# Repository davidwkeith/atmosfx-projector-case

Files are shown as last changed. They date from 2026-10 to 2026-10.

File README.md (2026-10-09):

# AtmosFX projector case

Parametric [OpenSCAD](https://openscad.org) design for a ground-standing, rain-proof (not sealed), ventilated case that holds a mini projector and a Raspberry Pi 3 running an [AtmosFX](https://atmosfx.com) Halloween effect.

**Status: v0.10 (unreleased), design only. Nothing has been printed or wired yet.** Dimensions assume a typical mini projector (about 171 x 134 x 75 mm, 0.72 kg). Measure yours and edit the parameters before printing.

## Features

- Anchors: sealed stake tubes inside the four corners take 8 mm tent stakes, driven from inside with the lid off. With the lid screwed on (use security screws) they can't be pulled, which deters theft and holds the case against wind.
- Sits on the ground on eight 6 mm ribs running front to back (the outer two under the side walls); the channels between them drain rain and carry the speaker wire.
- Projector rides on an internal ball head (pedestal takes a 1/4-20 stud). Usable aim +/-10 deg pan and +/-11 deg tilt, +/-8 deg both at once, with the image clearing the window (checked by `scripts/check_clash.sh` for the Tkisko TO2's 0.95:1 throw). For more, turn the whole case or shim its feet.
- Aim hatch on the left wall, a 45 deg diamond so it prints without supports. Tool-free, unless you fit the optional lock screw for public-facing setups: lift the cover about 8 mm off its four keyholes, loosen the ball head, aim, lock. Lid stays on.
- Sloped lid with no holes in the roof (it screws on through the side skirt), a front visor, drip lip and a 45 deg scarf joint at the seam (the front half laps over the rear like a shingle); 45 deg louvers shed rain. Cooling is passive: the projector's own fan draws air in through a louver bank on the right wall's rear and out through one at its front, with a lip baffle between them, and one more louver vents the Pi zone; every bank is insect-screened. The Pi watches its own temperature and switches the projector off at a critical temperature.
- Acrylic lens window in a rebate, held by a printed frame.
- Pi compartment behind a divider. The Pi rides on a removable sled: one per generation (Pi 3B/3B+, 4B, 5, Zero 2 W), located by two floor pins and held by one M3 thumbscrew. Lid off, shelf out, sled lifts out. A pass-through in the divider, open down to the sled, takes a straight HDMI plug from the Pi (the cable loops under the projector) and the projector power lead.
- One supply: a 24 V 5 A desktop brick lies on the power shelf. A standard molded AC cord comes in through a rear-wall opening closed by a two-piece printed clamp (`cord_clamp`) and plugs into the brick, so nothing is hand-wired on the AC side. A Y-splitter feeds the projector (once bring-up shows it runs on 24 V, otherwise through a buck converter to 21 V) and the Raspberry Pi DigiAMP+ HAT, which powers the Pi.
- DMX: the Pi is a first-class E1.31/sACN fixture (8 channels: power, mode, clip, scare trigger, volume, mute, dimmer, reserved), so xLights, Falcon Player, Vixen or QLC+ can run it as part of a show. DMX takes over while its signal is present; the schedule, Home app and web page take back control when it stops.
- Motion sensor: an HC-SR501-style PIR looks out the rear wall (toward people approaching from the street) under a 45 deg rain hood, for startle scares. A remote sensor on a cable can come in through the floor chimney instead. Scares can also be fired from any Apple Home automation.
- Sound: the DigiAMP+ (stereo class D, 12-24 V) sits on the Pi and drives speakers placed behind the projection over ordinary speaker wire. The wire leaves through a chimney in the floor, which stands 15 mm above the floor so water can't reach it, then runs out under the case between the feet.
- Front/rear split so every piece fits a 250 x 210 x 210 mm bed (Prusa MK3S).

## Build

```sh
brew install --cask openscad@snapshot   # or your OpenSCAD of choice
make parts                              # writes stl/*.stl
scripts/check_clash.sh                  # interference checks (needs python3)
```

CI builds the STLs, runs the interference checks and runs the Pi tests on every push (Actions > Build STLs; STLs are under artifacts). A `v*` tag also builds the Pi image and attaches everything to a GitHub Release.

Preview in OpenSCAD: open `projector_pi_case.scad`, set `part` and `tile` in the Customizer. `part = "assembly"` shows everything with ghosted projector and ball head. On iOS, the [OpenSCAD Playground](https://github.com/openscad/openscad-playground) works in Safari.

## Repository layout

- `projector_pi_case.scad` - the model (all parts via `part` / `tile`)
- STLs and the Pi image: download them from the repository's Releases (CI builds and attaches them for each version tag), or run `make parts` to write the STLs to `stl/`. Flashing the image: `pi/README.md`, Install.
- `docs/` - design log, [printing plan](docs/PRINTING.md), [bill of materials](docs/BOM.md), [assembly](docs/ASSEMBLY.md), [wiring](docs/WIRING.md), [aiming](docs/AIMING.md)
- `preview/` - renders of the assembly, interior, aim hatch and power shelf
- `scripts/` - `check_clash.sh`, `render_previews.sh`, `publish.sh`
- `docs/DESIGN_LOG.md` - decisions, dead ends, references
- `CLAUDE.md` - context for Claude Code (`cd` here and run `claude`)

## Parts and print notes

| File | Notes |
|---|---|
| `base_front` | 231 x 207 mm: lies flat as exported, wide side along the 250 mm bed axis; no skirt |
| `base_rear` | Pi compartment. Joins `base_front` with 4x M3 x 12 screws through the divider into its collars; silicone the joint faces |
| `lid_front`, `lid_rear` | Already flipped roof-down; `lid_front` (228 x 204 mm) lies flat as exported. Seal the scarf joint with silicone |
| `window_frame` | Holds the acrylic pane |
| `pedestal` | Screws to the floor bosses; carries the ball head |
| `hatch_cover` | Print ribs-up |
| `power_shelf` | Holds the brick: strap, zip-tie and wire slots |
| `cord_clamp` | Two halves; clamps the AC cord's jacket at the rear-wall opening (M3 x 16 into the bosses, foam gasket) |
| `exhaust_cap`, `intake_cap`, `vent_cap` (print 1 each) | Insect-screen caps for the three right-wall louver banks (exhaust, rear inlet, Pi vent). Glue screen inside the plate, then screw on with 2x M2 |
| `ir_holder` | Only for the relay + IR projector-power fallback. Stick it near the projector's IR receiver with VHB tape |
| `sled_pi3`, `sled_pi4`, `sled_pi5`, `sled_zero2w` | Print the one for your Pi. The name is engraved on the plate |

Everything prints without slicer supports. The window opening has two thin snap-out ribs that hold up its top edge while printing; break them out afterwards.

Material: PETG or ASA, not PLA. Colour: Disney's ["Go Away Green"](https://en.wikipedia.org/wiki/Go_Away_Green), the muted grey-green the parks use to make infrastructure disappear. It's a family of shades with no published spec, so choose a matte sage or olive grey-green by eye against the spot where the case will sit. ASA holds its colour better in sun than PETG. Test first: print `pedestal` and `window_frame`, then `hatch_cover`, before the big tiles.

## Bill of materials

Full list with quantities: [docs/BOM.md](docs/BOM.md). Assembly order: [docs/ASSEMBLY.md](docs/ASSEMBLY.md).

## Aiming

1. Set the case roughly toward the target.
2. Lift the hatch cover about 8 mm and pull it off, loosen the ball head lock, move the projector while watching the image, lock it.
3. Hang the cover back on.

Full steps, aim limits and troubleshooting: [docs/AIMING.md](docs/AIMING.md).

## Power and safety

Mains is still inside a printed box (the cord's connector and the brick's inlet), but nothing is hand-wired. Feed it from a GFCI outlet, leave a drip loop below the clamp, prove the clamp takes the pull (BRINGUP row 17a) before the lid goes on, keep every plug joint in a weatherproof box and off the ground, and use PETG or ASA (V-0 PETG for the shelf). The brick must be UL/ETL listed: check its label. Accepted by the owner (2026-10-08): no AC fuse, no barrier, and a cord that is not outdoor-rated, for the Halloween 2026 run (about a month outside) and replaced if damaged. Do not connect the projector to the 24 V brick until BRINGUP row 4a passes. If you are not comfortable with mains, have someone qualified do that part. The case is rain-shedding and ventilated, not waterproof or certified. Wiring diagrams, wire gauges and a pre-power-up checklist: [docs/WIRING.md](docs/WIRING.md).

## Roadmap

- Print and fit-check the small parts, then the tiles
- Confirm real projector dimensions, lens position, socket position and vent locations
- Re-measure louver openings against the real projector vents

## Changelog

- v0.9 (unreleased): sized to the Tkisko TO2 (lens on the long face, 0.95 throw), front tiles print end-on, pan and combined-aim limits, receptacle plate on the power shelf for the stock wall-wart plus a second one (the brick cradle is gone), gland beside the plate, Pi zone 85 mm, wall-wart clash check
- v0.8: light-cone check, taller 4 x 5 in window set high for upward tilt, shorter visor, skirt notch, plug clearance behind the projector, fit-test coupon, interior stake tubes, lid screws moved from the roof to the skirt sides, screwed base seam, insect-screen caps, second fan for the Pi/brick zone, shelf vents, support-free printing (ribbed floor, diamond hatch, snap-out window ribs, gabled pass-through), IR LED holder, rear-wall PIR mount, Pi sleds for 3B/3B+/4B/5/Zero 2 W, audio (Amp4 HAT, floor chimney for speaker wire, shelf raised 5 mm), 3 x 5 in stock acrylic pane (wider window), AC gland above the shelf, taller barrier, keyholes flipped to lift off, lid scarf joint and gasket land, larger front/rear gaps so the aim range actually clears
- v0.7: DC brick inside on the power shelf, barrier, heat louvers
- v0.6: low-voltage DC splice, zip-tie shelf
- v0.5: single power cord, power shelf on ledges
- v0.4: quick-aim hatch, floor intake, rain hood
- v0.3: resized for a real mini projector, front/rear split
- v0.2: ground-standing, ball-head pedestal
- v0.1: first parametric sketch

## License

Designs, STLs and documentation: [CERN Open Hardware Licence Version 2 - Strongly Reciprocal](LICENSE) (CERN-OHL-S-2.0). Software in `pi/`: [MIT](pi/LICENSE).

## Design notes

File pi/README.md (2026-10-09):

# VideoFX: the Pi side of the projector case

Raspberry Pi software for the projector case. The sled can be a Pi 3B/3B+, 4B, 5 or Zero 2 W, each with a Raspberry Pi DigiAMP+ amplifier HAT. The Pi shows up in Apple Home (or any Matter controller) as **VideoFX-XXXX**:

- **Loop mode** plays a playlist full screen, over and over, for example the AtmosFX videos you bought.
- **Scare mode** loops a calm clip, and on a trigger plays a scare clip, then goes back to the calm clip. A trigger can be a Home automation, the PIR motion sensor, DMX or the web page.

It also:

- switches the projector over HDMI-CEC, a relay (plus IR) or the HDMI signal;
- follows a weekly schedule with "on at sunset";
- takes DMX over sACN from show software;
- watches the Pi's own temperature and switches the projector off if it overheats (the projector's fan does the case cooling).

A web page on your LAN (`http://videofx-xxxx.local/`) handles videos, the playlist, scare clips, the schedule and every setting.

**Status: untested on hardware.** The logic is unit tested (464 tests). The whole service was run on a Mac against a fake mpv, with real UDP sACN. Nothing has run on a Pi, the image has not been built, and nothing has been paired with Apple Home. See [What is verified](#what-is-verified).

## How it works

- **Names.** On first boot each Pi names itself from the last 4 hex digits of its MAC (eth0, or wlan0 on a Zero 2 W). The display name is `VideoFX-ABCD`: Matter, page title, Bonjour. The hostname is `videofx-abcd` (`videofx-abcd.local`).
- **Matter endpoints**, from [matter.js](https://github.com/matter-js/matter.js) 0.17.9 on Node 24:
  1. **Projector** (On/Off plug): the main power.
  2. **Scare** (On/Off plug): turning it on fires a scare. It stays on while the scare plays, then turns itself off. If the scare can't fire (off, not in scare mode, cooling down) it goes straight back off.
  3. **Motion** (Occupancy sensor, PIR): so Home automations can use the PIR.
  4. **Temperature** (Temperature sensor): the Pi's SoC temperature, so Home can alert on it.
- **Player.** One long-lived **mpv** with DRM/KMS output and no desktop, controlled over its JSON IPC socket (`/run/videofx/mpv.sock`). Changing videos is a playlist command, not a process restart, so there is no black gap. If mpv crashes it is restarted; after more than 5 crashes in a minute the service gives up and reports "off". Off means mpv stops (it idles and releases the screen) and the console is cleared to black. Until the Pi is paired, the console shows the pairing QR code.
- **Who controls the power.** Matter, the web page, the schedule and the restore-after-power-cut all go through one path. While a DMX source is live, only DMX may change the power (see [DMX](#dmx-sacn)). Thermal protection can always switch off.
- **Services.** `videofx-player.service` runs `/opt/videofx/src/main.js` as an ordinary user: `videofx` on the release image, your login user with `pi/config` or `install.sh`. It has the groups video, render, audio, tty and gpio, and `CAP_NET_BIND_SERVICE` for port 80. It never runs as root. `videofx-hostname.service` runs on first boot only. Avahi publishes the name and the web page.

## Supported boards

One arm64 image and one `install.sh` cover all four sleds. pi-gen installs both kernels (`linux-image-rpi-v8` and `linux-image-rpi-2712`), and the firmware picks the right one.

| Board | Projector on | DRM connector | Decoding | DigiAMP+ powering the Pi |
|---|---|---|---|---|
| Pi 3B / 3B+ | the only HDMI port | `HDMI-A-1` | H.264 in hardware up to 1080p30 (V4L2 M2M) | Raspberry Pi: "designed to work with Raspberry Pi 3 and earlier"; 5.1 V at 2.5 A over the header. Not tested here |
| Pi 4B | **HDMI0**, next to USB-C | `HDMI-A-1` | H.264 and HEVC in hardware | Raspberry Pi: on a Pi 4 "or later", use a powered USB hub so the ports add no load. Not tested here |
| Pi 5 | **HDMI0**, next to USB-C | `HDMI-A-1` | **no H.264 hardware decoder**: software (about 10-20% CPU for 1080p24 per Raspberry Pi); HEVC in hardware | 2.5 A is well under the Pi 5's 5 A budget; Raspberry Pi only promises the Pi 3. Not tested; see below |
| Zero 2 W | mini-HDMI | `HDMI-A-1` | as the Pi 3; only 512 MB RAM, so use 720p | any 40-pin board per Raspberry Pi; draws far less. Not tested. Solder a 40-pin header |

Sources: Raspberry Pi's [video playback page](https://github.com/raspberrypi/documentation/blob/master/documentation/asciidoc/computers/os/playing-audio-and-video.adoc) (connector names), its [BCM2712 page](https://github.com/raspberrypi/documentation/blob/master/documentation/asciidoc/computers/processors/bcm2712.adoc) (Pi 5 decoding) and [power supply page](https://github.com/raspberrypi/documentation/blob/master/documentation/asciidoc/computers/raspberry-pi/power-supplies.adoc); Raspberry Pi's [DigiAMP+ product brief](<https://pip-assets.raspberrypi.com/categories/765-raspberry-pi-digiamp/documents/RP-008138-DS-1-digiamp-plus-hat-product-brief.pdf>) (power, dimensions, 0-50 °C operating range), [product page](https://www.raspberrypi.com/products/digiamp-plus/) and [audio HAT docs](https://www.raspberrypi.com/documentation/accessories/audio.html) (Pi model notes, mute GPIO, overlay parameters).

- mpv is pinned to `--drm-connector=HDMI-A-1` (the **Video output** setting), so on a Pi 4B or 5 use **HDMI0**. The option name was checked against the mpv 0.40 manual.
- mpv runs with `--vo=gpu --gpu-context=drm --hwdec=auto-safe`. mpv's docs don't list the Pi's V4L2 decoder in `auto`'s whitelist. If a Pi 3 or Zero 2 W struggles, add `--hwdec=v4l2m2m-copy` under Settings > Advanced (not verified).
- **Pi 5 power is a hardware decision for you.** A Pi 5 wants 5 V/5 A over USB-C PD. The GPIO header can't negotiate PD, and the DigiAMP+ supplies 5.1 V at 2.5 A. If `vcgencmd get_throttled` isn't `0x0` or it reboots under load, use a Pi 4B sled; don't add a second 5 V supply, Raspberry Pi says not to power the Pi's own input while the DigiAMP+ is fitted. The software doesn't work around it.
- **config.txt:** the audio, IR and relay lines are the same on every board and go in `[all]`. Older installs also had overlays for the since-removed fans and temperature sensors; `setup.sh` removes that block.

## Files

```
pi/
  src/main.js          wiring: Matter endpoints, power path, player, projector, DMX, heat, web
  src/config.js        every setting: variable, default, validation, when it applies; GPIO pin checks
  src/settings.js      settings.json store: precedence, password rules, migration
  src/player.js        playback control over mpv IPC: loop, scare mode, clip select, dimmer, mirror
  src/mpv.js           mpv arguments, extra-options allow-list, JSON IPC client, supervisor
  src/display.js       HDMI connector status: playback waits for the projector to appear
  src/schedule.js      weekly schedule, NOAA sunset, scheduler
  src/projector.js     projector power: cec / relay-ir / relay / hdmi-off / none
  src/ir.js            IR codes: validate, learn (NEC decode or raw), send with ir-ctl
  src/gpio.js          relay output via gpioset
  src/pir.js           PIR input via gpiomon
  src/dmx.js           sACN (E1.31) receiver, merge, fixture map, DMX hand-over
  src/thermal.js       SoC temperature watch and over-temperature guard
  src/fsutil.js        durable atomic writes (temp, fsync, rename, fsync dir)
  src/watchdog.js      systemd READY/WATCHDOG pings
  src/system.js        clock sync, Wi-Fi link, power-cut protection status
  src/quiet.js         quiet hours: windows, volume cap, scare gate
  src/backup.js        backup / staged restore
  src/update.js, update-cli.js   version, release lookup and download for videofx-update
  src/media.js, playlist-core.js, web.js, qr.js, screen.js, volume.js
  public/              web page (plain HTML/CSS/JS)
  system/              systemd units, udev rules, avahi service, asound.conf, videofx.default, setup.sh,
                       videofx-storage (+ .service), videofx-maint, videofx-update (+ resume service),
                       NetworkManager/timesyncd/watchdog config
  tools/make-release.sh  release tarball for GitHub Releases
  image/               pi-gen build (build.sh, stage-videofx/)
  dmx/DIY-VideoFX-Player.qxf   QLC+ fixture
  tools/sacn-send.mjs  tiny sACN sender for testing; gen-default.mjs regenerates videofx.default
  test/                Vitest (464 tests), test/fixtures/fake-mpv.mjs
  install.sh, config.example
```

## Install

**Option A: the release image.** Every [release](https://github.com/davidwkeith/atmosfx-projector-case/releases) carries `videofx-<version>-arm64.img.xz` (Raspberry Pi OS Lite 64-bit with the player baked in, built by CI from `pi/image/build.sh --generic`) and `videofx-imager.json`. The image holds no password, SSH key or Wi-Fi; [Raspberry Pi Imager](https://www.raspberrypi.com/software/) (2.0 or newer) puts yours in on first boot through cloud-init, the same way it sets up Raspberry Pi OS trixie:

1. Imager > **App options** > **Content repository** > **Custom URL**: `https://github.com/davidwkeith/atmosfx-projector-case/releases/latest/download/videofx-imager.json`. Imager reloads with "VideoFX projector player" as its only OS.
2. Pick it and the card, then fill in the usual options: user and password, Wi-Fi and country, SSH, locale. The hostname field is ignored: the Pi names itself `videofx-xxxx` anyway.
3. Boot. One extra reboot (storage setup, below), then `videofx-xxxx.local` answers.

Imager's **Use custom** button offers no first-boot options for a plain image file (Imager 2.0 removed them; the repository JSON is the supported way). Without the repository, flash the `.img.xz` with **Use custom**, then edit `user-data` and `network-config` on the card's boot partition before the first boot; both carry commented examples. A Pi booted with no user set up cannot be logged into at all: no password, and the console login is off.

The service runs as the baked-in `videofx` user. Name your Imager user `videofx` to keep one account (Imager then sets its password and SSH key), or pick any other name; both get sudo.

**Option B: build the image yourself.** Your user, password, SSH key and Wi-Fi are baked in, so there is no first-boot setup. Never share this image. You need Docker ([Docker Desktop](https://docs.docker.com/desktop/) on a Mac), git, rsync, uuidgen and node.

```sh
cp pi/config.example pi/config   # user, password, SSH key, Wi-Fi, country; gitignored
pi/image/build.sh                # pi-gen arm64 pinned to one commit; image in pi/deploy/videofx-<version>-arm64.img.xz
pi/image/build.sh --generic      # the public flavour CI builds (no pi/config needed)
```

Flash it with Imager's **Use custom** (no options are offered, none are needed). pi-gen and npm are pinned; Debian and NodeSource packages are whatever is current on build day.

**Fresh card, either way.** Flash the image onto the card and let that card's first boot run: `videofx-storage` grows the root to `ROOT_SIZE_MB` and makes the data partition from the rest, and Pi OS's own grow-to-fill is disabled. Don't copy files onto an existing Pi OS card to "upgrade" it, and don't boot the freshly flashed card in another Pi first. A card whose root already fills it reports `no-space` and runs unprotected; re-flash it.

**Option C: install on stock Raspberry Pi OS Lite (64-bit).**

```sh
scp -r pi/ you@raspberrypi.local:videofx-setup
ssh you@raspberrypi.local 'cd videofx-setup && sudo ./install.sh && sudo reboot'
```

`setup.sh` does the following (both options):

- installs `mpv gpiod v4l-utils alsa-utils avahi-daemon`, plus Node 24 from NodeSource if the system Node is older than 20.19;
- installs the app, udev rules for CEC, lirc, GPIO and fb blank, and the systemd units;
- disables the tty1 login prompt;
- edits `config.txt` (see [GPIO pins](#gpio-pins-and-wiring)). It is idempotent.

## Reliability

The case lives on an outdoor extension cord that will get unplugged.

### Power-cut safety

- **Read-only root.** The system partition runs read-only under an overlay. Changes go to RAM and vanish at reboot, so a power cut can't corrupt the OS.
  - It uses Debian's `overlayroot`, the same mechanism as `raspi-config nonint do_overlayfs` on trixie. That was checked in raspi-config's trixie source.
  - The kernel flag is `overlayroot=tmpfs:recurse=0`. raspi-config uses the default `recurse=1`, which would also make the data partition read-only, so writes to it would vanish at reboot (checked in overlayroot's docs).
  - The overlay needs at least 512 MB of RAM (raspi-config's own limit), so the Zero 2 W just qualifies.
- **Data partition.** `/srv/videofx` is ext4, labelled `videofx-data`. It holds everything that must persist, through bind mounts:
  - `/var/lib/videofx`: settings, Matter pairing, last power state;
  - `~/media`: videos and the playlist;
  - `/var/lib/systemd/timesync`: the saved clock.
- **Mount options:** `noatime,commit=5,errors=remount-ro` in the default `data=ordered` mode, with fsck at boot (fstab pass 2; `fsck.repair=yes` is already on `cmdline.txt`).
  - Why not `data=journal`? Every write here, from us, matter.js or timesyncd, is write-temp-then-rename. `data=ordered` plus ext4's `auto_da_alloc` puts the data on disk before the rename is committed, so a power cut leaves the old file or the new one.
  - `data=journal` would write every multi-GB video upload twice (slower, more SD wear) without adding safety for that pattern.
  - `commit=5` bounds loss to 5 s for anything not fsynced; `errors=remount-ro` stops writing on corruption.
- **Our own writes** (settings.json, player state, playlists, uploads) all go: temp file, fsync, rename, fsync of the folder (`src/fsutil.js`).
- **Sizes.** On first boot `videofx-storage` grows the root partition to `ROOT_SIZE_MB`, makes the data partition from the rest of the card (at least `DATA_MIN_MB`), turns the overlay on and reboots once. Both sizes are in `pi/config`; defaults 6144 and 1024. The image disables Pi OS's own "grow root over the whole card" (`resize` / `rpi-resize`).
- **install.sh on an existing Pi:** Pi OS has usually already grown root over the whole card, and a mounted root can't shrink, so the page reports "no-space" and protection stays off. Fix: flash a fresh card, and before its first boot remove the word ` resize` from `cmdline.txt` on the boot partition. Then run install.sh.
- **OS updates: maintenance mode.**

  ```sh
  sudo videofx-maint on && sudo reboot      # root writable; the page shows a warning banner
  sudo apt update && sudo apt full-upgrade  # or edit /etc/default/videofx, Wi-Fi, ...
  sudo videofx-maint off && sudo reboot     # protected again
  videofx-maint status
  ```

  With the overlay on, edits to `/etc` (including `/etc/default/videofx` and NetworkManager Wi-Fi profiles) are lost at reboot. Use maintenance mode for those, or the web page, whose settings live on the data partition.
- **Logs** are kept in RAM while protected. `journalctl` works until the next reboot.

### Time (no RTC)

The Pi 3, 4 and Zero 2 W have no real-time clock, so after a power cut the clock starts wrong.

- **Gating.** The schedule and sunset don't act until `systemd-timesyncd` has synchronised (it touches `/run/systemd/timesync/synchronized`, per its man page). Until then the page says **"Time not synced"**. When sync arrives, the schedule plans from the real time and doesn't replay what it missed.
- **Monotonic clock.** timesyncd saves the time to `/var/lib/systemd/timesync/clock` and never boots behind it. That file is on the data partition, so it survives the read-only root. This is the built-in equivalent of fake-hwclock, which Pi OS Lite doesn't ship.
- **Servers.** NTP servers from DHCP come first, then `pool.ntp.org`. NetworkManager passes DHCP option 42 to a dispatcher script (`DHCP4_NTP_SERVERS`), which writes a runtime timesyncd drop-in. On UniFi, set it in the network's DHCP options under **NTP Server (Option 42)** ([UniFi DHCP Server](https://help.ui.com/hc/en-us/articles/360012097513-UniFi-DHCP-Server)). The gateway's own address works if it serves NTP.
- **Pi 5 (optional):** it has an RTC. Add the official rechargeable battery on the **J5** connector to keep time across power cuts, and enable charging with `dtparam=rtc_bbat_vchg=3000000` in config.txt ([Raspberry Pi RTC docs](https://github.com/raspberrypi/documentation/blob/master/documentation/asciidoc/computers/raspberry-pi/rtc.adoc)). Don't fit a non-rechargeable cell. The time gate still applies.

### Wi-Fi

- **Power save is off** (NetworkManager `wifi.powersave=2`); it causes latency spikes and missed mDNS/Matter traffic.
- **Ethernet is preferred** when plugged in (route metric 100 vs 600), and Wi-Fi stays up as a fallback.
- The page shows the SSID, signal (dBm and %), a verdict and the band.
- **Bands:** the Pi 3B+, 4B and 5 are dual-band (2.4/5 GHz). The **Pi 3B and Zero 2 W are 2.4 GHz only** ([Raspberry Pi specs](https://github.com/raspberrypi/documentation/blob/master/documentation/asciidoc/computers/raspberry-pi/introduction.adoc)), so the SSID must offer 2.4 GHz.
- **UniFi placement.** An outdoor case sits at ground level, often behind a wall, so give it a real AP view: an outdoor AP or a window-facing one, or Ethernet if you can. Aim for better than **-70 dBm** at the Pi. Ubiquiti's guide calls -60 to -70 acceptable and warns of drops below -80 ([WiFi Troubleshooting Guide](https://help.ui.com/hc/en-us/articles/32064585817495)). Caveats:
  - **Minimum RSSI** disconnects clients below a threshold, and some devices refuse to reconnect after being kicked repeatedly ([Minimum RSSI](https://help.ui.com/hc/en-us/articles/221321728-Understanding-and-Implementing-Minimum-RSSI), [SSID settings](https://help.ui.com/hc/en-us/articles/32065480092951-UniFi-WiFi-SSID-and-AP-Settings-Overview)). Leave it off on the APs that cover the case, or set it well below the Pi's signal.
  - **Band Steering** nudges clients from 2.4 GHz to 5 GHz with BSS transition frames. At the edge of coverage 2.4 GHz often reaches further. If a dual-band Pi keeps hopping, give it a 2.4 GHz-only SSID; a 3B or Zero 2 W ignores steering anyway.

### Hang recovery

- **Hardware watchdog:** `RuntimeWatchdogSec=14s` in `/etc/systemd/system.conf.d/`. systemd pets the Broadcom watchdog, and if the kernel or systemd hangs the board resets. 14 s stays under the chip's roughly 15 s limit.
- **Service watchdog:** `videofx-player` is `Type=notify` with `WatchdogSec=30`. It sends `READY=1` once its own start-up is done (not when Matter comes online: with the Wi-Fi down that may never happen, and systemd would restart it every 2 minutes), then `WATCHDOG=1` every 15 s from the main event loop, but only while healthy. It stops pinging if the loop was blocked for more than 5 s, and systemd then restarts it.
- Node can't write to the notify socket without a native addon, so pings go through `systemd-notify` with `NotifyAccess=all`. Crediting that short-lived helper's message to our unit needs kernel ≥ 6.5 and systemd ≥ 254, which trixie has; on older systems the pings may be lost. At most one helper runs at a time.

### Updates

VideoFX never updates itself, and the web page never touches the network. With the read-only root, updates go through maintenance mode, which `videofx-update` handles:

```sh
sudo videofx-update --check                   # asks GitHub; the page then shows "update available"
sudo videofx-update                           # latest release
sudo videofx-update --tag v0.3.0 --os         # a given release, plus apt full-upgrade
sudo videofx-update --tarball ~/videofx-pi-0.3.0.tar.gz   # no GitHub access needed: scp the tarball over first
sudo videofx-update --rollback                # back to the previous version
```

- **What it does:**
  1. If the root is protected, it records the job and any tarball on the data partition, switches maintenance mode on and reboots. `videofx-update-resume.service` picks the job up after the reboot.
  2. Downloads the release asset `videofx-pi-X.Y.Z.tar.gz` and checks it's VideoFX.
  3. Copies the running version to `/opt/videofx.prev` (with its `node_modules`, so a rollback works offline).
  4. Runs the new release's `system/setup.sh`, which does `apt-get install`, `npm ci --omit=dev`, units and config. Both need the internet, with `--tarball` too.
  5. With `--os`, runs `apt full-upgrade`.
  6. Switches maintenance off and reboots.
  7. If step 4 fails (no network, say), it puts the previous version back, switches protection back on, reboots and exits with an error. It doesn't retry.
- **Private fork:** if your copy of the repo is private, put a GitHub token with read access to its contents (a fine-grained token, "Contents: read") in `/srv/videofx/update/github-token`, mode 600, owned by root. It lives on the data partition so it survives the read-only root. Or use `--tarball`.
- **Making a release:** bump the version in `pi/package.json`, tag `vX.Y.Z` and push the tag. CI (`.github/workflows/build.yml`) attaches the STLs, `videofx-pi-X.Y.Z.tar.gz` (`pi/tools/make-release.sh`), the public image with its `.sha256`, and `videofx-imager.json` (`pi/tools/imager-json.sh`). The image job runs on GitHub's arm64 runner and takes about ten minutes. By hand: `pi/tools/make-release.sh && gh release create vX.Y.Z pi/dist/videofx-pi-X.Y.Z.tar.gz`. The page footer shows the version and sha, and "update available" when the last `--check` found a newer release.

### Backup and restore

Web page > **Backup** > **Download backup**. That's one JSON file with the settings, schedule, quiet hours, playlist, and the Matter storage (fabrics, keys). Videos aren't included; copy those yourself. The file holds the pairing keys and the password hash, so keep it private. When a password is set, downloading needs it.

**Restore:** pick the file, choose whether to include the Matter pairing, confirm. Settings and playlist apply straight away and the service restarts. A restored pairing is swapped in at that restart, and the previous one is kept as `matter.before-restore`.

- Restore the **pairing** only onto the same Pi, or onto a replacement when the old one is gone for good. Two devices with one Matter identity confuse Apple Home and both misbehave.
- To clone settings onto a second VideoFX, restore **without** the pairing and pair the new one separately.

### Guest access

With no password set, the page shows a warning: anyone on your network can control VideoFX and download its pairing keys.

- Set a password, and keep the Pi off networks that guests can reach. On UniFi that means a separate guest network with **Network Isolation** on (Settings > Networks) and, on its SSID, **Client Device Isolation**, as in Ubiquiti's [Guest WiFi best practices](https://help.ui.com/hc/en-us/articles/23948850278295-Best-Practices-Guest-WiFi). Keep VideoFX on your own network with the home hub, since it must share one with Matter.
- Once paired, the page hides the Matter pairing code (Settings > Web page > **Hide the Matter pairing code once paired**, on by default).
- "LAN only" means the usual private ranges plus anything on one of the Pi's own subnets. The second part is for IPv6: on a network with a routed prefix every device has a global address, and iPhones and Macs use it for `videofx-xxxx.local`.
- Password guessing is slowed down: five new guesses, then one a second. A tab that keeps polling with an old password doesn't use them up.
- The service can't write to the home folder apart from the media folder (`ProtectHome=read-only`). If you move the media folder elsewhere under `/home` with `VIDEOFX_MEDIA_DIR`, add a matching `ReadWritePaths=` to the unit.

### Quiet hours

Web page > **Quiet hours**: per weekday, a window (an end earlier than the start runs past midnight; start = end means all day) during which:

- **the volume is capped** at a percentage (0 mutes). The cap applies to the web slider, the saved level at start-up, and DMX (unless **DMX ignores quiet hours** is on). The mixer is re-set when a window starts or ends;
- **scares are off** (optional), whatever the trigger: Home's Scare switch, the motion sensor, the web button, and DMX unless it bypasses.

Power on/off (Home, the schedule) isn't affected. Until the clock is synchronised, quiet hours count as active if any window is set, the neighbour-friendly guess.

## Videos, playlist, scare mode

Your purchased videos are not included or downloaded. Upload them on the web page, or `scp` them to `~/media/` on the Pi.

- **Loop mode:** build the playlist on the page (order, enable/disable, save). Saving while playing reloads it in mpv.
- **Scare mode:**
  1. Upload the calm clip and the scare clips. Files named like `Ghost_Buffer.mp4` and `Ghost_Scare1.mp4` get paired by **Suggest from file names**.
  2. Pick the calm clip and the scare clips in **Scare mode**, and save.
  3. Set Settings > Playback > **Mode** to `scare`.
  4. Tune the order (sequential/random), the cooldown (default 20 s, counted from the end of a scare), and what happens to a trigger during a scare: `ignore` (default) or `queue` (one scare, played after the cooldown).
  5. Trigger with **Scare now**, the **Scare** switch in Home (for example, "when the doorbell rings, turn on Scare"), the PIR, or DMX.
- **The seam.** The calm clip loops with `loop-file=inf`. The next scare clip and the calm clip after it are already queued, so mpv's `--prefetch-playlist` opens them early. A trigger sets `loop-file=no` and sends `playlist-next`. The service measures each seam from mpv's events and logs it (`journalctl -u videofx-player | grep seam`); the page shows it too. **It has not been measured on a Pi:** the Mac test used a fake mpv, whose ~50 ms is its own simulated delay.
- **Recommended encode:** H.264 High, level 4.1 or lower, 1080p30 (720p for the Zero 2 W), 8-bit 4:2:0 MP4, AAC stereo 48 kHz. Re-encode on your computer only if a file stutters:

  ```sh
  ffmpeg -i in.mp4 -vf "scale=-2:'min(1080,ih)',format=yuv420p" -c:v libx264 -profile:v high -level:v 4.1 \
    -preset slow -crf 20 -c:a aac -b:a 160k -ac 2 -ar 48000 -movflags +faststart out.mp4
  ```

  Use `min(720,ih)` and `-level:v 4.0` for the Zero 2 W. For rear projection on a Pi 3 or Zero 2 W, pre-flip the files with `-vf "hflip,scale=..."` instead of using the Mirror setting (below).
- **Mirror** (Settings > Display): flips left-right at once through mpv IPC (`vf add @mirror:hflip`). The flip runs on the CPU, so it switches decoding to `auto-copy`. That's fine on a 4B or 5 and probably too heavy for 1080p on a 3 or Zero 2 W (not measured).

## Schedule

On the page: an on time and an off time per weekday. The on time can be **At sunset**, plus or minus an offset. An off time earlier than the on time means after midnight.

- Sunset is computed on the Pi from Settings > Schedule > Latitude/Longitude, using NOAA's general solar position equations (tested within 5 minutes of published times). Days with no sunset (polar summer or winter) get no on event.
- Times use the Pi's time zone (`sudo raspi-config` > Localisation). Tested across both DST changes: a time in the spring-forward gap fires once, at 03:30; a time in the fall-back hour fires once.
- **The schedule only acts at its event times.** Switching on or off by hand (Home, the page) holds until the next scheduled event. The page shows the next event.
- **After a power cut** the "After a power cut" setting applies first. Then, once the clock is set, an event that passed while the power was out is caught up: a cut across "on at sunset" still gets you a show. A change you made by hand after the last event is left alone.
- A Pi has no real-time clock. Events more than 5 minutes stale, for example after NTP corrects the clock at boot, are skipped rather than replayed.
- While DMX is in control the schedule is paused. When DMX lets go, the schedule's current wish is applied.

## Projector power

Setting: **Projector power** = `cec` (default) | `relay-ir` | `relay` | `hdmi-off` | `none`. The page shows the projector's state and the CEC result.

- **cec.** Uses `cec-ctl` (v4l-utils) on `/dev/cec0`, the kernel's CEC under KMS (HDMI0 on the 4B and 5; the only port on the 3 and Zero 2 W). No libcec daemon, and access is through the video group via udev.
  - On: configure as a playback device, then Image View On, Text View On and Active Source (One Touch Play), then ask for the power status. If the projector isn't "on" yet, the wake is retried once after 8 s.
  - Off: Standby.
  - If the projector never answers, the service falls back to `hdmi-off` with a notice, and tries CEC again at the next power-on. CEC is only used on power changes, never on page polls.
  - **Buying:** many mini projectors have no CEC. Look for "HDMI-CEC" in the projector's own spec. Brand names like Anynet+, SimpLink or Bravia Sync are the TV makers' CEC and don't tell you anything about a projector.
  - **Test** on the Pi: `cec-ctl -d /dev/cec0 --playback -S` shows the CEC devices. `cec-ctl -d0 --to 0 --image-view-on` should wake it.
- **hdmi-off.** Powers the HDMI signal down (fbdev blank) when stopped, once mpv has let go of the display. Many projectors drop to standby after their own no-signal timeout. **Waking may still need the remote.** Before the Pi is paired, the signal stays on so the pairing code is visible.
- **relay / relay-ir.** Fallbacks, built only if CEC fails (BRINGUP row 9). A relay on the projector's DC feed. Off: stop playback, then open the relay. On: close it, wait the settle time (default 3 s), then:
  - `relay`: nothing more, for projectors that power up by themselves.
  - `relay-ir`: send the IR power code (twice if "needs two presses" is set). The relay forces a known "off" first, so the IR toggle can't get out of step. A second "on" while it is already on (the schedule after you switched on by hand, say) doesn't press power again.
  - Either way, playback then waits up to 20 s for the projector to show up on HDMI, and starts again if it appears later. mpv gives a disconnected output no picture.
- **Relay safety:**
  - Use a relay module rated for the projector's DC current, with an opto-isolated input and a flyback diode (most modules have one).
  - Switch the **+ line (high side) only**, and only on the projector's leg. Never switch the projector's ground: the HDMI shield would carry its return current.
  - At boot the firmware drives the relay line to "open" before Linux runs (`gpio=27=op,dh` for active-low modules; use `dl` for active-high). The service keeps it open until it decides.
  - When the service stops, for any reason, the relay opens: the service does it on a clean stop, and `videofx-relay-open` (the unit's `ExecStopPost`) does it after a crash, a kill or the watchdog. The relay never stays closed once the service is gone (the service only watches the Pi's own SoC; the projector has its own thermal cut-off).
  - The relay and IR pins are also in `config.txt`, written once with the defaults. If you change them in `/etc/default/videofx`, change `config.txt` by hand too.
  - Cutting power suits LED mini projectors; don't do it to a lamp projector that needs a cool-down.
- **IR** uses the `gpio-ir-tx` overlay for the LED and `gpio-ir` for a TSOP38238-style receiver, driven with `ir-ctl`.
  - On the page: **Learn power button**, then press the remote's power button at the receiver. The capture is decoded as NEC (`nec`, `necx` or `nec32`, the same scancode forms the kernel's encoder sends) or kept as raw pulse/space data.
  - Or paste a code (`nec:0x40bf`, `rc5:0x1e01`, `raw:+9000 -4500 ...`). **Send test** fires it.
  - `pwm-ir-tx` is allowed (set `VIDEOFX_IR_TX_DRIVER` and use its overlay in `config.txt`): the case has no fans, so hardware PWM0 is free.

## GPIO pins and wiring

**The DigiAMP+ uses GPIO 2 and 3 (I2C), 18-21 (I2S) and 22 (amp mute, driven by the `rpi-digiampplus` overlay)**, per Raspberry Pi's [audio HAT docs](https://www.raspberrypi.com/documentation/accessories/audio.html); [pinout.xyz](https://pinout.xyz/pinout/digiamp_plus) also lists GPIO 4 (GPCLK0), so it stays reserved. The board brings GPIO 17, 23, 24, 25 and 27 to its optional rotary-encoder and IR headers; VideoFX uses those pins, so **leave those headers empty**. GPIO 0/1 are always reserved for the ID EEPROM. That leaves 18 free GPIOs; VideoFX uses 9, so **no expander is needed**. The service refuses two roles on one pin and any DigiAMP+ pin.

| Role | GPIO | Pin | Notes |
|---|---|---|---|
| DigiAMP+ | 2, 3, 4, 18, 19, 20, 21, 22 | 3, 5, 7, 12, 35, 38, 40, 15 | reserved (22 = mute) |
| PIR in | 17 | 11 | setting (live) |
| Relay out | 27 | 13 | file only (boot level in config.txt) |
| IR LED out | 16 | 36 | file only (overlay) |
| IR receiver in | 23 | 16 | file only (overlay) |
| 5 V / 3.3 V / GND | | 2, 4 / 1, 17 / 6, 9, 14, 20, 25, 30, 34, 39 | |

**Reaching the pins.** The DigiAMP+ has a 40-pin pass-through header on top (Raspberry Pi's product page), so the leads above plug straight into it; no stacking header is needed. On the Zero 2 W, which needs a header soldered anyway, leave the pins long.

If you ever need more I/O, an I2C expander (MCP23017) can share GPIO 2/3 with the DigiAMP+'s codec.

**Wiring:**

- **PIR (HC-SR501):** VCC to 5 V (pin 2), GND (pin 9), OUT (3.3 V logic) to GPIO17 (pin 11). Use the retrigger jumper (H), a short hold time, and allow about a minute of warm-up after power-on.
- **Relay module (5 V coil, opto input):** VCC 5 V (pin 4), GND (pin 14), IN to GPIO27 (pin 13). The contacts (COM/NO) go in series with the projector's DC **+** only.
- **IR LED (940 nm), fallback only (built only if CEC fails):** GPIO16 (pin 36; GPIO22 is the DigiAMP+ mute line) drives the LED directly through 150 Ω to GND (about 13 mA at 3.3 V, inside the pin's 16 mA limit). The Pi's default pad drive is 8 mA, so the LED may be dimmer than 13 mA suggests: raise the drive strength, or add the BC337 and 1 k as in WIRING.md.
- **IR receiver (TSOP38238), bench-only (for learning the remote's codes):** VS to 3.3 V (pin 17), GND, OUT to GPIO23 (pin 16). Powering it at 3.3 V keeps its output at 3.3 V.

## Audio

A **Raspberry Pi DigiAMP+** (TAS5756M, 2 channels) drives 4-8 Ω speakers behind the projection. It runs from the Y-splitter's second leg (12-24 V, through its P5 hard-wire header or the 5.5 x 2.5 mm centre-positive barrel jack) and **powers the Pi through the header** at 5.1 V / 2.5 A. Up to 35 W per channel, rated for 0-50 °C ambient ([product brief](<https://pip-assets.raspberrypi.com/categories/765-raspberry-pi-digiamp/documents/RP-008138-DS-1-digiamp-plus-hat-product-brief.pdf>)): the Pi zone has to stay under that with only a passive louver, and the brief says not to cover a case it sits in, which is what the louvers are for (bring-up logs the shelf temperature).

- **Speakers:** speaker wire from the DigiAMP+'s terminals, same polarity on both speakers; the outputs can't be bridged.
- **Power budget:** the brick must supply the projector, the Pi and the amp at once. Check its label.
- **Software:**
  - `dtoverlay=rpi-digiampplus,unmute_amp` (Raspberry Pi's overlay; the HAT EEPROM identifies the board, but the amp starts **muted** until `unmute_amp` or `auto_mute_amp` is set. `iqaudio-digiampplus` is the same overlay for the older black IQaudIO board);
  - `dtparam=audio=off` and `vc4-kms-v3d,noaudio`;
  - ALSA default pinned by card name in `/etc/asound.conf`;
  - mpv uses `--audio-device=alsa/plughw:CARD=RPiDigiAMP,DEV=0` (the card id ALSA derives from the overlay's "RPi DigiAMP+" name; check with `aplay -l`).
- **Volume:** hardware mixer `Digital` via `amixer -M`, saved in settings.json. The first boot starts at 30%.

## Cooling

The case has no fans or temperature sensors: the projector's own fan moves the air through the case's louver banks, and the projector has its own thermal cut-off. The Pi only watches **its own SoC temperature** (`/sys/class/thermal/thermal_zone0`, read every 5 s) and switches the projector off if the Pi itself overheats.

Settings > Cooling:

_Upgrade note: `tempWarnC` / `tempCritC` now refer to the Pi's SoC. A saved `tempCritC` of 55 (the old projector-zone default) would trip during normal operation, so delete the old saved values or set them to 70 / 80._

- **Pi over-temperature protection** (on by default). When off, nothing is checked and nothing is protected.
- **Warning** (default 70 °C, 40-90): banner on the page.
- **Critical** (default 80 °C, 50-95):
  - stops playback and switches the projector off through its configured path, even under DMX;
  - blocks switching on;
  - it switches back on (only if it was on) once the SoC is below critical by the hysteresis.
- **Cool-down before resuming** (default 5 °C, 1-20).
- **What the cut-off can do depends on the projector power mode.** With `relay` or `relay-ir` it cuts the projector's power. With `cec` it asks for standby, which a hung projector can ignore; with `hdmi-off` it only drops the signal; with `none` it only stops playback. The relay is the only way the Pi can really cut the projector's power on over-temperature.
- **A missing reading** (the sysfs file unreadable) changes nothing: no trip, no clear.
- **Matter:** the SoC temperature is endpoint 4.

## DMX (sACN)

VideoFX is a **receive-only 8-channel fixture** over **E1.31 (sACN)**, on Wi-Fi or Ethernet (UDP 5568, unicast and optionally multicast 239.255.hi.lo). Settings > DMX sets: enable, universe (1-63999), start address (1-505), hold time (default 5 s) and accept multicast. The page shows the live sources (name, IP, priority, packet rate) and our 8 values.

| Ch | Function | Values |
|---|---|---|
| 1 | Power | 0-127 off, 128-255 on (same projector power path as Matter) |
| 2 | Mode | 0-127 loop, 128-255 scare |
| 3 | Clip select | 0 = normal (playlist or calm clip); N = playlist entry N, looped |
| 4 | Scare trigger | fires on the rise through 128; the cooldown still applies |
| 5 | Volume | 0-255 → 0-100% |
| 6 | Mute | 128-255 muted |
| 7 | Video dimmer | 0 black … 255 normal (mpv brightness) |
| 8 | Reserved | send 0 |

**Hand-over rules:**

- While any valid source for our universe is live, **DMX owns power, mode, clip, volume, mute and dimmer**.
  - Matter writes are refused, and Matter's attribute is put back to the real state.
  - The page shows "DMX in control" and disables those controls; its power and volume calls get 409.
  - The schedule pauses.
  - DMX values are not saved.
- A source is lost after 2.5 s without data (E1.31 data loss) or at once on Stream_Terminated. After the last source is lost and the hold time passes, control returns:
  - to the schedule's current wish if the schedule is on;
  - otherwise to the power state from before DMX took over.
  - Mode, volume, clip and dimmer go back to their saved settings.
- **Pacing:** power changes at most once a second, mode every 0.5 s, and clip select must hold 300 ms. Volume and dimmer are limited to 10 updates a second.
- **Merging:** highest priority wins; equal top priorities merge highest-takes-precedence per channel. Out-of-order packets are dropped, using ETC's rule: accept if newer, or 20 or more behind. Preview-flagged data and non-zero start codes are ignored.

**Where the E1.31 details come from.** Packet layout, the sequence rule, the 2.5 s timeout, the flags and the universe range were checked against ETC's open-source reference receiver ([ETCLabs/sACN](https://github.com/ETCLabs/sACN)). The ESTA PDF sits behind a terms form and was not read directly.

**Show software:**

- **QLC+:** import `dmx/DIY-VideoFX-Player.qxf` (Fixture Definition Editor, or copy it to your user fixtures folder). It validates against QLC+'s own `fixture.xsd`. Output on E1.31, **unicast** to the Pi's IP.
- **xLights:** Controllers > Add Ethernet, Protocol E1.31, the Pi's **IP address** (unicast), start universe = ours ([xLights manual](https://manual.xlights.org/xlights/chapters/chapter-four-set-up/lighting-networks/ethernet-controller)). Add a DMX model with 8 channels at the start address. The DMX model type's name wasn't verified.
- **Falcon Player:** Channel Outputs > **E1.31 / ArtNet / DDP / KiNet**, add a universe with type **E1.31 Unicast** and the Pi's IP.
- **Manual test:** `node tools/sacn-send.mjs --to <pi-ip> --universe 1 --values 255,0,0,0,76,0,255,0 --seconds 10`. Add `--pulse-trigger` for a scare. It ends with Stream_Terminated.

**Network:** multicast over Wi-Fi is unreliable (converted, rate-limited or dropped by APs), so **send unicast to the Pi's IP**; a fixed IP or DHCP reservation helps. On UniFi, sACN multicast (239.255.x.x) is outside the always-flooded 224.0.0.0/24, so **IGMP Snooping** with "Forward Unknown Multicast" set to Drop can block it, and **Multicast Enhancement** converts it per client ([Switch Settings](https://help.ui.com/hc/en-us/articles/33402927617047-UniFi-Switch-Settings), [WiFi SSID settings](https://help.ui.com/hc/en-us/articles/32065480092951-UniFi-WiFi-SSID-and-AP-Settings-Overview)). Unicast avoids all of that.

## Pair with Apple Home

1. Power on with the projector connected. Until paired, the projector and the web page show the QR code and manual code.
2. On the iPhone (same Wi-Fi as the Pi and your home hub): Home > **+ > Add Accessory**, then scan. If the camera won't read the projector, scan the page or type the 11-digit code.
3. Choose **Add Anyway** at the not-certified warning (test vendor ID 0xFFF1).
4. You get the Projector and Scare switches, a Motion sensor and a Temperature sensor. Name them, and automate, for example: sunset → Projector on; doorbell → Scare on.

To unpair: web page > Matter > **Reset Matter pairing**. Videos and settings are kept.

## Settings

Everything is on the web page under **Settings**. Each setting shows its value, where it comes from (*set here* / *from /etc/default/videofx* / *default*), its default, when it takes effect (at once / next play / after a restart), and a **Reset**.

- **Precedence:** web page (`/var/lib/videofx/settings.json`, written atomically, mode 600) > `/etc/default/videofx` > default. A corrupt settings.json is backed up to `settings.json.corrupt` and ignored, with a warning.
- **Password:** stored as a scrypt hash and never sent back. Changing it needs the current password; removing it needs the current password and a confirmation.
- **Extra mpv options (Advanced):** only `--name=value`, no shell, and only from an allow-list: decoding (`--hwdec`, `--vd-lavc-*`), DRM output (`--vo=gpu|gpu-next|drm`, `--gpu-context`, `--drm-*`, `--drm-device=/dev/dri/cardN`), sync and scaling (`--video-sync`, `--interpolation`, `--scale`, `--deband`, `--video-*`, `--panscan`, picture controls), cache (`--cache*`, `--demuxer-max-bytes`), audio timing (`--audio-delay`, `--audio-buffer`, `--volume-max`, `--alsa-*`), `--profile=fast|sw-fast|high-quality|low-latency`, `--msg-level`, and `--vf` with simple filters (`crop`, `hflip`, `vflip`, `scale`, `pad`, `format`, `fps`, `eq`, `rotate`, `transpose`, `yadif`, `bwdif`). Everything else is refused. A deny-list missed `--ao=pcm --ao-pcm-file=...`, which writes any file the service can.
- **JSON values in `/etc/default/videofx`** (scare clips, schedule, quiet hours) go in single quotes. systemd reads the file, and it drops the quotes inside an unquoted value.
- **File only** (need root, or would let the page point the service anywhere): ports, media folder, playlist path, mpv command, state folder, and the relay and IR pins. Edit `/etc/default/videofx` (every key is listed there, commented) and restart.
- **Migration from the VLC version:** `VIDEOFX_VLC*` in the file and `vlcExtraArgs` in settings.json are ignored, with a warning. VLC options don't translate to mpv; the audio card and video output settings carry over as they are.

### Web page security

- The page answers only private, link-local and ULA addresses.
- The Host header must be an IP, `localhost`, `videofx-xxxx(.local)`, the device name or an extra host name (case-insensitive). This blocks DNS rebinding.
- Every write needs an `X-VideoFX: 1` header (CSRF). The optional password uses basic auth, over plain HTTP.
- Uploads: file names are checked, the size is capped, extensions are limited, and media is never served back.

## UniFi networks

Keep the Pi, the Apple home hub and your iPhone **on the same network (VLAN)**. On the Wi-Fi, turn off **Client Device Isolation** and **Multicast and Broadcast Control** (or add exceptions). Try turning **Multicast Enhancement** off if discovery is flaky. With **IGMP Snooping** on, set **Forward Unknown Multicast Traffic** to flood. Across VLANs you need the gateway's **mDNS Proxy** (add `_matter._tcp.local` in Custom mode) *and* routable IPv6 plus firewall rules for UDP 5540. The Pi sends `videofx-xxxx` as its DHCP hostname.

Sources: [Gateway mDNS Proxy](https://help.ui.com/hc/en-us/articles/12648701398807-UniFi-Gateway-Multicast-DNS-mDNS-Proxy), [Switch Settings](https://help.ui.com/hc/en-us/articles/33402927617047-UniFi-Switch-Settings), [WiFi SSID settings](https://help.ui.com/hc/en-us/articles/32065480092951-UniFi-WiFi-SSID-and-AP-Settings-Overview), [Optimizing WiFi](https://help.ui.com/hc/en-us/articles/221029967-Optimizing-WiFi-Connectivity-and-Reducing-Latency), [Network isolation](https://help.ui.com/hc/en-us/articles/18965560820247-Implementing-Network-and-Client-Isolation-in-UniFi), [Configuring IPv6](https://help.ui.com/hc/en-us/articles/36378535649687-Configuring-IPv6-in-UniFi), [Local DNS records](https://help.ui.com/hc/en-us/articles/15179064940439-UniFi-DNS-Records-and-Local-Hostnames); Apple's [accessory troubleshooting](https://support.apple.com/en-us/126198). help.ui.com blocks scripted fetches, so these were read through its article API; they open normally in a browser.

**mDNS:** matter.js runs its own responder on UDP 5353 (`SO_REUSEADDR`) under a MAC-based name. avahi owns `videofx-xxxx.local` and the `_http._tcp` entry ("VideoFX-XXXX"). They don't share names, so they coexist. A unicast mDNS reply reaches only one of the two sockets; that case is untested.

## Troubleshooting

```sh
journalctl -u videofx-player -f        # everything: player, Matter, DMX, schedule, seams, thermal
cat /var/lib/videofx-name
kmsprint | grep Connector              # HDMI connectors (Pi 5: first card only)
cec-ctl -d /dev/cec0 --playback -S     # is there CEC?
ir-ctl -f -d /dev/lirc0                # IR devices (TX and RX may swap numbers)
aplay -l; amixer -c RPiDigiAMP sget Digital
vcgencmd get_throttled                 # under-voltage (Pi 5 on the DigiAMP+)
```

- **No picture on a 4B or 5:** use HDMI0. **No picture when the projector is powered after the Pi:** playback waits up to 20 s for the HDMI connection and starts again when it appears (`journalctl -u videofx-player | grep HDMI`). If your projector never reports itself connected, add `video=HDMI-A-1:1280x720@60D` to `cmdline.txt`.
- **mpv errors about the DRM device on a Pi 5:** add `--drm-device=/dev/dri/card1` in Settings > Advanced.
- **Stutter on a Pi 3 or Zero 2 W:** re-encode (above), or add `--hwdec=v4l2m2m-copy`.

## License

The software in `pi/` is MIT (see `pi/LICENSE`). The case design in the rest of the repository is CC BY-SA 4.0.

## Development

```sh
cd pi && npm ci && npm test             # Vitest; a few tests bind 127.0.0.1 and a Unix socket
VIDEOFX_MPV=$PWD/test/fixtures/fake-mpv.mjs VIDEOFX_CONSOLE= VIDEOFX_MEDIA_DIR=/tmp/vfx-media \
  VIDEOFX_STATE_DIR=/tmp/vfx-state RUNTIME_DIRECTORY=/tmp/vfx-run VIDEOFX_HTTP_PORT=8080 \
  VIDEOFX_PROJECTOR_POWER=none node src/main.js      # then open http://localhost:8080
node tools/gen-default.mjs > system/videofx.default   # after adding a setting
```

Node 20.19+ to run, 22.12+ for the tests. On macOS keep `RUNTIME_DIRECTORY` short: Unix socket paths are limited to 104 bytes.

## What is verified

**Verified** (Mac, Node 26, `npx vitest run` in `pi/` outside the sandbox, because some tests bind local sockets):

- **464 tests pass.** They cover:
  - the player: loop, scare arm/trigger/re-arm, sequential and random order, cooldown, ignore and queue, off during a scare, seam measurement, command ordering, mirror, clip and dimmer;
  - mpv: the allow-list, the IPC client on a real Unix socket, supervisor crash/restart/give-up;
  - schedule: sunset against published times, polar days, both DST changes, the manual-override rule, stale events, the desired state for the DMX hand-back;
  - projector: the CEC sequence, retry, fallback, relay and relay-IR timing, double press;
  - IR: code validation, NEC decoding (nec, necx, nec32), learn and timeout, send;
  - GPIO: the pin budget and conflicts, the relay holder, PIR debounce and restart;
  - DMX: packet parsing (valid and malformed), universe, preview and terminated flags, sequence wrap, priority and HTP merge, the 2.5 s timeout, hold and hand-over, channel map, pacing, rising-edge trigger, the arbiter refusing Matter writes;
  - thermal: the SoC watch (warning, critical trip, hysteresis, a missing reading), the over-temperature shutdown and resume rule;
  - settings, the web API and all earlier features.
- **matter.js API** checked against the installed 0.17.9 package: `OccupancySensorDevice` + `OccupancySensingServer.with("PassiveInfrared","OccupancyEvent")`, `TemperatureSensorDevice`, a second On/Off endpoint, runtime `server.set({basicInformation:{nodeLabel}})`.
- **mpv** options and IPC commands checked against the v0.40.0 manual source (`--drm-connector`, `--input-ipc-server`, `--prefetch-playlist`, `--audio-device=alsa/...`, `loadfile`/`loadlist`/`playlist-next`/`playlist-clear`/`stop`, `vf add/remove @label`, the `hwdec` values).
- **cec-ctl, ir-ctl and gpiomon/gpioset** options checked against the v4l-utils and libgpiod 2.2 sources. Overlay parameters and the DigiAMP+ GPIO usage checked against Raspberry Pi's overlay README (`rpi-digiampplus`: card name "RPi DigiAMP+", `unmute_amp` / `auto_mute_amp`), its audio HAT docs (mute on GPIO22) and pinout.xyz.
- **Full-service smoke run** against the fake mpv, with real UDP sACN:
  - loop and scare mode;
  - trigger, ignore during a scare, cooldown;
  - mirror through IPC;
  - schedule next-event;
  - DMX takeover (web power and volume refused with 409, live values shown), Stream_Terminated, then hand-back after the hold;
  - the page at phone width.
- The smoke run found and fixed two real bugs: interleaved mpv commands from quick reloads, and banners that ignored `hidden`.
- **Reliability:** durable writes (the call order is tested, and the files were written on disk); watchdog pinging (interval, READY once, stops while unhealthy, no pile-up); schedule gated on clock sync; Wi-Fi and storage-status parsers. Checked against the sources: raspi-config trixie (`overlayroot`), overlayroot's `recurse` option, the timesyncd `synchronized` file and drop-in dirs (systemd v257 man pages), NetworkManager's `DHCP4_*` dispatcher variables and its `ntp_servers` request, the UniFi DHCP option 42, Raspberry Pi board bands and the Pi 5 RTC battery.
- **This round:** quiet hours (windows including past midnight, cap and mute, the DMX bypass, the scare gate for every source, unsynced clock); version compare, release-asset pick and update status; backup create/validate/stage/apply on disk (path traversal and bad content refused, locks skipped, old pairing kept aside); backup and restore routes (attachment, no-store, password, big body, write header). Smoke run: quiet hours active, the scare refused, a backup downloaded, a restore with the pairing refused without confirmation, then staged, then applied on restart.
- **Review round (October):** a failed state save not blocking power-off, relay changes run in order, no second IR press when already on, the relay opening at shutdown, CEC re-configuring until it has a physical address, on-link IPv6 sources, the password guess limit, the free-space reserve and upload clean-up, the schedule's boot catch-up, mpv restarted after it gave up, the HDMI wait. The new tests were run against the old code and fail there.
- **First-boot repartitioning, the risky part:** the grow-and-add-partition block from `videofx-storage` was run as written in a Debian trixie container (parted 3.6, sfdisk 2.41) on a loop disk with partition 2 mounted. The old `parted -s ... resizepart 2` fails there with "Partition is being used" (exit 1), which would have stopped first boot. The `sfdisk` replacement grows the partition, `resize2fs` grows the mounted filesystem, the data partition is made, and both pass `e2fsck`.
- **QLC+ fixture** validates against QLC+'s `fixture.xsd`. **config.txt edits** are correct and idempotent on pi-gen's stock file. shellcheck is clean.

**Untested** (no Pi, no mpv):

- The image build, first boot on each board, and `install.sh` on Raspberry Pi OS.
- mpv on the Pi: DRM output as non-root, `HDMI-A-1`, hardware decoding per board, **the real seam times**, and mirror CPU cost.
- CEC with a real projector (including the `pwr-state:` output format), relay switching, IR send and learn, gpiomon, gpioset and gpio-ir on hardware, and the Pi 5 GPIO overlays.
- `videofx-update` end to end (GitHub download with a token, maintenance reboot and resume, rollback), `make-release.sh` from a clean checkout.
- The first-boot repartitioning (`videofx-storage`) on a real SD card and as a whole (only its partition steps ran, on a loop disk), overlayroot with `recurse=0` on a real card, maintenance mode, fsck after a real power cut, timesyncd with DHCP NTP, Wi-Fi power save and route metrics, the hardware watchdog and `systemd-notify` pings under systemd.
- The DigiAMP+ on each board and powering a Pi 5; that its unpopulated encoder/IR headers really leave GPIO 17, 23-25 and 27 floating; the fbdev blank turning HDMI off.
- From the review round: `ProtectHome=read-only` with the media bind mount, the `ExecStopPost` relay hook (`pinctrl`), the HDMI status files and how long your projector takes to report connected, CEC Active Source as a broadcast, `gpiomon -b` on libgpiod 1.x, the first-boot ordering after SSH key generation, and the `nofail` mounts.
- Apple Home pairing, the Scare switch in Home automations, the Occupancy and Temperature endpoints in Home, avahi and matter.js together, UniFi behaviour, and sACN from QLC+, xLights or FPP over Wi-Fi.

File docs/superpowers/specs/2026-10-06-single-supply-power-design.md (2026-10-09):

# Single-supply power: design (revision 2)

Status: approved 2026-10-08 (rev 2); plan: docs/superpowers/plans/2026-10-06-single-supply-power.md; Tasks 1-6 implemented, Task 7 waits for the brick. Supersedes revision 1 (stock wall-wart on a receptacle, Parts Express brick as the fallback). Nothing is printed, built or measured.

## Goal

Remove circuitry, and above all remove hand-wired mains. Today the case has two wall-warts, two stacked receptacles, an AC jumper, a live-only fuse, insulated crimps on receptacle tabs, two Wago rails and a spliced projector lead. The target has no hand-wired AC conductor anywhere: one listed desktop brick inside the case, fed by a standard cord that plugs into the brick's own inlet, and one DC Y-splitter.

Success: one supply, one Y-splitter, no AC wiring done by hand, no cut or spliced DC leads in the baseline build, no inter-rail ground path, and the relay/IR parts built only if bring-up proves CEC does not work.

## Target architecture

```
GFCI outlet -> AC cord (molded plug for the brick's inlet) -> case wall -> brick inlet
brick DC cord (uncut) -> 5.5x2.5 Y-splitter -+-> right-angle adapter -> projector
                                              +-> DigiAMP+ barrel jack -> Pi (5 V via header) + speakers
```

- **Supply:** the [Parts Express 24 V 5 A](https://parts-express.com/24-VDC-5A-Switching-Power-Supply-with-2.5-x-5.5mm-Plug-120-055) (120 W, 2.5 x 5.5 mm tip-positive; link unverified, the site returned 403 to the checker). It lies on the power shelf under the strap. It replaces the stock wall-wart, which cannot live in the case without a receptacle and is retired from the case.
- **Why 120 W:** the total load is the projector (label 63 W, manual says 50 W), plus the Pi and the amp at show volume, expected under about 80 W. That is a large margin, so the revision-1 load gate (at most 40 W against the 48 W stock supply) is no longer needed.
- **Both loads are 5.5 x 2.5 mm centre-positive** (projector per its label symbol and the owner; DigiAMP+ per its brief as quoted in WIRING.md). The Y-splitter replaces the cut-and-splice, both Wago rails, the minus join and the DC wire table.
- **AC entry:** a standard detachable cord whose molded connector fits the brick's inlet (inlet type to be read from the label or listing on arrival: IEC C8, C14, C6 or similar). The cord's connector end is inside the case, plugged into the brick; the other end plugs into the GFCI outlet. No stripping, crimping or spade terminals. This replaces the PG9 gland, the receptacle, its plate and the AC fuse.

## Open design problem: getting a molded connector through the wall

A round gland cannot pass a molded IEC plug. (As implemented, per the plan's ruling: a rectangular opening closed by a split two-piece clamp, not a keyhole.) Original recommendation: a keyhole-shaped opening in the rear wall (a large end for the connector, a narrow end for the cord) closed by a two-piece printed cord clamp that grips the cord jacket, seals with foam, and takes the pull so the strain never reaches the IEC joint. The shape is sized from the connector and cord you buy (`cord_d`, connector envelope), so it is a plan task that follows the arrival of the brick and cord. Drip loop outside, below the wall. Rejected: a panel-mount IEC inlet (its terminals need hand wiring, which defeats the goal), and an oversized gland (no sealing insert fits a cord that small).

## Stages

| Stage | Change | Condition |
|---|---|---|
| A | Drop the stock wall-wart from the case, both receptacles and plate, the AC jumper, the AC fuse, the Wago DC rails, the PG9 gland and the barrier's AC role; add the Parts Express brick, the AC cord with its clamp and the Y-splitter | Row 4a below passes |
| A-fallback | If the projector cannot take 24 V: a buck converter to 21 V on the projector leg only (the DigiAMP+ stays at 24 V, its maximum) | Row 4a fails |
| B | Drop relay module, GPIO 27 and the IR LED + BC337 + 1 kΩ + 47 Ω; keep `ir_holder` in the model | Bring-up row 9 shows CEC works |
| B-fallback | If CEC fails, keep the IR LED but drive it straight from GPIO 16 (about 13 mA through ~150 Ω, no transistor). The relay then needs the projector leg cut | CEC fails |
| C | TSOP38238 out of the permanent wiring (GPIO 23); learn the remote's codes on the bench | Always |

Unchanged: PIR on GPIO 17, the DigiAMP+ powering the Pi, HDMI CEC as the default power control. No Pi code changes: `cec` is already the default and `relay`/`relay-ir` remain selectable.

## The gate (BRINGUP row 4a; the shared-rail hum and flicker check is row 4b)

Before the brick is connected to anything in the case: run the projector from the Parts Express brick on the bench for 10 minutes at full brightness, metering the brick's output voltage first. Pass: runs normally, no smell, no unusual heat, no shutdown. Fail: stage A-fallback. Also, with the Pi and the amp running at show volume, listen for hum on the loudest cue and watch for picture flicker (shared-rail noise).

## Safety changes the owner must explicitly accept

CLAUDE.md lists "fused AC input" and "mains-rated cord grip with drip loop" among the things not to soften, and says mains is inside a printed box. This revision changes each:

1. **No AC fuse.** There is no hand-wired AC conductor left to protect; the cord and brick are molded parts (the brick must be UL/ETL listed: check its label), the brick has its own internal protection, and the GFCI/branch breaker is upstream. Revision 1 kept a live-only inline fuse because it was wiring receptacle tabs by hand. Owner to confirm that dropping it is acceptable (an inline-fused cord can be bought if not).
2. **No mains-rated cord grip, but a strain-relief clamp.** The printed clamp is meant to take a firm pull without loading the connector; prove it with the row 17a pull test. Drip loop stays.
3. **Mains is still inside the printed box** (the cord's connector and the brick's inlet). The barrier, the quick-connects and the receptacle go; the GFCI, the drip loop, PETG/ASA only and the weatherproof connection box for any plug joint stay. "Flame-retardant V-0 PETG recommended for the power shelf" stays, since the brick now sits on it.
4. **The cord is not outdoor-rated.** Owner decision (2026-10-06): the existing cord is good enough for the Halloween 2026 run (about a month outside) and can be replaced cheaply if damaged. Keep every plug joint off the ground and in the weatherproof box, inspect the cord daily, and run it along edges or under a cord cover as WIRING.md already says.

## Files this touches (to confirm in the plan)

`projector_pi_case.scad` (`power_shelf`: remove the plate, cutouts, strap-slot pairing around the wart; `warts()` becomes the brick envelope; the rear-wall gland becomes the keyhole + clamp; new `cord_clamp` part; asserts; `fit_coupon`'s receptacle tab can stay as a spare), `scripts/check_clash.sh` (brick envelope, clamp pair, `make parts`), `Makefile`, `scripts/render_wiring.py` (the HV drawing shrinks to cord, brick and Y-splitter; the DC rail and signal drawings as in revision 1), `docs/WIRING.md` (the HV section collapses; mains-safety wording reviewed with the owner), `docs/BOM.md` (new: brick, AC cord, Y-splitter, buck converter conditional; removed: second wall-wart, receptacles, quick-connects, fuse holder and fuses, Wago for AC, PG9; order the brick now, see Risks), `docs/BRINGUP.md`, `docs/ASSEMBLY.md`, `docs/measurements.xlsx`, `CLAUDE.md` (safety section and power bullets), `README.md`, `docs/DESIGN_LOG.md`, `docs/PRINTING.md`, `pi/README.md` (relay/IR fallback wording). I have not read the Pi code or the model's gland geometry beyond what the plan's reading covered.

## Assumptions to confirm

- The brick has a detachable AC inlet. A Parts Express "switching power supply" at 120 W is normally a desktop brick, but the page was not readable. If it is a plug-in wall-mount unit instead, it needs a receptacle again and revision 1's shelf stands.
- "The existing cord" means a standard detachable cord for that inlet that you already have or will get with the brick, not the 25 ft SJTW extension cord from the BOM. (That cord has a NEMA plug at both ends and would need an adapter to reach the brick.)
- Cord length outside the case is whatever reaches your outlet; no DC cord run is involved.

## Non-goals

No DC fuses beyond what the Y-splitter's leads need (see Risks). No case fans. No change to the aim, vent or lid geometry. No resize of the Pi zone or any tile in this pass; freed shelf space stays free.

## Risks

- **Lead time.** The brick is now the baseline, not a fallback, and Halloween is about three weeks away. Order it now, then read its label on arrival (UL/ETL mark, inlet type, tip polarity, input rating) and measure its body into `brick_*`.
- **Splitter lead rating.** A 5 A supply can overheat Y-splitter leads rated for about 3 A if a fault occurs downstream of the splitter. Buy a splitter rated for the supply's output, or add a small inline DC fuse on each leg.
- **Brick fit.** Its size is unknown. A desktop brick of this class may not fit the shelf's low-voltage side beside the sled interface; the first plan task on arrival is the clash check.
- **Projector tolerance of 24 V** is untested (row 4a); the buck converter is the answer if it fails.
- **Shared-rail noise** into the amp: class D amps reject supply ripple well, but listen on bring-up.
- **Strain relief** is a printed part holding a mains cord; prove it with a pull test before the lid goes on.

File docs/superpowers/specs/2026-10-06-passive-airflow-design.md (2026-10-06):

# Passive airflow: drop the fans, channel the projector's own

Date: 2026-10-06. Status: spec, awaiting owner review. Scope: SCAD model, Pi software, wiring/BOM/docs, clash checks.

## Goal

The projector's own fan moves the air. The case only has to give it a clean path in and out, rain-shedding and insect-screened. The Pi is cooled passively. Nothing else is cooled. Everything that exists only for active cooling goes.

## Owner-supplied facts (2026-10-06)

- **Exhaust:** projector's right face, the first 40 mm from the front, full height (66 mm).
- **Intake:** projector's rear face, 40 x 40 mm square, 15 mm from the right edge and 15 mm from the top. Confirmed on the rear face. Z span above the projector underside: 11 to 51.
- **Ports:** the DC barrel jack is on the rear face just above and to the right of the intake, so in the 15 mm top-right corner band (Z 51-66, X within 15 mm of the right edge). HDMI, USB and the AV mini-jacks are on a panel at the top of the **right face**, not the rear.
- **Duty:** the effect runs at night only; the projector is off by day.

### Read off the owner's photos (IMG_8913-8918, speed square for scale; about +/-2 mm)

- **Right face, exhaust grille:** slots from about 10 to 42 mm behind the front face, full height, plus a front fabric strip. The 40 mm figure holds.
- **Right face, I/O pocket:** a recessed strip along the top, about 18 mm tall, from about 41 to 118 mm behind the front. Centres from the front: HDMI 56, USB 80, AV 99, headphone 109; HDMI is about 9 mm below the top edge. Only HDMI is used.
- **Rear face, right intake:** grille 37 x 38 mm, about 16 mm from the right edge and 17 mm below the top (Z 12-49 above the underside). Matches the owner's 40 mm, 15 / 15.
- **Rear face, DC jack:** centre about 15 mm from the right edge and 13 mm below the top (Z 53), directly above the intake's right half. A barrel plug body (about 11 mm) overlaps the top 3 mm of the intake patch; acceptable. A Type-C port 50 mm from the right edge is unused.
- **Rear face, second grille:** a speaker (owner, 2026-10-06), on the lens lobe, X about -67 to -33, Z 12-46. Not an air path. It faces the rear gap, so nothing may block it (the inlet bank and baffle are on the right, clear of it); its sound just reflects off the divider.
- **Front face, IR receiver (owner, 2026-10-06):** centred above the Tkisko logo, which sits on the right lobe. From the photo that puts it near X +35 (right of centre) and Z about 50 above the underside; confirm with calipers. It lies in the front gap behind the acrylic pane (the window spans X -83 to +43) and outside the light cone, so the `ir_holder` and its LED fit there.
- **Left face:** plain, no vents or ports. **Top:** buttons and a slot on the lens lobe, a diamond texture on the other; no vents.

## Airflow design

Air path: outside, right-wall inlet bank, rear gap, projector intake (rear face), projector fan, exhaust (right face, front), right-wall exhaust bank, outside.

1. **Exhaust bank (right wall, front).** 45 deg rain louvers over an opening spanning the exhaust patch plus aim margin: Y = 40 + 2 x `air_margin`, Z = 66 + 2 x `air_margin_z`, starting at the projector's front face. Margins give partial cover of the pan/tilt sweep (at the extremes some exhaust leaves into the side gap, which is the plenum; a rigid duct cannot follow the ball head). A `screen_cap` covers it (part `vent_cap`).
2. **Inlet bank (right wall, rear).** Louvers over the rear gap, centred on the intake's height (z_pj + 31). The rear gap (`rear_gap` 34 mm) is the plenum: no printed duct, since the projector moves. A `screen_cap` covers it (part `intake_cap`, now wall-mounted).
3. **Baffle.** One vertical rib on the right wall's inside face between the two banks (`baffle_d` deep, full inner height), so exhaust that stays inside the case does not creep back to the rear inlet along the side gap. Depth is capped by the aim sweep: `baffle_d <= side_air - swing`, asserted and checked in `aim-sweep`. It is a lip, not a seal.
4. **One passive Pi-zone louver.** Right wall, over the shelf's low-voltage side, high (the existing `vents` entry at `shelf_zz + 26`, 26 x 42 opening, part `vent_cap` unchanged). Warm air leaves here; make-up air arrives through the open divider pass-through. The effect only runs at night, so there is no solar load on the Pi zone while the electronics are working.
5. **Everything else closes.** Removed: both 40 mm fan seats and their bosses, the other two louver banks, the floor intake slots and cap, the shelf's heat-rise slots.

Three screen caps remain (was five): `exhaust_cap` (new), `intake_cap` (now the rear inlet, wall-mounted), `vent_cap` (Pi zone, unchanged). The floor no longer takes splash and nothing is mounted proud of the right wall.

## Cables

- **DC barrel (rear, top-right corner):** a right-angle barrel plug points back and clears the intake patch (it is above Z 51). Keep-out stays in `projector_ports` with `port_band` moved to Z 51-66 and X right 0-15 from the edge. The wall-wart's DC cord reaches it through the rear gap.
- **HDMI / USB / AV (right face, top):** plugs now stick out into the right side gap, which is `side_air` 25 mm minus the pan swing, so right-angle HDMI (and no USB or AV cables left plugged in) is required. New keep-out `projector_side_ports` (from the photos: the HDMI plug at 56 mm from the front, top 18 mm of the right face, right-angle, cable pointing rearward, `side_port_depth` 15). The HDMI cable runs back along the side gap above the baffle to the Pi's pass-through, so the baffle's top stops below the I/O strip (`baffle_gap` 22 mm under the top edge; the rib blocks the lower 44 mm of the gap, and exhaust leaking over it is accepted). The HDMI plug at 56 mm sits just behind the exhaust opening (which ends near 50 mm with its aim margin), so the baffle itself stands at about 50 mm and the plug passes over it and the HDMI keep-out joins the `aim-sweep` check.

## Pi software

Remove: fan PWM (`SysfsPwm`), tach, `ThermalControl` and fan curves, DS18B20 reading, the sensor-loss shutoff, the Cooling settings group (`fan1/2Curve`, `fanMinDuty`, `fanCooldownSec`, sensor IDs, `thermalEnabled`), fan/tach/1-wire GPIO entries (GPIO 12, 13, 24, 25, 26), the `setup.sh` PWM and w1 overlay block, and the matching tests and UI.

Keep: SoC temperature read (`thermal_zone0`) for the web UI and the Matter temperature sensor, and `OverTempGuard` fed by SoC temperature only (powers the projector off past `tempCritC`). The projector's own thermal cutoff is its protection; nothing else is claimed.

Side benefit: hardware PWM0 (GPIO12) is free, so `pwm-ir-tx` becomes legal for the IR fallback; drop the guard in `config.js` that forbids it.

## Power

The second wall-wart no longer has to be 24 V for fans. It feeds the Pi and DigiAMP+ only (12-24 V; pick for amp volume). The fan fuse and branch go; WIRING.md and `render_wiring.py` change, SVGs regenerate. The "fans must match the second rail" caveat goes from CLAUDE.md and the BOM.

## Model and checks

- **IR holder keep-out.** New parameters `ir_x` (35) and `ir_z` (50, above the underside). `ir_holder` goes into the assembly at the front face and into `aim-sweep` and the light-cone check (it must clear the pane, frame and visor over the pan/tilt range inside `front_gap` 30, and stay out of the cone). The LED lead runs up and back over the top of the projector; allow for it in the side gap past the baffle.

- New parameters: `exh_len` (40), `exh_h` (= `proj_h`), `in_size` (40), `in_top` (15), `air_margin`, `air_margin_z`, `baffle_d`, `baffle_gap`, `side_port_depth`, `side_port_y`, `side_port_h`. Changed: `port_band` (barrel corner), `vents` (one entry). Removed: `fan`, `pi_fan_dz`, `fans`, `fan_z`, `pi_fan_z`, `fan_body`, `intake_c`, floor intake cuts and bosses, shelf vent slots.
- `check_clash.sh`: drop `fans`; fix `warts`/`aim-sweep` (they referenced `fan_body`); `screen-caps` covers the three wall caps; add the baffle to `aim-sweep`; add a check that the intake patch is inside the inlet opening and the exhaust patch inside the exhaust opening at zero aim.
- Bed fit is unaffected (outer size unchanged). `side_air` stays 25 for now: with the fan body gone it could shrink to roughly 19 mm (pan swing 16 mm plus clearance), which would pull the base off the 210 mm axis limit. That is a separate change; flagged, not done here.
- Docs updated in step: BOM (fans, DS18B20s, pull-up; screen caps 5 to 3), ASSEMBLY, BRINGUP (fan/sensor rows), PRINTING (re-slice), DESIGN_LOG (new entry, supersedes the Heat and Insect screen decisions), CLAUDE.md, README, `pi/README.md`.

## Risks to carry into bring-up

1. **Side-panel position** is now photo-derived (41-118 mm from the front, top 18 mm), good to a few mm; confirm with calipers before printing the baffle.
2. **Pi zone heat.** Two wall-warts and a DigiAMP+ sit behind one passive louver. Bring-up should log SoC and shelf temperature on a warm night with the lid on. Night-only duty keeps the load low; if it still runs hot, a second low louver on the other wall completes the convection loop (no fan).
3. **Recirculation.** Exhaust at the front and intake at the rear are 90 mm apart behind a lip baffle. A hot-day test with a thermometer at the intake is the real check.
4. **Louver opening size** vs. the projector's real vent patches is from owner measurements, not photos; re-measure before printing the caps.

## Out of scope

Shrinking `side_air`, multi-projector, any change to the hatch, shelf layout, sleds or lid.

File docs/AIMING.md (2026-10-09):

# Aiming the projector

The projector sits on a ball head inside the case. You reach it through the aim hatch without taking the lid off. No tools are needed.

> Nothing has been printed yet. These steps describe the current design; update them after the first fit check.

## Before you start

- Aim in dry weather. With the hatch open the case is not rain-shedding.
- Turn the projector on and play something with straight edges and corners (a grid or test pattern works best). Use the Matter switch in your Home app, or the Play button on the Pi's web page at `videofx-xxxx.local`.
- Know where the hatch is: it's the side wall with the small sloped rain hood. Standing behind the case, facing where it projects, it is on your right.

## Aim range

| Movement | Inside the case |
|---|---|
| Pan (left/right) only | +/-10 deg (beyond this the image clips the window frame; turn the case instead) |
| Tilt (up/down) only | +/-11 deg (the image starts clipping on the window or visor beyond this) |
| Pan and tilt together | +/-8 deg each |

These assume the Tkisko TO2's short throw (about 0.95:1, derived from its manual) with the image centred on the lens. Measure both (`throw_ratio`, `lens_offset`) and rerun the light-cone check: a shorter throw means a wider cone and less pan, and a projector that throws the image upward ("offset") trades downward tilt for upward.

Past that, the projector hits the window frame or the Pi divider. Get the case close first and use the ball head for fine adjustment.

## Steps

1. **Place the case.**
   - On the ground: firm, level ground with all feet down, out of puddles, because air comes in through the floor. Turn the whole case until the image lands roughly on target.
   - Either way, keep it low and tilt the image up, so people walking past aren't looking into the lens (a bright "hot spot").
2. **Take off the hatch cover.** If the optional lock screw is fitted (bottom centre of the cover), remove it first. Lift it straight up about 8 mm, until the bolt heads line up with the wide ends of the keyholes, then pull it straight out. Don't pry it.
3. **Support the projector.** Put one hand through the hatch and hold the projector before loosening anything. It weighs about 0.7 kg and will flop if the head is loose.
4. **Loosen the ball head** lock knob just enough that the projector moves with some friction.
5. **Aim.** Move the projector while watching the image. Keep it inside the ranges above. If it touches anything inside, stop: turn or shim the case instead.
6. **Check the edges.** A dark or cut-off corner means the light cone is clipping the window. Bring the image back toward centre and move the case instead.
7. **Lock the ball head** firmly while still holding the projector. Let go, wait a minute, and check the image hasn't drooped.
8. **Focus.** Use the projector's focus control if you can reach it through the hatch. If you can't, remove the four lid screws on the sides of the lid and lift it off.
9. **Hang the cover.** Refit the lock screw if you use one. Line up the wide ends of the keyholes over the four bolt heads, press it flat against the foam, and let it drop about 8 mm so it seats. It should sit flush and not pull straight out.
10. **Final check.** The louver banks are clear of the HDMI cable and the power cord hangs in a drip loop below the cord clamp.

## Troubleshooting

| Problem | Fix |
|---|---|
| Image cut off or dark at one edge | The window is clipping it: recentre the projector and move the case. |
| Can't reach the target | Turn the case for pan. For tilt, shim under the front or rear feet and keep the gap under the floor open. |
| Image droops over time | Retighten the ball head. Check the pedestal screws and the 1/4-20 stud are tight. |
| Image is trapezoidal | Use the projector's keystone setting. Square up the case first, since keystone correction softens the image. |
| Cover won't seat | A bolt is too tight against the wall: back it out half a turn so the head clears the cover. |

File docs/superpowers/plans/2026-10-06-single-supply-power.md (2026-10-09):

# Single-Supply Power Implementation Plan (revision 2)

> **For agentic workers:** REQUIRED SUB-SKILL: Use superpowers:subagent-driven-development (recommended) or superpowers:executing-plans to implement this plan task-by-task. Steps use checkbox (`- [ ]`) syntax for tracking.

**Goal:** Replace the two-wall-wart, two-rail, hand-wired-mains power system with one Parts Express 24 V 5 A desktop brick inside the case, fed by a standard cord that plugs into its inlet, and one DC Y-splitter to the projector and the DigiAMP+.

**Architecture:** The shelf loses its receptacle plate, barrier and notch and gains a brick envelope. The rear wall's PG9 hole becomes a rectangular opening closed by a two-piece printed cord clamp that grips the cord jacket (strain relief) and seals with foam. The brick's DC cord (uncut) goes into a 5.5 x 2.5 mm Y-splitter. The relay, IR LED and receiver drop out of the baseline wiring and survive only as CEC fallbacks. Docs, schematics and checks follow. The brick's real size and inlet are unknown until it arrives, so the shelf layout is provisional (Task 1) and re-fitted on arrival (Task 7); the wall opening and clamp are generous standard sizes so `base_rear` can print before the brick arrives.

**Tech Stack:** OpenSCAD (snapshot), bash + python3 (`scripts/check_clash.sh`), Python + Schemdraw via `uv` (`scripts/render_wiring.py`), openpyxl (`docs/measurements.xlsx`), Markdown + Mermaid. No Pi code changes: projector power already defaults to `cec`.

**Spec:** `docs/superpowers/specs/2026-10-06-single-supply-power-design.md` (revision 2, approved "LGTM" 2026-10-08; read it first).

## Global Constraints

- OpenSCAD binary on the owner Mac: `/Applications/OpenSCAD.app/Contents/MacOS/OpenSCAD`. Export `OPENSCAD=` that path for every `make` and `scripts/check_clash.sh` call. It aborts inside Claude Code's sandbox, so run those commands unsandboxed.
- `scripts/check_clash.sh` must say `ok` (or `ok ... (contact)`) on every line after each model task. Outer tile sizes must not change (bed-fit asserts). Do not resize `pi_zone_d`, `shelf_z` or any tile.
- Top-level OpenSCAD variables are evaluated in order; define a variable before anything top-level that uses it. New knobs are parameters under `/* [Section] */` headers, not magic numbers.
- Do not edit `docs/wiring-*.svg` by hand; edit `scripts/render_wiring.py` and run `uv run scripts/render_wiring.py`.
- **Safety wording changes are authorised.** The owner approved spec revision 2, which explicitly accepts: no AC fuse, a strain-relief clamp instead of a mains-rated cord grip, no barrier, and a cord that is not outdoor-rated (one month outside, replaced if damaged). Apply exactly those changes to `docs/WIRING.md` and `CLAUDE.md` "Safety" and nothing further. What stays: GFCI-fed outlet, drip loop, plug joints in the weatherproof box and off the ground, PETG/ASA only, V-0 PETG recommended for `power_shelf`, "mains is inside a printed box". Never call the case waterproof or certified.
- Never present a link as verified unless it opened. The Parts Express page returned HTTP 403 on 2026-10-06; mark its link "unverified".
- Provisional values are marked `PROVISIONAL` in comments and in the docs; do not present them as measured.
- Commit messages end with `Co-Authored-By: Claude Sonnet 5.5 <noreply@anthropic.com>`. Do not push.
- Facts used throughout: supply Parts Express 24 V 5 A, 120 W, 2.5 x 5.5 mm tip-positive (label, inlet type, input current, UL/ETL mark to be read on arrival); projector label DC 21 V 3 A (manual says "110 V, 50 W"); DigiAMP+ takes 12-24 V on its 5.5 x 2.5 mm centre-positive barrel jack and powers the Pi; shelf is `shelf_w` 214 x `shelf_d` 84, top at `shelf_zz`+3 = 75 above the ground, `lid_z0` 168; PIR slot at `pir_x` 55.
- Bring-up gate (row 4a): the projector runs 10 minutes at full brightness from the Parts Express brick on the bench. If it fails, a buck converter to 21 V goes on the projector leg only.

## Review Focus

1. **Brick fit.** Its size is unknown; a long brick can collide with the PIR slot, the cord opening or the sled stack. Pinned by Task 1's asserts and clash pairs and re-run in Task 7 with real numbers.
2. **Cord opening and clamp survive the geometry.** The opening must stay inside the left wall, clear the stake tube and lid screw block, and keep the clamp's four pilots on solid wall. Pinned by Task 2's asserts and `cord-clamp` pairs.
3. **Strain relief actually relieves strain.** A printed clamp holds a mains cord. Pinned by a pull-test step in Task 2 and BRINGUP row 17a.
4. **24 V into a 21 V projector.** Nothing may tell the owner to connect the brick to the projector before row 4a passes. Pinned by the grep in Task 5 step 5.
5. **Y-splitter polarity and lead rating.** A reversed splitter is a plug-in mistake, and a 5 A supply can overheat 3 A leads. WIRING.md must require a meter check of both legs and leads rated for 5 A or a fuse sized to the lead. Pinned in Task 4 step 2.
6. **DigiAMP+ plug through the shelf slot.** The barrel plug must pass the wire slot or the DigiAMP+ leg cannot reach the sled. Pinned by Task 1 step 5 and a measurement in Task 7.
7. **Shared-rail noise.** The amp shares a rail with the projector. BRINGUP row 4b includes listening for hum on the loudest cue.

## File Structure

- `projector_pi_case.scad`, `scripts/check_clash.sh`, `Makefile`: brick, opening, clamp (Tasks 1, 2, 7).
- `scripts/render_wiring.py`, `docs/wiring-*.svg`: three drawings (Task 3).
- `docs/WIRING.md`: the electrical truth (Task 4).
- `docs/BOM.md`, `docs/BRINGUP.md`, `docs/ASSEMBLY.md`, `docs/PRINTING.md`, `docs/measurements.xlsx` (Task 5).
- `CLAUDE.md`, `README.md`, `docs/DESIGN_LOG.md`, `pi/README.md` (Task 6).
- Task 7 is deferred until the brick and the cord arrive.

---

### Task 1: Shelf without the receptacle plate, with a provisional brick

**Files:**
- Modify: `projector_pi_case.scad` (params ~96-111; derived ~261-268; asserts ~277-284; `power_shelf()` ~434-462; `warts()` ~466-469; assembly ghost ~576; header changelog lines 1-8)
- Modify: `scripts/check_clash.sh:63`

**Interfaces:**
- Consumes: nothing.
- Produces: `brick` (`[L along X, W along Y, H]`, PROVISIONAL), `brick_x0`, `brick_y0`, `brick_gap`, `wire_slot`; module `brick_env()` (replaces `warts()`); `power_shelf()` without plate, barrier, notch. Removes `wart_*`, `wart2`, `rcpt_*`, `plate_*`, `prong_x`, `bar_x`, `barrier_h`, `rcpt_zc`, `warts()`.

- [ ] **Step 1: Green baseline**

```bash
export OPENSCAD=/Applications/OpenSCAD.app/Contents/MacOS/OpenSCAD
scripts/check_clash.sh
```
Expected: every line `ok`. If anything fails, stop and report.

- [ ] **Step 2: Red check**

```bash
grep -c "wart\|rcpt_\|barrier_h\|bar_x\|plate_x0" projector_pi_case.scad
```
Expected: a number well above 0 (about 40).

- [ ] **Step 3: Replace the supply parameters**

In `projector_pi_case.scad`:

1. Delete the whole block from the comment `// Stock supply (label, 2026-10-05): ...` through the line `barrier_h = 50; ...` (this removes `wart_l/w/t/prong`, `wart2`, `rcpt_cut/t/hole_sp/back`, `barrier_h`; keep `cord_x`, `cord_dz` lines above it). Put in its place, under the same `/* [Hardware] */`-style section the block was in:
```openscad
// Supply (spec 2026-10-06, rev 2): the Parts Express 24 V 5 A desktop brick lies on the shelf under a velcro strap, fed by a
// standard cord that plugs into its AC inlet; its DC cord goes uncut into a 5.5 x 2.5 mm Y-splitter. The stock 21 V wall-wart is
// retired from the case. Nothing about the brick is measured yet.
brick = [150, 60, 38];   // PROVISIONAL (a typical 120 W desktop brick): length along X, width along Y, height. Measure the real one (Task 7)
brick_gap = 5;           // room between the brick and the rear wall for the strap and the cord bend
wire_slot = [20, 14];    // shelf slot for the DigiAMP+ leg and the PIR wires: the DC barrel plug (about 11 x 16) must pass; check with the real splitter
```
2. Leave `gland_d` and the PG9 hole alone: Task 2 replaces them.
3. In the derived block, delete `plate_x0`, `plate_w`, `prong_x`, `wart_x0`, `bar_x`, `rcpt_zc`, `plate_y1`, `plate_y0` and add after `shelf_d`:
```openscad
brick_x0 = -shelf_w/2 + 3;                 // the brick's left end, against the left wall side of the shelf
brick_y0 = shelf_d - brick[1] - brick_gap; // its front edge: it sits toward the rear wall
```
4. Replace the asserts that mention `wart`, `rcpt_back`, `plate_x0`, `barrier_h` or `bar_x` (the `barrier_h`, `cord_x`, `rcpt_back`, `shelf_zz + rcpt_zc`, `bar_x + 60` lines) with:
```openscad
assert(brick_x0 + brick[0] + 3 <= pir_x - 6, "the brick runs into the PIR / wire slot: measure it, or shorten it");
assert(brick_y0 >= 0 && brick[1] + brick_gap <= shelf_d, "the brick is deeper than the shelf");
assert(shelf_zz + 3 + brick[2] + 2 <= lid_z0, "the brick hits the lid skirt: raise top_air (or lower shelf_z)");
```
Keep the two `cord_dz` asserts that mention `gland_d` as they are (Task 2 rewrites them). Delete only the assert that mentions `plate_x0`.

Also in this step, because `fit_coupon()` still reads `rcpt_cut` and `rcpt_t`: in `fit_coupon()` remove the receptacle tab cube (`translate([34, 30, 0]) cube([rcpt_cut[0]+14, 32, rcpt_t]);`), the `NEMA 5-15R snap-in cutout` cube and the `5-15R` text line. Leave the `[gland_d, "PG9", 3]` entry for Task 2.

- [ ] **Step 4: Rewrite `power_shelf()` and the envelope**

Replace the module's header comment with:
```openscad
// Power shelf above the Pi. The desktop brick lies on it toward the rear wall, held by a velcro strap through the slots; its
// AC cord comes in through the rear wall, its DC cord goes to the Y-splitter. Mains is only in the brick and its inlet connector.
```
In the body: delete the `plate` cube, the gusset `for`, the `barrier` cube, the receptacle-cutout `for (z=rcpt_zc)` block, and the barrier notch line. Change the strap slots to
```openscad
    for (x=[brick_x0 + brick[0]*0.3, brick_x0 + brick[0]*0.7], y=[brick_y0 - 4, brick_y0 + brick[1] + 1])   // velcro strap slots round the brick
      translate([x-10, y, -1]) cube([20, 3, 5]);
```
Replace the zip-tie condition `if (x > bar+6)` with `if (x > brick_x0 + brick[0] + 6)`. Replace the PIR slot line with
```openscad
    translate([pir_x-6, shelf_d-wire_slot[1], -1]) cube([wire_slot[0], wire_slot[1]+1, 5]);   // PIR wires and the DigiAMP+ leg (with its plug) down to the Pi
```
Delete `py0`, `py1`, `bar`, `plate_h`, `gus` locals that are now unused. Replace `warts()` with:
```openscad
// The brick's envelope on the shelf (shelf coordinates): preview ghost and clash keep-out
module brick_env() {
  translate([brick_x0, brick_y0, 3]) cube(brick);
}
```
In the assembly ghost (line ~576) change `%translate([0, y_pi0+0.3, shelf_zz]) warts();` to `brick_env()`.

- [ ] **Step 5: Header changelog and clash script**

Read lines 1-8 and append in the same style: `// v0.10 - single supply: one desktop brick on the shelf (receptacle plate, barrier, wart2 and the PG9 gland replaced by a brick envelope, a rear-wall opening and a cord clamp).` (If the newest line is already v0.10, append `; one desktop brick replaces the wall-warts and the receptacle plate` instead.)

In `scripts/check_clash.sh:63` change `warts()` to `brick_env()`, the pair name `warts` to `brick`, and the trailing comment to `# the brick on the shelf vs case, lid roof and shelf`.

- [ ] **Step 6: Verify green**

```bash
grep -n "wart\|rcpt_\|barrier_h\|bar_x\|plate_x0\|warts()" projector_pi_case.scad scripts/check_clash.sh
```
Expected: no output. Then
```bash
export OPENSCAD=/Applications/OpenSCAD.app/Contents/MacOS/OpenSCAD
$OPENSCAD -o /tmp/shelf.stl -D 'part="power_shelf"' projector_pi_case.scad 2>&1 | tail -5
scripts/check_clash.sh
```
Expected: no assertion text; every line `ok`. If `brick_x0 + brick[0] + 3 <= pir_x - 6` fires, the provisional brick is too long for the shelf: that is real information, so report it with the numbers (shelf 214 wide, PIR slot starts at 49) instead of loosening the assert. If the widened wire slot hits a lid screw block or the PIR hole, shrink `wire_slot` and report.

- [ ] **Step 7: Look and commit**

```bash
$OPENSCAD -o /tmp/shelf.png --imgsize 1200,800 --camera 0,40,30,60,0,30,260 -D 'part="power_shelf"' projector_pi_case.scad
```
Read `/tmp/shelf.png`: a flat shelf with strap slots, tie slots and the wire slot, no plate or barrier.
```bash
git add projector_pi_case.scad scripts/check_clash.sh
git commit -m "Shelf: provisional desktop brick, no receptacle plate or barrier

Co-Authored-By: Claude Sonnet 5.5 <noreply@anthropic.com>"
```

---

### Task 2: Rear-wall cord opening and cord clamp

**Files:**
- Modify: `projector_pi_case.scad` (params; asserts; `cuts()` gland line ~351-352; additive bosses in `base_all()` near the stake collars ~400; new `cord_clamp_half()`, `cord_clamp()`, `cord_clamp_placed()`; part dispatch ~725-737; `fit_coupon()` ~623-640)
- Modify: `Makefile`, `scripts/check_clash.sh`

**Interfaces:**
- Consumes: Task 1's shelf and coupon changes (`gland_d`, the PG9 hole and its two asserts are still in place).
- Produces: `cord_open` (`[W, H]`), `cord_d`, `cord_x`, `cord_dz`, `clamp_t`, `clamp_flange`, `cord_boss`; modules `cord_clamp_half()`, `cord_clamp()` (both halves laid out for printing), `cord_clamp_placed()` (both halves on the wall, for the assembly and clash checks); `part = "cord_clamp"`.

- [ ] **Step 1: Parameters**

Replace `cord_x = -94; ...` and `cord_dz = 20; ...` with:
```openscad
cord_x = -75;       // centre of the AC cord opening in the rear wall: the opening, its bosses and the clamp all have to sit inside the left wall (asserted)
cord_dz = 30;       // opening centre above the shelf's top face: the clamp's lower screws clear the shelf, the clamp's top clears the lid skirt (asserted)
cord_open = [40, 30];   // rear-wall opening [X, Z]: passes a molded IEC plug (a C13 body is about 28 x 21 mm) with room; the clamp covers it
cord_d = 9;             // AC cord jacket diameter: PROVISIONAL, measure the cord you use
clamp_t = 6;            // clamp half thickness
clamp_flange = 10;      // each half overlaps the opening by this much all round
cord_boss = 6;          // pilot bosses inside the wall, at the clamp's four screws
```
Delete `gland_d = 15.5; ...` from `/* [Hardware] */`. Then, among the derived values after `y_back` is defined, add
```openscad
clamp_w = cord_open[0] + 2*clamp_flange;
clamp_h = cord_open[1] + 2*clamp_flange;      // both halves together
cord_z = shelf_zz + 3 + cord_dz;              // opening centre, from the ground
cord_screws = [for (sx=[-1,1], sz=[-1,1]) [cord_x + sx*(cord_open[0]/2 + clamp_flange/2), cord_z + sz*(cord_open[1]/2 + clamp_flange/2)]];
```
and replace the two asserts that mention `gland_d` with:
```openscad
assert(cord_x - clamp_w/2 >= -out_w/2, "move cord_x right: the cord clamp hangs off the rear wall's left edge");
assert(cord_x - cord_open[0]/2 - 4 >= -inner_w/2, "move cord_x right: the cord opening must sit inside the left wall");
assert(cord_dz - cord_open[1]/2 - clamp_flange >= 3, "raise cord_dz: the clamp's lower screws land on the shelf");
assert(cord_z + clamp_h/2 <= lid_z0 - 2, "lower cord_dz: the cord clamp runs into the lid skirt");
assert(cord_d >= 5 && cord_d <= cord_open[1] - 6, "cord_d: measure the cord; it must fit the opening and the clamp channel");
```

- [ ] **Step 2: The opening and the bosses**

In `cuts()`, replace the gland line (the comment `// single power-cord gland ...` and its `translate(...) cylinder(d=gland_d ...)`) with:
```openscad
  // AC cord opening (rear wall, above the shelf): passes a molded plug; the cord clamp covers it and grips the jacket
  translate([cord_x - cord_open[0]/2, y_back - 1, cord_z - cord_open[1]/2]) cube([cord_open[0], wall + 2, cord_open[1]]);
  // clamp screw pilots (M3 self-tapping) from the outside through the wall into the bosses
  for (p = cord_screws) translate([p[0], y_back + wall + 1, p[1]]) rotate([90, 0, 0]) cylinder(d=2.6, h=wall + cord_boss + 1);
```
In `base_all()`'s additive `union()`, next to the stake collars, add
```openscad
      for (p = cord_screws) translate([p[0], y_back - cord_boss, p[1]]) rotate([-90, 0, 0]) cylinder(d=8, h=cord_boss + 0.01);   // pilot bosses for the cord clamp
```
(Read `base_all()` first and put it beside similar bosses; the exact line numbers moved in Task 1.)

- [ ] **Step 3: The clamp**

Add near the other small parts (for example after `ir_holder`):
```openscad
// Cord clamp: two halves split on the cord's axis, M3 into the bosses inside the rear wall. The channel is cord_d - 0.6 so the
// halves bite the jacket (strain relief: the pull goes into the wall, not into the IEC joint). Lay a 2 mm foam gasket under it.
// Each half prints wall-face down on the bed; the channel runs through the thickness.
module cord_clamp_half() {
  h = clamp_h / 2;
  difference() {
    cube([clamp_w, h, clamp_t]);                                                       // x across, y = the half's height, z = thickness
    translate([clamp_w/2, 0, -1]) cylinder(d=cord_d - 0.6, h=clamp_t + 2);             // half-channel on the split edge (y = 0)
    for (sx=[-1,1]) translate([clamp_w/2 + sx*(cord_open[0]/2 + clamp_flange/2), h - clamp_flange/2, -1]) cylinder(d=3.4, h=clamp_t + 2);   // M3 clearance
  }
  for (sx=[-1,1]) translate([clamp_w/2 + sx*(cord_open[0]/2 + clamp_flange/2), h - clamp_flange/2, clamp_t - 0.01]) cylinder(d=6.5, h=0.01);   // marks the head seat
}
module cord_clamp() {   // both halves, side by side, as printed
  cord_clamp_half();
  translate([0, clamp_h/2 + 5, 0]) cord_clamp_half();
}
module cord_clamp_placed() {   // both halves on the rear wall's outer face (assembly, clash checks)
  x0 = cord_x - clamp_w/2;
  yo = y_back + wall;
  translate([x0, yo, cord_z]) rotate([-90, 0, 0]) cord_clamp_half();                  // lower half: split edge at the cord axis, hangs down
  translate([x0, yo, cord_z]) rotate([90, 0, 0]) mirror([0, 0, 1]) cord_clamp_half(); // upper half
}
```
(The zero-height head-seat cylinder is an optional visual mark; delete it if OpenSCAD warns.) In the assembly module add `cord_clamp_placed();` beside the other placed parts, and in the part dispatch add
```openscad
else if (part == "cord_clamp") cord_clamp();
```
In `Makefile`: add `$(OUT)/cord_clamp.stl` to the `parts:` list and
```make
$(OUT)/cord_clamp.stl: $(SCAD) | $(OUT)
	$(OPENSCAD) -o $@ -D 'part="cord_clamp"' $(SCAD)
```

- [ ] **Step 4: Fit coupon**

In `fit_coupon()`: remove the `[gland_d, "PG9", 3]` entry from `holes` (the receptacle pieces went in Task 1). Nothing replaces it: the `[2.6, "M3p", 8]` pilot entry already exists, and the clamp is printed itself as the fit test.

- [ ] **Step 5: Clash pairs**

In `scripts/check_clash.sh` add, next to the other part/case pairs (use the existing `$LID` variable):
```bash
run cord-clamp     "intersection(){ cord_clamp_placed(); union(){ base_all(); $LID; } }"   # clamp against the rear wall and lid skirt: contact only
```

- [ ] **Step 6: Verify**

```bash
export OPENSCAD=/Applications/OpenSCAD.app/Contents/MacOS/OpenSCAD
scripts/check_clash.sh
make parts
$OPENSCAD -o /tmp/clamp.stl -D 'part="cord_clamp"' projector_pi_case.scad 2>&1 | tail -3
```
Expected: every line `ok` (the `cord-clamp` line `ok (contact)`); `make parts` includes `stl/cord_clamp.stl` with no error. If a stake tube, lid screw block or the left wall clashes with the opening or the bosses (the check names the pair), move `cord_x`/`cord_dz` within the asserts; do not shrink `clamp_flange` below 8.

- [ ] **Step 7: Look and pull-test**

```bash
$OPENSCAD -o /tmp/rear.png --imgsize 1200,800 --camera 0,100,100,70,0,200,500 -D 'part="assembly"' projector_pi_case.scad
```
Read `/tmp/rear.png`: the clamp sits over the rear-left opening, clear of the lid. The strain-relief pull test is a physical step that cannot run until the clamp is printed: it is BRINGUP row 17a (Task 5); do not claim the clamp relieves strain until that row passes.

- [ ] **Step 8: Commit**

```bash
git add projector_pi_case.scad scripts/check_clash.sh Makefile
git commit -m "Rear wall: cord opening and two-piece cord clamp replace the PG9 hole

Co-Authored-By: Claude Sonnet 5.5 <noreply@anthropic.com>"
```

---
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

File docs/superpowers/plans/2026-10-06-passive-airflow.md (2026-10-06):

# Passive Airflow Implementation Plan

> **For agentic workers:** REQUIRED SUB-SKILL: Use superpowers:subagent-driven-development (recommended) or superpowers:executing-plans to implement this plan task-by-task. Steps use checkbox (`- [ ]`) syntax for tracking.

**Goal:** Remove the two case fans, the DS18B20 sensors and their software, and give the projector's own fan a clean passive path in and out of the case.

**Architecture:** The OpenSCAD model gets an exhaust louver bank (right wall, front), an inlet bank (right wall, rear gap) and a lip baffle between them; one passive Pi-zone louver stays. Everything else that existed for active cooling goes. The Pi keeps only an SoC-temperature guard. Docs, BOM, wiring and checks follow.

**Tech Stack:** OpenSCAD (snapshot), bash + python3 (`scripts/check_clash.sh`), Node 24 + vitest (`pi/`), Python + Schemdraw via `uv` (`scripts/render_wiring.py`).

**Spec:** `docs/superpowers/specs/2026-10-06-passive-airflow-design.md` (read it first; it holds the measured projector facts and the reasoning).

## Global Constraints

- OpenSCAD binary on the owner Mac: `/Applications/OpenSCAD.app/Contents/MacOS/OpenSCAD`. Export `OPENSCAD=` that path for every `make` and `scripts/check_clash.sh` call. It aborts inside Claude Code's sandbox, so run those commands unsandboxed.
- `scripts/check_clash.sh` must say `ok` (or `ok ... (contact)`) on every line after each model task. The base tiles must still pass the bed-fit asserts (outer size must not change).
- Top-level OpenSCAD variables are evaluated in order; define a variable before anything top-level that uses it (functions may use later ones).
- New knobs are parameters under `/* [Section] */` headers; derived values go under `/* [Hidden] */`. No magic numbers.
- Pi tests: `cd pi && npx vitest run`, outside Claude Code's sandbox (they bind 127.0.0.1 and a Unix socket).
- Do not edit `docs/wiring-*.svg` by hand; edit `scripts/render_wiring.py` and regenerate.
- Mains-safety wording in `docs/WIRING.md` and `CLAUDE.md` ("Safety") stays as is. Never call the case waterproof.
- Do not commit unless a task's commit step says so. Commit messages end with `Co-Authored-By: Claude Sonnet 5.5 <noreply@anthropic.com>`.
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

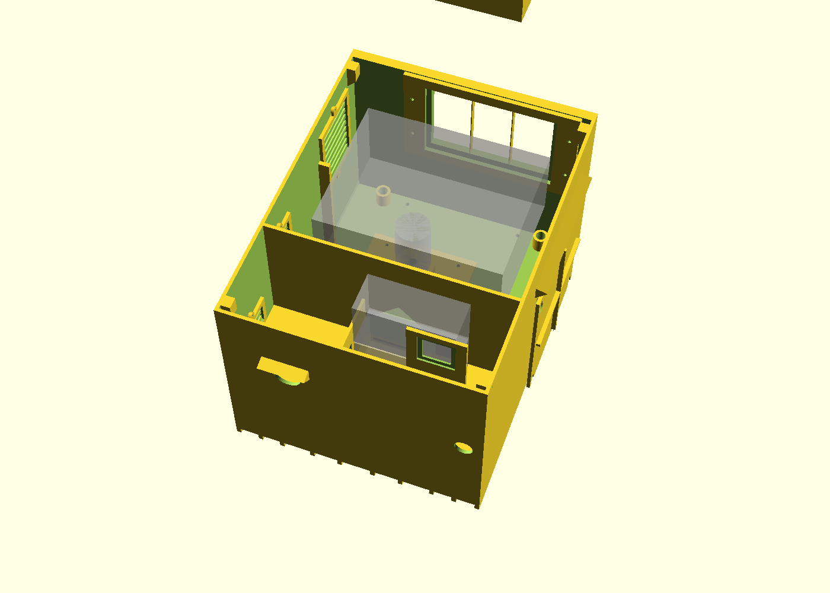
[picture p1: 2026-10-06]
preview/interior.png

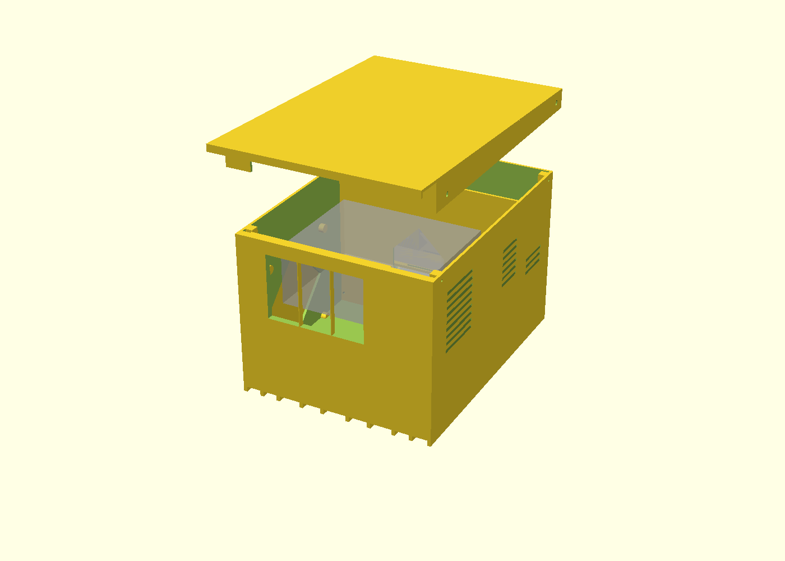
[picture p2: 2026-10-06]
preview/exploded.png

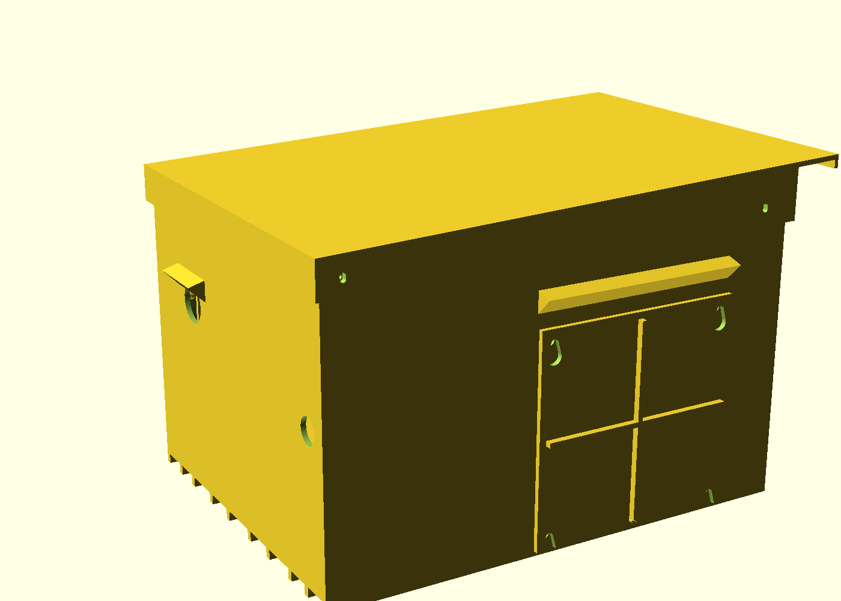
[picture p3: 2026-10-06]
preview/aim-hatch.png

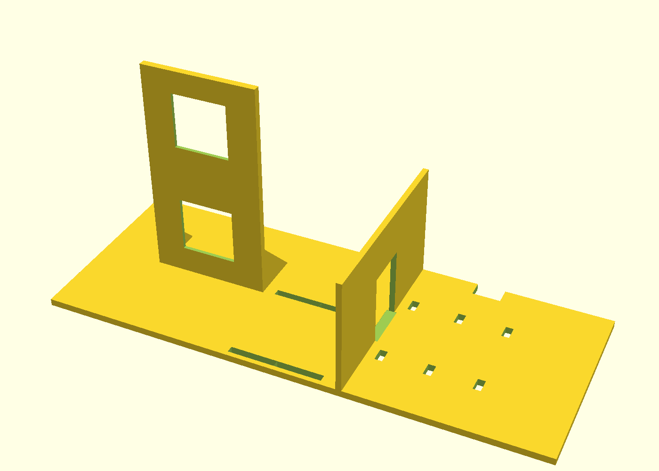
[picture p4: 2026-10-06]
preview/power-shelf-top.png

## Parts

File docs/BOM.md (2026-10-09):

# Bill of materials

Quantities for one case. Printed parts and filament are in [PRINTING.md](PRINTING.md); wire gauges and the protection notes are in [WIRING.md](WIRING.md). Sizes marked "check" depend on parts you haven't bought yet.

**Buy links:** Micro Center (Santa Clara store) where they stock it, otherwise Amazon; acrylic from TAP Plastics. Every link was opened on 2026-10-05; stock and prices move, so treat them as a starting point. Micro Center links carry `storeid=195` so the page shows Santa Clara stock.

## Order status (2026-10-06)

Amazon cart placed or about to be: 12 SKUs, $145.32 with tax (checkout PDF). Rows below say **Ordered** or **Not ordered**.

**Single-supply change (2026-10-06, rev 2):** the ordered second SS-6B (both are now spare), PG9 grip, uxcell fuse holders, BOJACK fuses, BAOMAIN quick-connects, generic Wago connectors and the Facmogu 24 V 3 A are not needed in the baseline build. The Facmogu can run the row 4a bench test if the brick is late, but that proves nothing about the Parts Express brick: re-run row 4a briefly on the real brick, or confirm with a meter that its output is not higher than the Facmogu's.

**Still to buy**
- Safety-critical: the brick, its cord, the Y-splitter, and the weatherproof connection box.
- Fasteners: M4 x 12 bolts, the M3 knurled thumbscrew, and (unless the hot-shoe slot works) the 1/4-20 insert and stud.
- Everything else outside the cart: the Pi, DigiAMP+, microSD, PIR, speakers and wire, HDMI cable and right-angle adapter, the 3.5 x 5 in frame, foam tape, silicone, screen, paint, filament.

## Core

| Item | Qty | Notes | Buy |
|---|---|---|---|
| Mini projector, 1/4-20 tripod socket, HDMI-CEC if possible | 1 | 165 x 130 x 66 mm (depth measured, width and height from the manual) | Owned (Tkisko TO2). The [Amazon listing](https://www.amazon.com/dp/B0CKNBWDP1) was unavailable on 2026-10-05 |
| Mini ball head, rated above the projector's weight | 1 | Chosen: UTEBIT 20 mm (male 1/4-20 on top into the projector, female 1/4-20 underneath; 58 mm overall, 32 mm base, Amazon rates it 2.5 lb / 1.1 kg (other listings say 2.5 kg), against the projector's 0.72 kg, so confirm it holds the aim; the hot-shoe adapter in the box is not used) **Ordered 2026-10-06** ($7.99). | [Amazon: UTEBIT 20 mm mini ball head](https://www.amazon.com/dp/B06XKW7V14) |
| 1/4-20 double-ended stud | 1 | Pedestal insert to the head's bottom hole (both female) **Not ordered**: needed unless the hot-shoe slot on the coupon works; at about $5 it is cheap insurance. | [Amazon: SmallRig 828, 2-pack](https://www.amazon.com/dp/B007LTH1X2) |
| Raspberry Pi 3B/3B+, 4B, 5 or Zero 2 W | 1 | Print the matching sled | Micro Center: [Pi 5](https://www.microcenter.com/product/673712/raspberry-pi-5?storeid=195), [Pi 4B](https://www.microcenter.com/product/637834/raspberry-pi-4-model-b?storeid=195), [Pi 3B+](https://www.microcenter.com/product/601561/raspberry-pi-3-model-b?storeid=195). Zero 2 W is in-store only there, so [Amazon: Pi Zero 2 W](https://www.amazon.com/dp/B09LH5SBPS) |
| Raspberry Pi DigiAMP+ (SC2076) | 1 | 2 x 35 W class D, 12-24 V in (5.5 x 2.5 mm barrel or P5 hard-wire), powers the Pi at 5.1 V / 2.5 A; 40-pin pass-through header; 0-50 °C ([product brief](<https://pip-assets.raspberrypi.com/categories/765-raspberry-pi-digiamp/documents/RP-008138-DS-1-digiamp-plus-hat-product-brief.pdf>)) | [Micro Center: Raspberry Pi DigiAMP+](https://www.microcenter.com/product/631851/raspberry-pi-digiamp?storeid=195) (chosen over the HiFiBerry Amp4: same TAS5756M, half the price, in stock locally) |
| 2x20 GPIO header | 0-1 | Zero 2 W only (it ships without one); the DigiAMP+ passes the other pins through | [Micro Center: 52Pi 2x20 stacking header kit](https://www.microcenter.com/product/669727/52pi-2x20-40-pin-stacking-female-header-kit?storeid=195) |
| microSD card, 32 GB, high-endurance | 1 | | [Micro Center: SanDisk Max Endurance 32 GB](https://www.microcenter.com/product/651045/sandisk-32-gb-max-endurance-microsdhc-class-10-uhs-3-flash-memory-card-with-adapter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) |
| Outdoor speakers, 4-8 ohm | 2 | Placed behind the projection | [Amazon: Dual LU43PB pair](https://www.amazon.com/dp/B00081NX5U) (Micro Center only has Bluetooth speakers) |
| 3.5 x 5 in (127 x 88.9 mm) picture frame with acrylic (not glass) glazing, about 2 mm | 1 | Any 3.5 x 5 in frame; use only the glazing. Check the listing says acrylic/plastic, and measure the thickness (`pane_t`) | [Amazon: 3.5 x 5 in picture frames](https://www.amazon.com/s?k=3.5x5+picture+frame+acrylic). Fallback: 127 x 88.9 mm, 2 mm clear acrylic cut to size at [TAP Plastics](https://www.tapplastics.com/product/plastics/cut_to_size_plastic/acrylic_sheets_clear/508) |
| HDMI cable, about 0.5 m, thin and flexible, + right-angle adapter | 1 | Full-size (Pi 3), micro (Pi 4/5) or mini (Zero 2 W) at the Pi end, with a straight plug no bigger than 22 x 13 mm and 45 mm long (`hdmi_plug`); right-angle, low profile at the projector. The port is horizontal on a vertical right face and the cable must leave REARWARD along that face, so buy a left/right-turn (side-exit) adapter or a side-exit molded cable, not an up/down one. Keep-out: 16 mm along Y, 15 mm off the face (`side_port_depth`), cable run 8 mm (`side_cable_d`); measure your plug into `side_port_*`. Zero 2 W: a slim plug (under 12 mm wide), because a HAT post stands beside its port | Full-size: [Micro Center: QVS thin 1.5 ft](https://www.microcenter.com/product/458970/qvs-hdmi-male-to-hdmi-male-ultrahd-4k-thin-high-speed-cable-w-ethernet-15-ft-black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) + [QVS angle adapter 5-pack](https://www.microcenter.com/product/466128/qvs-high-speed-hdmi-ultrahd-4k-angle-adapter-%285-pack%29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), or [Amazon: Cmple ultra-thin 1.5 ft](https://www.amazon.com/dp/B003ZVTX04) + [VCE 90/270 deg adapters](https://www.amazon.com/dp/B00Y7UT6EK) (check these are the left/right-exit type before buying). Micro: [Amazon: FEELWORLD 2.5 mm micro-HDMI 1.5 ft](https://www.amazon.com/dp/B0CGHPN53B). Mini: [Amazon: FEELWORLD 2.5 mm mini-HDMI 1.5 ft](https://www.amazon.com/dp/B0CGHRRT55) |

## Power (see WIRING.md; mains inside the box)

| Item | Qty | Notes | Buy |
|---|---|---|---|
| Outdoor cord, SJTW 18 AWG or better, 3-wire | 1 | **Not needed now; the brick's own cord goes to the outlet. Keep only if the outlet is far: an extension cord's joint goes in the weatherproof box** | [Amazon: PLUGTUL 16/3 SJTW 25 ft](https://www.amazon.com/dp/B0B7JH3RHL). Micro Center's Inland cords don't state a gauge or jacket type |
| Power brick: Parts Express 24 V 5 A, 5.5 x 2.5 mm tip-positive | 1 | The one supply (120 W). Desktop brick: read the label on arrival (UL/ETL mark, AC inlet type, input current, tip polarity) and measure its body into `brick`. **Not ordered. Order now** (about three weeks to Halloween). | [Parts Express 24 V 5 A, 120-055](https://parts-express.com/24-VDC-5A-Switching-Power-Supply-with-2.5-x-5.5mm-Plug-120-055) (link unverified: 403 to the checker on 2026-10-06) |
| AC cord for the brick's inlet, 6 ft or longer, 3-wire if the inlet is 3-pin | 1 | A standard detachable cord with the molded connector that fits the brick's inlet (the type is on its label). Not outdoor-rated; owner accepts it for the Halloween 2026 run (about a month outside) and replaces it if the jacket is damaged. **Not ordered; match it to the brick's inlet.** | Any hardware store or Amazon; choose after reading the inlet type |
| 5.5 x 2.5 mm DC Y-splitter, 1 female to 2 male, leads rated 5 A | 1 | Feeds the projector (through the right-angle adapter) and the DigiAMP+. **Not ordered.** Find one with a stated 5 A lead rating, then open its page to confirm before adding the link; otherwise buy any splitter and fuse each leg to its lead's rating | Search "5.5 x 2.5 mm DC splitter 1 female 2 male"; add the verified link here |
| Buck converter to 21 V, at least 3.5 A out, 30 V in or more | 0-1 | Only if BRINGUP row 4a fails (the projector cannot take 24 V). Meter its output before it meets the projector | Not chosen; pick after the test |
| 2 mm foam gasket for the cord clamp | 1 | Same foam tape as the lid rim | See the foam tape row |
| M3 x 16 self-tapping | 4 | Cord clamp into its bosses: the stack is 6 (clamp) + 2 (foam) + 3 (wall) = 11 mm to the inner wall face, plus the 5 mm boss, and the pilot ends at the boss end, so about 5 mm engages. Boss depth caps engagement at 5 mm; if BRINGUP row 17a fails, raise `cord_boss` once the real brick is measured | Same Mikniri assortment as the pedestal (check it has 16 mm; otherwise buy M3 x 16 separately) |
| Right-angle DC barrel adapter, 5.5 x 2.5 mm male to 5.5 x 2.5 mm female | 1 | The projector's jack is 5.5 mm OD x 2.5 mm ID (owner, 2026-10-06), so the stock plug is the same size. The male end goes into the jack (stands out about 15 mm, `port_depth`) and the stock plug or its stub goes into the elbow's female end, so the stock cable's 45 mm bend runs along the rear face. A straight plug would need about 45 mm behind the rear face, which the rear tile can't take. Do not use the 2.1 mm variants **Ordered** (5-pack, $8.99). | [Amazon: GINTOOYUN 5.5 x 2.5 mm male-to-female, 5-pack](https://www.amazon.com/dp/B0BQGM4NBS) |
| Velcro strap, 20 mm | 1-2 | Through the shelf slots, round the brick | [Micro Center: VELCRO One-Wrap roll, 3/4 in x 4 ft](https://www.microcenter.com/product/657584/velcro-90302-one-wrap-roll-4%e2%80%99-x-075-black-%281-roll%29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) |
| Wire: 18 AWG (relay fallback only), 24 AWG | a few metres | | Micro Center: [18 AWG hook-up, 25 ft](https://www.microcenter.com/product/689131/leo-sales-ltd-hook-up-wire-300vhu-18-gauge-ul1007-copper-25ft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), [22 AWG stranded, 25 ft](https://www.microcenter.com/product/689133/leo-sales-ltd-wire-stranded-22-gauge-300v-orange-25-ft?storeid=195). Amazon: [20 AWG silicone kit](https://www.amazon.com/dp/B073RDG2J6), [24 AWG silicone kit](https://www.amazon.com/dp/B073RD76QD) |
| 16 AWG speaker wire | to suit | | [Amazon: Amazon Basics 16 AWG, 50 ft](https://www.amazon.com/dp/B006LW0WDQ) (Micro Center sells 16 AWG only by the 500 ft spool) |
| Weatherproof cord-connection box | 1 | For any extension-cord joint | [Amazon: Flemoon IP44 cord connection box](https://www.amazon.com/dp/B08696RNQL) |

## Sensors, control

| Item | Qty | Notes | Buy |
|---|---|---|---|
| HC-SR501 PIR motion sensor | 1 | | [Micro Center: Inland PIR module](https://www.microcenter.com/product/618776/inland-pir-motion-sensor-module?storeid=195) (HC-SR501 type) or [Amazon: HC-SR501 5-pack](https://www.amazon.com/dp/B07KBWVJMP) |
| Relay module, 5 V coil, opto-isolated, active-low | 0-1 | Only if the projector lacks CEC (BRINGUP row 9 fails). Needs the projector leg cut: see WIRING.md. Keep two of the ordered generic lever connectors for the relay splice. | [Micro Center: Inland single 5 V relay module](https://www.microcenter.com/product/659887/inland-single-5v-relay-module-for-arduino?storeid=195); confirm the trigger polarity on the board before wiring |
| 940 nm IR LED + 150 R resistor | 0-1 | Only if CEC fails. Driven straight from GPIO 16 (no transistor). | [Micro Center: Adafruit IR transceiver (940 nm emitter with driver + 38 kHz receiver)](https://www.microcenter.com/product/691617/adafruit-industries-infrared-ir-remote-transceiver-stemma-jst-ph-2mm-940nm-emitter-38khz-receiver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) covers this row and the next. Discrete: [IR LEDs](https://www.microcenter.com/product/456455/adafruit-industries-super-bright-5mm-ir-led-940nm-25-pack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), [resistors](https://www.microcenter.com/product/618896/inland-1-4-watt-1-resistors-610-pack?storeid=195) |
| TSOP38238 IR receiver | 0-1 | Bench tool, optional: learns the remote's power code once; not fitted in the case. | The Adafruit board above, or [Amazon: TSOP38238 + TSAL6200 LEDs, 5 each](https://www.amazon.com/dp/B09D3RGSHX) |

## Fasteners

| Item | Qty | Where | Buy |
|---|---|---|---|
| 1/4-20 heat-set insert | 1 | Pedestal **Not ordered**: the Ktehloy kit is metric only. | [Amazon: ruthex 1/4-20 heat-set inserts, 20-pack](https://www.amazon.com/dp/B09MTS6ZZQ) |
| M4 heat-set insert | 4 | Hatch studs **Ordered** (Ktehloy 400-pc metric kit M2-M6, $15.97); check the hole sizes on the coupon. | [Micro Center: Leo Sales heat-set insert kit (M3/M4/M5)](https://www.microcenter.com/product/675642/leo-sales-ltd-heat-set-insert-kit-%28m3-m4-m5%29?storeid=195) |
| M3 heat-set insert | 1 | Sled thumbscrew Same Ktehloy kit. | Same kit |
| M4 x 12 button-head | 4 | Hatch keyholes **Not ordered.** | [Amazon: M4 x 12 stainless button head, 100-pack](https://www.amazon.com/dp/B01H6EZRCS) |
| M3 x 12 (security screw) | 0-1 | Optional hatch lock (`hatch_lock`), for public-facing setups | [Amazon: M3 x 12 pin-Torx button head, 100-pack](https://www.amazon.com/dp/B07KY69KDZ) |
| M3 x 12 (pan head, or pin-Torx security) | 4 | Lid, through the skirt **Ordered**: 340-pc 304 stainless M3 x 5-20 mm button-head kit ($12.27, nineone). | [Amazon: M3 stainless button-head assortment, 340 pcs](https://www.amazon.com/dp/B0742D9WDV), or the pin-Torx pack above |
| M3 x 12 | 4 | Base seam, through the divider Same M3 kit. | Same M3 assortment |
| M3 x 10 self-tapping | 4 | Pedestal to floor **Ordered**: Mikniri 750-pc M1.7-M3 assortment ($7.99); the M3 lengths are unconfirmed. | [Amazon: M3 pan-head self-tapping assortment, 6-20 mm](https://www.amazon.com/dp/B07BTNDC6W) |
| M3 x 8 self-tapping | 4 | Window frame Same Mikniri assortment. | Same assortment |
| M3 knurled thumbscrew, 8 mm | 1 | Sled **Not ordered.** | [Amazon: MECCANIXITY M3 x 8 stainless thumb screws, 10-pack](https://www.amazon.com/dp/B0FC6FS6M3) |
| M2.5 x 6 self-tapping | 4 | Pi to sled Same Mikniri assortment (lengths unconfirmed). | [Amazon: uxcell M2.5 x 6 stainless self-tapping, 100-pack](https://www.amazon.com/dp/B01L7PDGXO) |
| M2 x 6 self-tapping | 10 | Screen caps (6), PIR (2) Same Mikniri assortment (lengths unconfirmed). | [Amazon: M1.7-M3 small self-tapping assortment](https://www.amazon.com/dp/B0GF1CHDVV) |

## Consumables

| Item | Notes | Buy |
|---|---|---|
| PETG or ASA, about 1.3 kg, "Go Away Green" | Plus a little for reprints | [Micro Center: Inland ASA Army Green](https://www.microcenter.com/product/660561/inland-175mm-army-green-asa-3d-printer-filament-1kg-spool-%2822-lbs%29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) is the closest stock colour; [Inland PETG Green](https://www.microcenter.com/product/503782/inland-175mm-petg-3d-printer-filament-1kg-%2822-lbs%29-cardboard-spool-green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) is brighter. Match by eye |
| Flame-retardant PETG (UL 94 V-0, e.g. Prusament PETG V0), about 0.1-0.3 kg | Recommended for `power_shelf` (and `base_rear`, if the colour works): the brick and its cord inlet sit there | [Prusa: Prusament PETG V0 Jet Black](https://www.prusa3d.com/product/prusament-petg-v0-jet-black-1kg/) or [Amazon](https://www.amazon.com/dp/B0GP79Z9WY). Not at Micro Center |
| Foam tape, 2 mm (lid rim) and 1.5 mm (hatch) | | [Amazon: EPDM 2 x 20 mm, 10 m](https://www.amazon.com/dp/B0DFXQS5BL); [Amazon: 1/16 in (1.5 mm) x 1 in, 33 ft](https://www.amazon.com/dp/B08HV48WQV) |
| Neutral-cure outdoor silicone | Base seam, pane, PIR dome | [Amazon: GE Advanced Silicone 2, clear, 2.8 oz](https://www.amazon.com/dp/B001JK5R0I) |
| Insect screen, mosquito grade (about 18 x 16 mesh) | Caps | [Amazon: fiberglass window screen, charcoal](https://www.amazon.com/dp/B0CP2PY26C) (any hardware store roll works) |
| Matte black spray paint | Inside of the case, against light glow | [Amazon: Rust-Oleum 2X flat black](https://www.amazon.com/dp/B002BWOS7Q) |
| VHB tape, velcro strap, zip ties, foam plug for the chimney | | [Amazon: 3M VHB 5952, 1 in x 5 yd](https://www.amazon.com/dp/B007Y7H5W8); Micro Center: [8 in UV cable ties, 100](https://www.microcenter.com/product/657186/8-inch-black-uv-standard-cable-tie-100-pack?storeid=195), [VELCRO One-Wrap ties](https://www.microcenter.com/product/658953/velcro-90924-one-wrap-8-x-05-reusable-ties-black-%2850-pack%29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) |
| 8 mm tent stakes | 4, optional | [Amazon: forged steel 10 in stakes, 40-pack](https://www.amazon.com/dp/B072QB3L8S) |

## Ordering plan (for Halloween)

Printing takes 2 to 3 days on two printers and bring-up about a week, so order everything **now**: as of 2026-10-06 that leaves about three weeks to Halloween. The slow items:

| Item | Typical lead time | Order |
|---|---|---|
| Picture frame (glazing) | Same day at a craft or discount store, or a few days from Amazon | Any time |
| Zero 2 W (if used) | 2-5 days | Now |
| Filament (2 x 1 kg), fasteners, wire, silicone, screen | 1-3 days | Now |

Micro Center Santa Clara had the Pi boards, DigiAMP+, microSD, filament, PIR, relay, IR board, insert kit, hook-up wire, thin HDMI cable and cable ties in stock on 2026-10-05, so one trip covers those.

## Rough cost (excluding the projector)

These are estimates from typical retail prices, not quotes; check current prices.

| Group | Rough USD |
|---|---|
| Pi (one board) + microSD | 50-90 |
| DigiAMP+ | 30 |
| Speakers (outdoor pair) + wire | 50-120 |
| Ball head + stud | 15-35 |
| PIR | 5-10 |
| Power parts (brick, cord, Y-splitter, wire, connection box) | 45-70 |
| Acrylic pane | 10-25 |
| Inserts, screws, foam, silicone, screen, paint | 30-50 |
| Filament, about 1.3 kg | 30-60 |
| **Total** | **about 260-485** |

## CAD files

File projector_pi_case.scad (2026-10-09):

// Ground-standing projector + Raspberry Pi 3 case: rain-proof (not sealed), ventilated
// v0.10 - single supply: one desktop brick on the shelf (receptacle plate, barrier, second adapter and the PG9 gland replaced by a brick envelope, a rear-wall opening and a cord clamp).
// v0.10 - passive airflow: the projector's own fan, exhaust and inlet louver banks on the right wall, a lip baffle between them;
//         no case fans or sensors; photo-derived side-port keep-outs
// v0.9 - the stock supply is a wall-wart, so the shelf grew a receptacle plate: two panel-mount NEMA 5-15R stacked,
//        the stock 21 V wall-wart below and a second (Pi, DigiAMP+) above, hanging on their prongs; the AC gland
//        moved beside the plate, next to the left wall; Pi zone 85 deep; the fit coupon has the receptacle cutout
// v0.8 - AC gland moved above the shelf (AC side of the barrier); barrier clears the brick; keyholes lift off;
//        45 deg scarf joint at the lid seam; flat gasket land under the sloped roof;
//        audio: Raspberry Pi DigiAMP+ HAT on the Pi (also powers it), speaker wire out through a floor chimney;
//        Pi rides on a removable sled (Pi 3B/3B+, 4B, 5, Zero 2 W), shelf raised to clear the Pi 5 stack;
//        PIR motion sensor in the rear wall under a rain hood, for startle scares
// v0.7 - ONE AC cord in (rear gland) -> DC brick INSIDE on the power shelf, walled off from the low-voltage side;
//        a wire splice feeds the projector's barrel plug and the DigiAMP+ HAT (which powers the Pi).
// v0.4 - quick-aim hatch on the left (-X) wall: reach the ball head with the lid on, tool-free
// sized for a ~171x134x75 mm mini projector (0.72 kg) on an internal ball head
// Print PETG/ASA. Lid prints roof-down. Base+lid split front/rear (MK3S bed 250x210x210); front pieces lie flat with X along the 250 mm axis.

/* [Part] */
part = "assembly"; // [assembly, base, lid, window_frame, pedestal, hatch_cover, power_shelf, sled, ir_holder, vent_cap, exhaust_cap, intake_cap, fit_coupon]
sled = "pi3";      // [pi3, pi4, pi5, zero2w] sled shown in the assembly / exported by part="sled"
tile = "all";      // [all, front, rear] for base+lid
explode = 0;       // [0:1:80]
aim = [0, 0];      // [pan, tilt] deg of the ghost projector in the assembly preview

/* [Projector (mm)] */
// Verified 2026-10-05 from the projector's EDID (read on a Mac, docs/BRINGUP.md "Verified so far"):
// generic STK "S2-TEK TV" block (product 0x531A, dated 2014), HDMI input with CEC physical address 2.0.0.0,
// native 1080p60 (VIC 16), 8-bit only, TMDS <= 150 MHz, 2-ch LPCM audio, DPMS standby/active-off flagged.
// CEC itself is NOT proven (the address field is mandatory for any HDMI sink): see BRINGUP row 9.
// The EDID says nothing about size, lens or ports: those come from docs/measurements.xlsx (see below).
proj_w = 165;   // width (X): Tkisko TO2 manual says 6.5 x 5 x 2.6 in, lens on the 6.5 in face; confirm with calipers
proj_d = 130;   // depth (Y), lens faces front: measured 130.0 with calipers
proj_h = 66;    // height (Z)
lens_x = -20;   // lens offset from centre (+ = right): estimated from the product photo, measure it
lens_z = 33;    // lens centre height above projector underside: estimated from the product photo, measure it
throw_ratio = 0.95; // throw distance / image width: from the manual's image sizes (36 in at 2.5 ft, 72 in at 5 ft); measure it
aspect = 16/9;
port_depth = 15;    // HDMI + power plugs on the projector's rear face: right-angle plugs with slack (a straight HDMI plug needs ~40)
lens_offset = 0;    // vertical image offset: 0 = image centred on the lens axis, 1 = image bottom on the axis
pane_w = 127;   // pane: 3.5 x 5 in (127 x 88.9 mm) picture-frame glazing, the smallest stock size the light cone clears; the window opening is the pane minus lap
pane_h = 88.9;
pane_top_clear = 7;  // pane top this far below the base rim: the window sits as high as it can, for upward tilt
mount_x = 19;   // 1/4-20 socket offset from projector centre (+ = right): scaled off the underside photo, measure it
mount_y = -4;   // + = toward rear: scaled off the underside photo, measure it

/* [Ball head] */
ball_head_h = 52;  // UTEBIT 20 mm mini head (58 mm overall incl. ~6 mm stud, which screws into the projector): base to the platform the projector sits on, scaled off the vendor drawing
pivot_h = 32;      // ball centre above the head's base (aim pivot); UTEBIT: 30 mm body, 20 mm ball, scaled off the vendor drawing
aim_max = 15;      // tilt range the case must clear (check_clash.sh sweeps it)
pan_max = 10;      // pan range the case must clear: the light cone clips the window frame past this at throw_ratio 0.95 (turn the case for more)
cone_tilt = 11;     // light-cone check: the image must clear the window, frame and visor at +/- this tilt
aim_combo = 8;     // tilt while panned by pan_max (corners): the rear plugs reach the divider past this; more would lengthen base_front past the 210 mm bed axis
ped_top = 30;      // pedestal top height above floor
shoe_ch_w = 18.6;  // hot-shoe receiver (ISO 518, UNVERIFIED against the UTEBIT adapter; fit_coupon only so far): channel width under the lips
shoe_foot_t = 2;   // foot plate thickness (ISO 2 +0.15)
shoe_open = 12.5;  // opening between the lips
shoe_lip_t = 2;    // lip thickness: the adapter's ring clamps on this
shoe_foot_l = 18;  // foot length along the slide (guess: measure the adapter)
shoe_neck_d = 12;  // round neck between foot and ring (guess: measure the adapter)
shoe_clr = 0.3;    // clearance per side
insert_d = 8.2;    // 1/4-20 heat-set insert hole; check your insert's datasheet
insert_len = 9;

/* [Enclosure] */
wall = 3;
floor_t = 6;
foot_h = 6;        // ground clearance so rain drains out underneath
foot_ribs = [-88, -68, -40, -15, 15, 40, 68, 88];   // inner front-to-back ribs; two more run under the side walls. Floor bridges <= max_bridge (asserted); channels drain/vent/route wires
rib_t = 4;
layer_h = 0.2;     // print layer height: gap above the window's snap-out ribs
clearance = 0.3;
side_air = 25;     // gap each side of projector: clears the +/-10 deg pan sweep of the right face, the HDMI plug and the baffle; could shrink to about 19 mm (separate change)
top_air  = 25;
front_gap = 30;      // lens-down tilt swings the top front corner forward (more so panned, now the body is 165 wide); aim-sweep and light-cone checks size this
rear_gap  = 34;      // lens-up tilt swings the rear plugs back (port_depth) toward the divider; aim-sweep sizes this
pi_zone_d = 85;    // Pi compartment depth: the brick sits on the shelf toward the rear wall (asserted) and the shelf's low-voltage side needs wiring room
pane_t = 2;        // pane thickness: 2 mm (typical frame glazing; measure yours, 1/8 in = 3.2 also fits)
lap = 8;           // pane overlap past the window opening
boss_h = 4;

/* [Aim hatch (-X wall)] */
hatch = 108;         // diamond opening, tip to tip: reach in to loosen/aim the ball head (45 deg edges print unsupported); its hood must clear the lid skirt
hatch_flange = 10;   // cover overlap past the diamond's tips
hatch_zc = 56;       // opening centre height above floor: lower tip just above the floor, hood under the lid skirt (cover must lift kh_drop under the hood)
stud_off = 56;       // M4 stud spacing from opening centre
kh_drop = 8;         // keyhole slide distance: cover lifts this much to come off
m4_insert_d = 5.6;   // M4 heat-set insert hole; check your insert
hood_d = 10;         // rain hood depth over the hatch (must stay below the lid skirt)
cover_gasket = 1.5;  // foam tape thickness
hatch_lock = true;   // optional M3 (security) screw through the cover's bottom edge: stops it lifting off its keyholes
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

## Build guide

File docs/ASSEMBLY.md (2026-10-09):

# Assembly

In order. Parts are in [BOM.md](BOM.md); wiring is in [WIRING.md](WIRING.md) and must be followed exactly. Nothing here has been built yet, so expect to adjust.

1. **Fit coupon.** Print `fit_coupon` first. Press in each heat-set insert, drive each screw into its pilot, hang the keyhole on an M4 bolt, slide the frame glazing into its slot, and slide the ball head's hot-shoe adapter into the T-slot (an experiment: if it holds, the pedestal can drop the stud and insert). Adjust `insert_d`, `m4_insert_d`, `m3_insert_d`, `clearance` and so on in the SCAD until everything fits, then export the rest.
2. **Clean up the prints.** Snap out the two thin ribs in the window opening. Mask the window rebate, insert holes and screw holes, then spray the inside of both base halves and the lid matte black.
3. **Heat-set inserts.**
   - `base_front`: 4x M4 in the hatch studs (from outside).
   - `base_rear`: 1x M3 for the sled thumbscrew.
   - `pedestal`: 1/4-20 in the top.
4. **Screens.** Glue insect screen inside the three caps (`exhaust_cap`, `intake_cap`, `vent_cap`). Screw them over the right-wall louver banks (front bank: exhaust, rear bank: inlet, high bank over the shelf: the Pi vent), 2x M2 each.
5. **Join the base.** Silicone the joint faces, push the halves together and drive 4x M3 x 12 from the projector side through the divider into the rear half's collars. Wipe off the squeeze-out.
6. **Window.** Run a thin bead of silicone round the rebate, press the pane in, and screw the `window_frame` over it (4x M3 x 8).
7. **PIR.** Push the dome through the rear-wall hole from inside, screw the board on (2x M2), and seal round the dome outside with silicone.
8. **Projector mount.** Screw the `pedestal` to the floor (4x M3 x 10), add the stud and the ball head, and mount the projector. Fit the right-angle HDMI plug in the right-face I/O strip (cable pointing rearward) and the right-angle 5.5 x 2.5 mm adapter in the DC jack at the rear top-right corner (pointing back, above the intake). If BRINGUP row 4a passed, plug the Y-splitter's leg 1 into it; if it failed, fit the buck converter first (WIRING.md); otherwise leave leg 1 unplugged. If the IR fallback is built: stick the `ir_holder` (LED in it) on the projector's front face above the Tkisko logo, about 35 mm right of centre and 50 mm above the underside, body pointing toward the window. Run the IR LED lead up and back over the projector's top, held with tape, then through the right side gap past the baffle to the Pi.
9. **Power.** Note: the shipped provisional brick layout cannot be assembled (the brick sits across the cord opening); re-fit the shelf after BRINGUP row 4. Lid off, projector aside if needed. Seat the shelf on its ledges and lay the brick on it toward the rear wall, under the velcro strap. Pass the AC cord's connector in through the opening in the rear wall, plug it fully into the brick's inlet, then close the cord clamp over its foam gasket (4x M3 x 16 self-tapping into the wall bosses) and pull-test it (BRINGUP row 17a). Leave a drip loop outside below the clamp. Plug the brick's DC cord into the Y-splitter and meter both legs (centre +) before connecting anything. If the relay fallback is built, cut leg 1 and splice the relay as in WIRING.md.
10. **Pi sled.** Mount the Pi on its sled (4x M2.5), fit the DigiAMP+ (a Zero 2 W needs a 40-pin header soldered first), and plug the GPIO leads (PIR, and the relay and IR LED only if built) into the DigiAMP+'s pass-through header per `pi/README.md`. Set the sled on its pins and fit the thumbscrew. Plug the HDMI cable into the Pi straight through the low part of the divider pass-through (there is no room for the plug behind the divider), route the cable from there along the side gap above the baffle to the right-face I/O strip, and check BRINGUP row 21 (the cable crossing the rear gap at full tilt and pan). Plug the Y-splitter's leg 2 into the DigiAMP+'s barrel jack, and speaker wire down the chimney. Plug the chimney round the wires with foam.
11. **First power-up.** Follow the checklist at the end of WIRING.md before closing anything.
12. **Lid.** Stick 2 mm foam round the base rim, set the lid on, press it down onto the foam and drive the 4 side screws.
13. **Hatch.** Stick 1.5 mm foam round the hatch opening on the cover, and hang the cover on its keyholes.
14. **Software and aiming.** Flash and pair the Pi (`pi/README.md`), then place, stake, and aim ([AIMING.md](AIMING.md)).

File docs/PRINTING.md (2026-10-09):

# Printing plan

Two Prusa i3 MK3S (bed 250 x 210 x 210 mm), Prusament PETG (or ASA, which fades less in sun). Times and weights are PrusaSlicer's estimates from the current (v0.10, 3.5 x 5 in 2 mm pane) STLs with the stock `Original Prusa i3 MK3S & MK3S+` printer profile. Real prints run a little longer.

## Settings

- Print profile **0.20mm SPEED @MK3** for everything. The window's snap-out ribs leave a gap of one layer (`layer_h` = 0.2 in the model). If you print the base at another layer height, set `layer_h` to match and re-export.
- **No supports** anywhere: every part is designed support-free.
- Print `power_shelf` in flame-retardant PETG (UL 94 V-0, e.g. Prusament PETG V0, which has a stock profile), and `base_rear` too if you can live with its colour: the mains brick and its inlet connector live on the shelf in the rear compartment.
- The front tiles lie flat as exported: `base_front` is 231 x 207 mm and `lid_front` 228 x 204 mm, wide side along the bed's 250 mm axis. 207 mm on the 210 mm axis leaves no room for a skirt: turn it off or keep it tight to the part.
- The STLs are already in print orientation (lid roof-down, hatch cover ribs-up, window frame flat, caps plate-down).

## Parts

| Part | Qty | Time (0.20 SPEED) | PETG | Notes |
|---|---|---|---|---|
| `fit_coupon` | 1 | 1 h 42 m | 20 g | **Print first.** Test inserts, pilots, the keyhole on an M4 bolt, the frame glazing in its slot, the ball head's hot-shoe adapter in its T-slot |
| `pedestal` | 1 | 1 h 42 m | 29 g | |
| `window_frame` | 1 | 1 h 19 m | 20 g | |
| `hatch_cover` | 1 | 2 h 33 m | 46 g | |
| `sled_pi3` / `pi4` / `pi5` / `zero2w` | 1 | 1 h 8 m to 1 h 20 m | 18-19 g | The one for your Pi |
| `vent_cap` | 1 | 13 m | 2 g | Pi-zone louver |
| `intake_cap` | 1 | 15 m | 3 g | Rear inlet bank, wall-mounted |
| `exhaust_cap` | 1 | 22 m | 4 g | Front exhaust bank; the opening is about 74 x 58 mm, the biggest of the three caps |
| `ir_holder` | 0-1 | 11 m | 1 g | Only for the relay + IR fallback |
| `power_shelf` | 1 | 2 h 31 m | 47 g | Prints flat. Carries the brick (provisional envelope) |
| `cord_clamp` | 1 | 44 m | 11 g | Both halves in one print, flat, wall-face down. Holds the AC cord at the rear-wall opening |
| `lid_rear` | 1 | 6 h 41 m | 112 g | |
| `lid_front` | 1 | 9 h 45 m | 169 g | |
| `base_rear` | 1 | 18 h 44 m | 270 g | The 0.30mm DRAFT figure (13 h 25 m, 305 g) predates the rear-wall opening and was not re-sliced |
| `base_front` | 1 | **37 h 4 m** | 559 g | 26 h 55 m with 0.30mm DRAFT (615 g; set `layer_h = 0.3`) |
| **Total** | | **about 85 h** | **about 1.3 kg** | Two 1 kg spools. Re-sliced for the UTEBIT 20 mm ball head (`ball_head_h` 52), which only changed the two base tiles; `power_shelf`, `cord_clamp` and `base_rear` re-sliced for the single-brick power change. |

## Order, on two printers

The small parts first, so any fit problem shows up before a 37-hour print.

| Day | Printer A | Printer B |
|---|---|---|
| 1 | `fit_coupon`, then fix any tolerance in the SCAD and re-export | `pedestal`, `window_frame`, `hatch_cover` |
| 1-2 | (after the coupon checks out) `base_front` | `sled`, caps, `power_shelf`, `lid_rear` |
| 2-3 | `base_front` continues | `base_rear`, then `lid_front` |

**Hold `power_shelf` and `base_rear` until BRINGUP row 4 has set `brick`, `cord_*` and the brick's placement; the provisional layout puts the brick across the cord opening and cannot be assembled.** The Parts table shows what the provisional model slices to, not what to print yet.

About 2 to 2.5 days of printing if nothing fails. A failed `base_front` costs the most: watch its first layers, and consider the 0.30 DRAFT profile for it.

## After printing

- Snap out the two thin ribs in the window opening.
- Heat-set inserts: 1/4-20 (pedestal), M4 (hatch studs), M3 (sled thumbscrew). Use the sizes that fit the coupon.
- Spray the inside of the case matte black (masking the window rebate and screw holes) so projector light doesn't glow through the vents at night.

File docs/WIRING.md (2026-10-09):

# Wiring

> **Mains voltage is inside this box.** If you are not confident wiring mains, have a qualified electrician do the AC side. Nothing here has been built or tested yet; check every rating against the labels on your own parts.

This case is rain-shedding and ventilated, not waterproof, and not certified for anything.

## Overview

One diagram per side of the power shelf: [AC supply](#ac-supply) (the cord, the clamp and the 24 V brick) and [low voltage](#low-voltage-side) (on the shelf and down to the sled, drawn as the one DC rail and then the Pi's signals). Each comes twice: a schematic (`docs/wiring-*.svg`, drawn by `scripts/render_wiring.py` with [Schemdraw](https://schemdraw.readthedocs.io/); click one for full size) and a flowchart of the same connections. Red is live or +, grey is neutral or -, green is earth, blue is a signal. Pin numbers are the Pi header's physical pins; GPIO assignments and the reasoning behind them are in `pi/README.md` ("GPIO pins and wiring").

## AC supply

AC supply schematic: GFCI outlet, standard AC cord through the cord clamp into the 24 V brick's inlet; the brick's DC cord out

```mermaid
flowchart LR
  subgraph OUT["Outside the case"]
    direction LR
    GFCI["Outdoor GFCI outlet<br/>in-use cover; test its button"]
    BOX["Weatherproof connection box<br/>(any plug joint, off the ground)"]
    LOOP["Drip loop<br/>below the clamp"]
  end
  subgraph WALL["Rear wall, rear-left"]
    CLAMP["Cord clamp<br/>grips the jacket, foam gasket"]
  end
  subgraph SHELF["Power shelf"]
    BRICK["Parts Express brick<br/>24 V 5 A, 120 W<br/>cord plugs into its inlet"]
  end
  GFCI -- "standard cord, molded plugs, not cut" --> BOX --> LOOP --> CLAMP --> BRICK
  BRICK -- "24 V DC cord, not cut" --> DC["Y-splitter (below)"]
```

Nothing is hand-wired on the AC side: no stripped conductors, no spade terminals, no fuse holder. The cord's molded connector goes straight into the brick's inlet.

1. **Supply.** Plug into an outdoor GFCI outlet with an in-use weatherproof cover and test its button. Keep every plug-and-socket joint off the ground and out of puddles, in the weatherproof connection box.
2. **The cord.** A standard detachable cord with the right connector for the brick's inlet (read the inlet type off the brick's label: IEC C8, C14, C6 and so on). It is **not outdoor-rated**: the owner accepts that for the Halloween 2026 run (about a month outside) and replaces it if the jacket is damaged. Inspect the whole length daily; unplug and replace at the first nick, crack or soft spot.
3. **Entry.** The connector passes through the opening in the rear wall into the case and plugs into the brick; then the two halves of the cord clamp close round the jacket over a 2 mm foam gasket and screw into the wall's bosses (4x M3 x 16 self-tapping). The clamp is meant to take the pull; prove it with BRINGUP row 17a before the lid goes on. Leave a drip loop outside, below the clamp. Pull test before the lid goes on: a firm tug along and across the cord must not move the connector in the brick (BRINGUP row 17a).
4. **The brick** lies on the shelf under a velcro strap through the shelf slots, toward the rear wall. Its DC cord is not cut.
5. **No AC fuse.** There is no hand-wired AC conductor left to protect: the cord and brick are molded parts. The brick must be UL/ETL listed (check its label) and has its own protection, and the GFCI/branch breaker is upstream. If you would rather have one, buy an inline-fused cord for the brick's inlet type.
6. **Earth.** If the brick has a 3-pin inlet, use the 3-wire cord. A 2-pin Class II inlet needs none.

Mains is still present inside the printed box (the cord's connector and the brick's inlet). Print the shelf in flame-retardant PETG as before.

## Low-voltage side

On the shelf, and down to the Pi sled.

### DC rail

DC rail schematic: the 24 V brick's cord into a 5.5 x 2.5 mm Y-splitter, one leg to the projector's right-angle adapter (through a relay contact and a buck converter only if needed), the other to the DigiAMP+'s barrel jack, which powers the Pi and the speakers

```mermaid
flowchart TB
  BR["Parts Express brick, 24 V 5 A<br/>DC cord NOT cut; tip centre + (confirm with a meter)"]
  SPL(["5.5 x 2.5 mm Y-splitter<br/>one female in, two males out"])
  subgraph PJ["Projector (label 21 V)"]
    BUCK["Buck converter to 21 V, ONLY if row 4a fails"]
    RELAY["Relay contact, ONLY if CEC fails<br/>cut this leg; + line only"]
    ADP["Right-angle 5.5 x 2.5 adapter<br/>on the projector's DC jack"]
  end
  subgraph PIZ["Pi sled, below the shelf"]
    AMP["Raspberry Pi DigiAMP+<br/>barrel jack, centre +"]
    PI["Raspberry Pi<br/>5 V from the DigiAMP+ via the header<br/>no USB power"]
    SPK["Speakers behind the projection<br/>16 AWG zip cord, stripe to +<br/>out through the floor chimney"]
  end
  BR --> SPL
  SPL -- "leg 1" --> RELAY --> BUCK --> ADP
  SPL -- "leg 2" --> AMP
  AMP --> PI
  AMP --> SPK
  linkStyle 0,1,2,3,4,5,6 stroke:#c62828,stroke-width:2px
```

One rail, one return: the Y-splitter joins both loads' minuses at the supply, so there is no second rail to tie in and no ground path through the HDMI shield. Nothing on the DC side is cut or spliced in the baseline build. The projector's label says 21 V and the brick makes 24 V: **leg 1 is not connected to the projector until BRINGUP row 4a (projector on 24 V) has passed.**

**Check the polarity before connecting either load.** With the brick plugged in and nothing else connected, meter each Y-splitter leg's tip: it must read 24 V with the **centre positive** (the brick's label, the projector's label symbol and the DigiAMP+'s jack all say centre +). If either leg reads negative, stop: the splitter is wired the wrong way round for this supply.

The DigiAMP+ powers the Pi, so never also power the Pi by USB. The relay is only needed if the projector lacks HDMI-CEC (see `pi/README.md`, "Projector power"). It is also the only way the Pi can cut the projector's power if the Pi itself overheats: with CEC alone it can only ask for standby. **If you fit it:** cut leg 1 a hand's width from the adapter, put the relay's COM and NO in the **+** conductor only, and splice with the lever connectors (BOM relay row). Never switch the minus: the HDMI cable would carry the return. Use an **active-low** module: the Pi holds GPIO 27 high (relay open, projector off) from boot.

| Circuit | Wire | Notes |
|---|---|---|
| Brick DC cord into the Y-splitter | the cord's own | Plug-in; the cord is not cut. Tip must read centre + |
| Y-splitter leg 1 to the projector | the splitter's own | **Leads rated for the supply's 5 A, or a fuse in each leg sized to the lead's rating.** Ends in the right-angle 5.5 x 2.5 mm adapter on the projector's DC jack so the stock cable's bend runs along the rear face. **Do not connect it until row 4a passes.** If row 4a fails, a buck converter to 21 V goes between the splitter and the adapter on this leg only (at least 3.5 A out at 21 V, 30 V in or more; meter its output before it meets the projector) |
| Y-splitter leg 2 to the DigiAMP+ | the splitter's own | Into the DigiAMP+'s 5.5 x 2.5 mm centre-positive barrel jack. 24 V is its stated ceiling |
| Relay (CEC fallback only) | 18 AWG | Cut leg 1 a hand's width from the adapter and switch the **+** conductor only. Never switch the minus: the HDMI cable would carry the return. Use an **active-low** module: the Pi holds GPIO 27 high (relay open, projector off) from boot |
| DigiAMP+ to speakers | 16 AWG zip cord | Out through the floor chimney; red/striped to + on both ends |

Pass low-voltage wires from the shelf to the Pi through the wire slot at the back of the shelf; the DigiAMP+ leg's barrel plug must fit it (BRINGUP row 4).

**Projector cables.** The DC barrel plug goes on the projector's rear face, top-right corner: put the right-angle 5.5 x 2.5 mm adapter from the BOM on the jack, pointing back. HDMI goes on the I/O strip on the right face: use a right-angle plug, and run the cable back along the side gap above the baffle. Leave USB, AV and Type-C unplugged; their plugs would foul the side gap.

### Pi header signals

Pi header schematic: the 40-pin header with the PIR, and the relay coil and IR LED (both only if CEC fails)

```mermaid
flowchart LR
  subgraph IN["Inputs"]
    PIR["HC-SR501 PIR, rear wall<br/>VCC 5 V pin 2, GND pin 9"]
  end
  PI["Raspberry Pi header<br/>(the DigiAMP+'s pass-through header;<br/>GPIO 2-4, 18-21 and 22 belong to the DigiAMP+)"]
  subgraph OUTS["Outputs, only if CEC fails"]
    RELAY["Relay module IN, active-low<br/>VCC 5 V pin 4, GND pin 14"]
    IRLED["940 nm IR LED in ir_holder<br/>via 150 R to GND"]
  end
  PROJ["Projector HDMI input"]
  PIR -- "OUT to GPIO17, pin 11" --> PI
  PI -- "GPIO27, pin 13" --> RELAY
  PI -- "GPIO16, pin 36, through 150 R" --> IRLED
  PI -. "HDMI (CEC power control, the default)" .-> PROJ
```

The DigiAMP+ re-exposes the header on top, so the leads plug into its pass-through header (a Zero 2 W needs its own 40-pin header soldered first). GPIO 22 is the DigiAMP+ mute line, which is why the IR LED sits on GPIO 16. The relay and the IR LED are built only if bring-up row 9 shows the projector ignores CEC. The LED needs no transistor: from 3.3 V through 150 R it draws about 13 mA, under a pin's 16 mA, and it sits centimetres from the projector's receiver; if row 22 shows it too weak, add a BC337 and 1 k. The TSOP38238 receiver (GPIO 23) is a bench tool to learn the remote's code, not part of the case.

## Cords outdoors

Trick-or-treaters walk through the yard in the dark. Run the power cord and speaker wires along edges, not across paths. Where they must cross a path, use a rubber cord cover (cable ramp), or bury or stake them flat. Keep every plug joint in a weatherproof connection box, off the ground.

## Protection

**No AC fuse and no DC fuse in the baseline.** The AC side has no hand-wired conductor to protect (see "AC supply"). The brick limits its own output and carries its own short-circuit protection. The one place a fault could heat a wire is the Y-splitter's leads: a 5 A supply can overheat leads rated for less. Buy a splitter whose leads are rated for 5 A, or put a small inline fuse in each leg sized to that leg's lead rating. Use a UL/ETL-listed brick (read its label on arrival) and keep the total load under its 120 W.

## Before first power-up

1. With nothing plugged in, check the cord's continuity end to end and that the connector seats fully in the brick.
2. Brick plugged in, loads unplugged: meter each Y-splitter leg's tip (24 V, centre +).
3. Projector tested on the brick on the bench (BRINGUP row 4a) before leg 1 is connected.
4. Connect the DigiAMP+ (the Pi should boot), then the projector.
5. Close the lid, then test the GFCI outlet's trip button with the case running: everything must go dark.

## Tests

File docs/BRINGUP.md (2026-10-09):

# Hardware bring-up checklist

Everything below has only been tested in software. Work through it on the bench before the case goes outside, and record results in the design log. Each line has a pass criterion. If one fails, the "if not" column says what changes.

## Verified so far

- **Projector EDID (2026-10-05, read on a MacBook with `ioreg -l | grep EDID`, decoded by hand).** The projector presents a generic STK "S2-TEK TV" EDID (product 0x531A, block dated 2014, serial SN-000000001), so the identity is the HDMI SoC's, not the projector maker's. Native mode 1080p60 (VIC 16); also 1080p24/30/50, 1080i50/60, 720p50/60 and the SD modes. 8-bit RGB and YCbCr only, max TMDS clock 150 MHz: no 4K, no HDR, no deep colour. Audio: 2-channel LPCM at 32/44.1/48 kHz (unused; audio goes to the DigiAMP+). The feature byte claims DPMS standby, suspend and active-off, which is what the `hdmi-off` power mode relies on. The HDMI vendor block carries CEC physical address 2.0.0.0 with Supports_AI set, so the input is real HDMI rather than DVI-over-HDMI. **That does not prove CEC works**: the address field is mandatory for every HDMI sink and 2014-era STK projectors often omit CEC, so row 9 still decides. Hot-plug detect was reported active, so the Pi's HDMI wait (row 9a) should see it. Set the Pi to 1080p60 and nothing higher. The EDID carries no geometry (its 93 x 53 cm screen size is a placeholder), so rows 2 and 3 are unchanged.
- Apple's [HDMI-CEC Support on Mac](https://support.apple.com/en-us/108928) page says some Macs do CEC: Mac Studio (M4 Max or M3 Ultra, 2025), MacBook Pro (M3 Pro/Max or later), Mac mini (M4 or M4 Pro), and any Apple silicon Mac on macOS 14.4+ through Apple's USB-C Digital AV Multiport Adapter or the Belkin Connect USB-C to HDMI Adapter. The owner's Mac Studio (M3 Ultra, 2025) qualifies. macOS only syncs display wake/sleep with the Mac and exposes no way to send arbitrary CEC commands, so row 2b is a pre-check; row 9 on the Pi still decides.
- Mac Studio M3 Ultra, `ioreg` look for a private CEC interface (2026-10-06, macOS 27.2): the device tree has a `dp2hdmi-gpio1` node (the DisplayPort-to-HDMI converter) with `function-hdmi_cec_en` next to `function-hdmi_hpd`, `function-dp2hdmi_pwr_en` and `function-reset`, so the CEC hardware is there and a GPIO enables it. No IOKit class or property carries CEC, though. The one user-reachable candidate is `DCPAVServiceProxy` (two `Location = External` instances with a `DCPAVServiceProxyUserClient`, the interface DDC tools such as `m1ddc` use); whether it carries CEC is untested. The CEC traffic most likely lives in the display coprocessor firmware, which fits Apple documenting only wake/sleep sync. Not worth reverse-engineering for this project: the Pi sends the commands.

## Before the big prints

| # | Test | Pass | If not |
|---|---|---|---|
| 1 | `fit_coupon`: heat-set inserts (1/4, M4, M3), screws in the M3/M2.5/M2 pilots, M4 bolt in the keyhole, acrylic in the slot, the UTEBIT head's hot-shoe adapter in the T-slot (slides in from the left edge; ring clamps on the lips; check it can't wobble or slide out); measure the 118 mm strip once cool and enter it in the sheet's shrink row | Each fits snug, with no cracking and no slop; the sheet's pane clearance after shrink says ok | Adjust `insert_d`, `m4_insert_d`, `m3_insert_d`, `clearance`, `shoe_*`, re-export; if the shoe holds, move `hot_shoe_cut()` into the pedestal and drop the stud and insert |
| 2 | Measure the projector into `docs/measurements.xlsx`: width and height (depth is done: 130.0), lens height and left/right offset, tripod socket position, vents, **where the HDMI and power ports are** (photos put the I/O strip on the right face, top 18 mm, 41-118 mm behind the front, HDMI at 56 mm, and the DC jack in the rear top-right corner: confirm with calipers), **the exhaust and intake grille extents**, plus the focus wheel and the IR receiver (on the front face above the logo, near X +35, Z 50). The sheet's Site rows (throw distance, surface height) compute the tilt you need; do them before printing the big tiles | Within a few mm of `proj_w/d/h`, `lens_z`, `lens_x`, `mount_x/y`, `dc_jack`, `hdmi_y`, `side_port_*`, `ir_x`/`ir_z` | Update the flagged parameters, run `scripts/check_clash.sh` |
| 2a | Signal-loss standby, from the Mac: with the projector showing the Mac's desktop, sleep the Mac and time how long the projector takes to blank, then wake the Mac | The projector blanks (or goes to standby) by itself within a few minutes and the picture returns when the signal does | `hdmi-off` mode won't save the lamp at night; plan on `relay` or `relay-ir` |
| 2b | CEC pre-check from the Mac Studio (HDMI to the projector, projector in standby first). Apple menu > Sleep, watch the projector, then wake the Mac. Repeat once with the HDMI cable pulled while the Mac sleeps, to separate CEC from plain signal loss | Projector goes to standby on Mac sleep and wakes with the Mac, and still does so when the signal-loss case (row 2a) is ruled out, e.g. it reacts within seconds rather than after the no-signal timeout | No reaction, or only the slow no-signal blanking: the projector likely ignores CEC, so plan on `relay-ir`, but confirm with row 9 on the Pi |
| 3 | Throw ratio and offset: project onto a wall from a measured distance, and measure image width and how far the bottom edge sits above the lens | Throw ratio about 0.95, offset recorded; the Site rows' tilt stays under `cone_tilt` (11 deg) | Set `throw_ratio`, `lens_offset`; check the `light-cone` result |
| 4 | The brick, on arrival: read the label (UL/ETL mark, AC inlet type, tip polarity, input current), photograph it, and measure length, width and height with calipers into `brick`; measure the cord's jacket into `cord_d` and the connector's face into the opening check | Brick fits on the shelf (`brick_x0 + brick[0] + 3 <= pir_x - 6`), inlet type known, the connector passes the 40 x 30 mm opening, the connector plus its cord bend fit between the wall and the brick's inlet, the brick's DC cord has room to exit to the Y-splitter and the wire slot, the DigiAMP+ leg's barrel plug passes the wire slot, and the brick's no-load output is at most 24 V (if above 24 V, do not connect the DigiAMP+ and do not use the brick) | Set `brick`, `cord_d`, `cord_open`, `wire_slot`; rerun `scripts/check_clash.sh`; reprint `power_shelf` (and `base_rear` if the opening changed) |
| 4a | **Projector on 24 V.** On the bench, meter the brick's output first, then run the projector from it for 10 minutes at full brightness | Output at most 24 V no-load (if above 24 V, do not connect the DigiAMP+ and do not use the brick). Projector runs normally, no smell, no unusual heat, no shutdown, picture normal | Do not connect 24 V to it. Buck converter to 21 V on the projector leg only (WIRING.md) |
| 4b | **Shared rail.** Needs the Pi image and the DigiAMP+ working first (rows 6-8). With the brick feeding the projector, the Pi and the DigiAMP+ at the volume you will use, play the show and the loudest cue | No hum from the speakers, no picture flicker, brick stays only warm | Check the splitter and the leads; try a ferrite or a small electrolytic across the DigiAMP+ supply input, or as a last resort power the DigiAMP+ from a separate wall supply; if the brick is too hot in its spot, vent the shelf |
| 5 | UTEBIT head: platform height (52) and ball centre (32) with calipers, and where the lock knob sits | Knob reachable through the hatch diamond | Change `ball_head_h`; move the hatch (`hatch_zc`) |

## Pi on the bench (before it goes in the case)

| # | Test | Pass | If not |
|---|---|---|---|
| 6 | Flash the image onto a fresh card (release image through Imager's repository JSON, or your own build; or `install.sh`), first boot | One extra reboot, then `videofx-xxxx.local` answers, the name shows as VideoFX-XXXX and your user can log in. `videofx-maint status` says protected, `lsblk` shows three partitions, and `ssh` doesn't warn about a changed host key after a second reboot | `journalctl -b -u videofx-storage` (and `-u cloud-final` on the release image); see `pi/README.md` Install and troubleshooting |
| 7 | Storage protection: `videofx-maint status`, then pull the power mid-upload | Overlay on, data partition mounted, settings intact after the cut | Leave protection off for Halloween; report it |
| 8 | DigiAMP+ powers the Pi (especially a **Pi 5**) at full volume | No undervoltage warnings (`vcgencmd get_throttled` = 0x0) | Use a Pi 4B sled (Raspberry Pi says not to feed the Pi's own power input while the DigiAMP+ is fitted) |
| 9 | HDMI-CEC with your projector: power on/off from the web page. The EDID has a CEC physical address (see "Verified so far"), so the bus exists; this row is the only test of whether the projector listens. On the Pi, `cec-ctl -d /dev/cec0 --playback -S` should list a TV at logical address 0 | Projector wakes and sleeps; page says "CEC supported" | Build the fallback: relay (cut the projector leg, + line only) and the IR LED on GPIO 16 through 150 R; learn the remote's code with the bench TSOP38238 |
| 9a | Projector powered after the Pi: with playback on, pull the projector's power for 10 s and restore it (or use relay mode and switch off and on) | The picture comes back by itself; the journal says "HDMI display connected" | Add the `video=` line from the README's troubleshooting (for this projector `video=HDMI-A-1:1920x1080@60D`, its native mode) |
| 9b | Relay mode only: `sudo systemctl stop videofx-player`, then `sudo systemctl kill -s KILL videofx-player` while playing | The relay opens (projector off) both times | Check `videofx-relay-open` and that `pinctrl` is installed |
| 10 | Scare seam: calm clip to scare and back, then `journalctl -u videofx-player \| grep seam` | No visible black frame (log shows under about 100 ms) | Re-encode per the README; try `--hwdec=v4l2m2m-copy` on Pi 3 / Zero 2 W |
| 11 | Video decode: your AtmosFX files at their native resolution | Smooth, CPU under about 70% | Transcode with the README's ffmpeg commands |
| 12 | PIR: walk toward it from the street side | Triggers at the distance you want, not from passing cars | Adjust the sensor's sensitivity/time pots; aim the case |
| 13 | Pi over-temperature: set the critical temperature just above the Pi's idle temperature (Settings > Cooling) | Playback and projector stop with a clear alarm; resume after the hysteresis | Report it; do not run unattended |
| 14 | Pairing: add to Apple Home ("Add Anyway"), toggle power, fire a scare from an automation | All four endpoints appear and work | See `pi/README.md` Matter notes |
| 14a | Boot with the Wi-Fi access point off, state "on" | It plays, and `systemctl status videofx-player` stays "active (running)" for 5 minutes with no restarts | Report it |
| 14b | Schedule catch-up: with "on at 18:00" set, pull the Pi's power at 17:55 and restore it at 18:05 | It switches on within a minute of boot (once the clock is set) | Set "After a power cut" to on for the night |
| 14c | Open `http://videofx-xxxx.local/` from an iPhone on the same Wi-Fi | The page loads (not "LAN only") | Report the phone's and the Pi's addresses |
| 15 | DMX: send from QLC+/xLights/FPP (unicast) to the Pi's universe | Page shows the source; power, clip and volume follow | Check universe/address and UniFi multicast settings |
| 16 | Update and rollback: `videofx-update --tarball` with the release tarball, then `--rollback` | Both complete and the page shows the right version | Report it |

## In the case

| # | Test | Pass | If not |
|---|---|---|---|
| 17a | **Cord clamp pull test.** Cord through the opening, plugged into the brick, clamp closed on its foam gasket with 4x M3 x 16, the cord's outlet end unplugged (done before power-up); tug firmly along the cord, then at 45 degrees and sideways, ten times each | The connector does not move in the brick's inlet; the cord does not slide in the clamp; no part of the clamp cracks | The clamp's grip comes from its geometry (0.3 mm radial interference), not from tightening, so the halves can float on their clearance holes. Remedies, in order: (1) a tighter channel (`cord_d` - 1 or - 2) with ribs in the channel; (2) slot the wall pilots and clamp holes in Z so the halves can be pressed together; (3) add two ears with M3 screws across the split; (4) a zip tie round the cord just inside the clamp. If the screws pull out of the bosses, raise `cord_boss` (see BOM) |
| 17 | Wiring checklist in WIRING.md, then power up | Everything in its "Before first power-up" list passes; the GFCI trips cleanly | Stop and fix before continuing |
| 18 | Heat: run for 2 hours with the lid on, on a warm evening | The projector's own fan runs normally and its image does not dim or shut down; the Pi's SoC stays under the warning temperature | Check the louver banks and screens are not blocked; open the case's lid to isolate the Pi zone from the projector zone |
| 19 | Airflow (night, lid on): thin tissue at the exhaust bank blows outward, at the inlet bank is drawn inward; a thermometer at the rear intake reads within 3 C of ambient after 30 min | Both directions as stated; intake within 3 C | Recirculation: deepen the baffle (`baffle_d`) or move the banks apart; re-measure the louver openings |
| 20 | Pi zone: log SoC and shelf-top temperature over a warm night with the lid on | SoC under the warning temperature all night; shelf top well under the brick's rating | Add a second low louver on the left wall to complete a convection path |
| 21 | Port fit: the right-angle HDMI on the right face clears the baffle at +/-15 tilt, +/-10 pan. **The cable's route is not modelled in `check_clash.sh`**: check by hand that it runs from the right-face strip, along the side gap above the baffle, across the rear gap and into the divider pass-through at full tilt and pan, without being pinched or pulling on the plug. The DC plug clears the divider too | No strain, no kink, nothing pinched, no force on the plug at the extremes | Use a thinner or more flexible cable; shorten the run; make the rear gap bigger |
| 22 | IR LED holder: the LED seats in the holder, and the holder clears the window at the same extremes. `ir_holder_h` is 7 mm, which leaves a shallow seat | LED stays put when the case is knocked; holder clear of pane, frame and visor; the LED lead (up and back over the projector's top, through the side gap past the baffle) clears the lid and window frame at full tilt and pan | Glue the LED in; or raise `ir_holder_h` if the front gap allows; if the LED seems too weak with no transistor, add a BC337 and 1 k |
| 23 | Aim: full range per AIMING.md | Image clears the window at your aim; nothing rubs | Shim the case instead |
| 24 | Rain: 10 minutes of garden hose "rain" from above and the sides, running | Nothing wet inside beyond a few drops at the louvers | Silicone the leaks; do not run in heavy rain until fixed |
| 25 | Night check from the street | No glow from the vents; cords routed away from paths or covered | Paint the inside black; reroute the cords |

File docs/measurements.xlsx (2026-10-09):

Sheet: Measurements
AtmosFX projector case: hardware measurements
Fill in the yellow cells only. Default = current value in projector_pi_case.scad. Spec = what the Tkisko TO2 manual (manuals.plus, Oct 2022), its label and product photos says, in green; it is a manufacturer figure, not a measurement, so Measured overrides it. Flag says UPDATE when |Delta| is over the tolerance ('UPDATE (spec)' when only the manual disagrees): change that parameter, then run scripts/check_clash.sh and make parts. Rows without a parameter are context for the next step.
Date measured |  | Projector | Tkisko TO2 (model C11)
Group | Measurement | Parameter | Default | Unit | Spec (manual) | Measured | Delta | Tolerance | Flag | How to measure / notes
EXAMPLE | Example: width measured 137.5 against a default of 135 | proj_w | 135 | mm | 165 | 137.5 |  | 1 |  | Delete this row once you start. It only shows the expected format.
Projector | Width (X, across the front) | proj_w | 165 | mm | 165 |  |  | 1 |  | Manual: 6.5 x 5 x 2.6 in (spec table says 6 x 5 x 2.5); lens is on the 6.5 in face (owner). Measure: the base is 231 wide with the hood, on a 250 mm axis.
Projector | Depth (Y, lens face to rear face) | proj_d | 130 | mm | 127 | 130 |  | 1 |  | Measured 130.0 with calipers (photo). base_front is 207 on the 210 mm bed axis, so this cannot grow.
Projector | Height (Z, underside to top) | proj_h | 66 | mm | 66 |  |  | 1 |  | Underside sits on the ball head plate. Manual: 2.6 in.
Projector | Lens centre height above underside | lens_z | 33 | mm | 33 |  |  | 2 |  | Centre of the lens, not the bezel. Spec is scaled off the product photo.
Projector | Lens offset from body centre (+ = right, viewed from front) | lens_x | -20 | mm | -20 |  |  | 2 |  | Lens is in the left lobe. Spec is scaled off the product photo; the window frame follows this value.
Projector | 1/4-20 socket offset from centre, X (+ = right) | mount_x | 19 | mm | 19 |  |  | 2 |  | Brass insert in the right lobe (underside photo). Spec is scaled off the photo; measure from the body centre.
Projector | 1/4-20 socket offset from centre, Y (+ = toward rear) | mount_y | -4 | mm | -4 |  |  | 2 |  | Slightly forward of centre in the underside photo.
Projector | 1/4-20 socket recess depth |  |  | mm |  |  |  |  |  | How far the stud must reach. Compare with the ball head stud length.
Projector | DC jack centre: inset from the right edge (rear face, top-right corner) | dc_jack[0] | 15 | mm | 15 |  |  | 2 |  | Photo-derived (2026-10-06 owner photos); confirm with calipers. Barrel centre, measured from the projector's right edge.
Projector | DC jack centre: below the projector's top | dc_jack[1] | 13 | mm | 13 |  |  | 2 |  | Photo-derived (2026-10-06 owner photos); confirm with calipers. Barrel centre, measured down from the top edge. Sets the DC plug keep-out; the plug must point back and stay above the intake patch.
Projector | Plug protrusion behind the rear face | port_depth | 15 | mm |  |  |  | 3 |  | Right-angle DC plug standing out of the rear face, cable bent the way it will run. (HDMI is on the right face now, so this is the DC plug only.)
Projector | HDMI centre behind the front face (right face I/O strip) | hdmi_y | 56 | mm | 56 |  |  | 3 |  | Photo-derived (2026-10-06 owner photos); confirm with calipers. The strip spans about 41-118 mm behind the front face; measure the HDMI port centre. Sets the plug keep-out (side_port_*) and where the baffle stands.
Projector | Right-face I/O strip height, from the top | side_port_h | 18 | mm | 18 |  |  | 2 |  | Photo-derived (2026-10-06 owner photos); confirm with calipers. Top strip holding HDMI, USB and AV. Sets baffle_gap (the baffle stops this + 4 mm below the top) and the HDMI cable keep-out.
Projector | Barrel plug outer diameter |  |  | mm |  |  |  |  |  | Sizes the relay pigtail and the inline DC fuse holder (docs/WIRING.md). Inner pin diameter in Observations.
Projector | Barrel plug length, body plus strain relief |  |  | mm |  |  |  | 3 |  | Straight out from the rear face. If it is longer than the HDMI plug it sets port_depth, not the HDMI.
Projector | Lens barrel protrusion past the front face |  |  | mm |  |  |  | 1 |  | 0 if the lens sits behind a flush window. Anything proud eats into front_gap (30) on downward tilt.
Projector | Lens bezel diameter |  |  | mm |  |  |  |  |  | Clear window opening is the pane minus the lap: 111 x 86 mm. The light cone, not the bezel, is what the check sweeps, so this is context.
Projector | Focus wheel height above underside |  |  | mm |  |  |  | 5 |  | Which face is in Observations. The projector underside is 70 above the floor and the hatch diamond reaches 110, so only the lower 40 mm of the left face is reachable with the lid on.
Projector | Keystone control height above underside |  |  | mm |  |  |  | 5 |  | Same reach limit as the focus wheel.
Projector | IR receiver window height above underside (front face, above the logo) | ir_z | 50 | mm | 50 |  |  | 3 |  | Photo-derived (2026-10-06 owner photos); confirm with calipers. ir_holder sticks on the projector's front face here, body pointing toward the window; it fires at the receiver from inside the front gap.
Projector | IR receiver position along the front face, X (+ = right of centre) | ir_x | 35 | mm | 35 |  |  | 3 |  | Photo-derived (2026-10-06 owner photos); confirm with calipers. Measure from the body centre.
Projector | Rear intake patch: size (square) | in_size | 40 | mm | 40 |  |  | 2 |  | Photo-derived (2026-10-06 owner photos); confirm with calipers. The rear-face grille the inlet bank feeds; the speaker grille beside it is not an air path. Sizes the inlet opening.
Projector | Rear intake patch: inset from the projector's top | in_top | 15 | mm | 15 |  |  | 2 |  | Photo-derived (2026-10-06 owner photos); confirm with calipers. Sets the inlet bank's height on the right wall.
Projector | Exhaust grille start, behind the front face (right face) | exh_y[0] | 0 | mm | 0 |  |  | 3 |  | Photo-derived (2026-10-06 owner photos); confirm with calipers. Slots measured 10-42 mm; the owner says the first 40. Sets the exhaust bank's position.
Projector | Exhaust grille end, behind the front face (right face) | exh_y[1] | 42 | mm | 42 |  |  | 3 |  | Sets the exhaust opening length (with air_margin each end). The grille spans the full projector height.
Projector | Foot height on the underside |  |  | mm |  |  |  | 0.5 |  | If the feet, not the body, rest on the ball head's platform, add this to ball_head_h.
Projector | Flat area around the 1/4-20 socket, diameter |  |  | mm |  |  |  | 2 |  | Must take the ball head's platform (Ball head rows). Feet or ribs inside this circle rock the mount.
Projector | Weight |  | 720 | g | 454 |  |  | 100 |  | Manual: 1 lb (its spec table says 25 lb, a typo). Kitchen scale.
Projector | Aspect ratio (width / height) | aspect | 1.778 |  | 1.778 |  |  | 0.01 |  | Manual: native 1280 x 720, so 16:9.
Projector | Throw distance to wall (helper) |  |  | mm |  |  |  |  |  | Lens face to wall, projector level.
Projector | Image width at that distance (helper) |  |  | mm
Projector | Throw ratio | throw_ratio | 0.95 |  | 0.95 |  |  | 0.1 |  | Spec is derived from the manual's image sizes (36 in at 2.5 ft, 72 in at 5 ft, 150 in at 10 ft: 0.92 to 0.96; 250 in at 16 ft gives 0.88). Measured is computed from the two helper rows above. Do not type here.
Projector | Image height at that distance (helper) |  |  | mm
Projector | Image bottom edge above lens axis (helper, negative if below) |  |  | mm |  |  |  |  |  | Lens axis = lens centre height on the wall, projector level.
Projector | Lens offset (0 = centred on axis, 1 = bottom on axis) | lens_offset | 0 |  |  |  |  | 0.1 |  | Computed: 2 x bottom / height + 1. Do not type here.
Projector | Power draw |  |  | W | 50 |  |  |  |  | Manual: 50 W. Compare with the brick's rating (120 W) and the Y-splitter's lead rating.
Ball head | Height, base to top of stud, head level | ball_head_h | 40 | mm |  |  |  | 2
Ball head | Ball centre above base | pivot_h | 25 | mm |  |  |  | 2 |  | The aim pivot.
Ball head | Base diameter |  |  | mm |  |  |  |  |  | Must sit on the 40 mm pedestal top.
Ball head | Lock knob height above base |  |  | mm |  |  |  |  |  | Hatch centre is hatch_zc (56) above the floor; pedestal top is 30, so the ball sits about 55. Knob must land in the diamond (108 mm tip to tip).
Ball head | Stud thread length |  |  | mm |  |  |  | 0.5 |  | Compare with the socket recess depth. Too long bottoms out before it clamps; too short strips the socket.
Ball head | Platform diameter under the stud |  |  | mm |  |  |  | 1 |  | Has to sit inside the projector's flat area.
Ball head | Base thread diameter (1/4-20 = 6.35, 3/8-16 = 9.5) |  |  | mm |  |  |  | 0.3 |  | The pedestal column takes a 1/4-20 insert (insert_d). A 3/8-16 base needs a reducer bushing.
Ball head | Lock knob diameter |  |  | mm |  |  |  | 2 |  | Knob plus the fingers that turn it must fit the 108 mm diamond.
Ball head | Lock knob reach from the ball centre, horizontal |  |  | mm |  |  |  | 2 |  | Ball centre to knob tip. The ball sits about 55 above the floor and roughly centred in X, so this says where the knob lands in the hatch.
Ball head | Tilt before the projector body hits the head | aim_max | 15 | deg |  |  |  | 1 |  | Projector mounted, tilt until it touches.
Power brick | Brick length (X on the shelf) | brick[0] | 150 | mm |  |  |  | 2 |  | PROVISIONAL (typical 120 W desktop brick). Measure the Parts Express brick with calipers on arrival.
Power brick | Brick width (Y on the shelf) | brick[1] | 60 | mm |  |  |  | 2 |  | PROVISIONAL (typical 120 W desktop brick). Measure the Parts Express brick with calipers on arrival.
Power brick | Brick height (Z) | brick[2] | 38 | mm |  |  |  | 2 |  | PROVISIONAL (typical 120 W desktop brick). Measure the Parts Express brick with calipers on arrival.
DC brick | Output voltage |  | 21 | V |  |  |  | 0.5 |  | Brick: 24 V (Parts Express). Projector label 21 V: BRINGUP row 4a
DC brick | Output current |  |  | A |  |  |  |  |  | Brick: 5 A (120 W). Read the label
DC brick | Input current |  |  | A |  |  |  |  |  | Read the brick's label (no AC fuse is fitted)
DC brick | AC cord outer diameter | cord_d |  | mm |  |  |  |  |  | Outer diameter of the brick's standard molded AC cord, where it passes the rear-wall opening and the cord clamp. Sets `cord_d` (PROVISIONAL 9). The connector's face size sets `cord_open`.
DC brick | DC cable length, brick to barrel plug |  |  | mm |  |  |  | 50 |  | Brick's DC cord to the Y-splitter, then the splitter's legs to the projector's rear jack (at 15 deg up-tilt) and to the DigiAMP+. Spare goes in a loop on the low-voltage side, not coiled by the brick. A relay, if built, is spliced in leg 1.
DC brick | AC cord length, brick to rear-wall opening |  |  | mm |  |  |  | 50 |  | From the brick's inlet to the opening in the rear wall (`cord_open`) and its clamp. Needs slack inside for the connector and a drip loop outside below the clamp.
DC brick | RETIRED: no fuses fitted |  |  | mm |  |  |  |  |  | No fuses in the single-brick design (the brick is current-limited and short-circuit protected). Row kept so formulas stay aligned; leave blank.
DC brick | Relay module footprint, L x W x H |  |  | mm |  |  |  |  |  | Low-voltage side of the shelf, between the zip-tie slots (tie_gap 34 mm apart). Only for the relay fallback.
DC brick | Splice / terminal block footprint, L x W x H |  |  | mm |  |  |  |  |  | Y-splitter body (5.5 x 2.5 mm, 1 female to 2 male) and any relay splice. Sits on the low-voltage side; feeds the projector adapter and the DigiAMP+.
Pi stack | Pi 3/4: board bottom to top of DigiAMP+ | pi_stack_h | 40 | mm |  |  |  | 2 |  | Only the sled you will use.
Pi stack | Pi 5 + Active Cooler: board bottom to top of DigiAMP+ | pi5_stack_h | 50 | mm |  |  |  | 2
Pi stack | Zero 2 W: board bottom to top of DigiAMP+ | zero_stack_h | 30 | mm |  |  |  | 2
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

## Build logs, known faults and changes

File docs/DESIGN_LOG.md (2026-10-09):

# Design log

Chronological record of decisions, including dead ends, so the reasoning survives a change of tools.

## Requirements (from the owner)

- Waterproof case for a small projector and a Raspberry Pi 3 that controls an AtmosFX pumpkin effect
- Sits on the ground; projector on an internal ball joint for easy aiming
- Aiming should be as quick as possible (it is the primary setup task)
- A single power cord for the box; the projector uses a DC brick that can be modified to feed both projector and Pi; the brick goes inside the case

## Versions

| Ver | What changed | Why |
|---|---|---|
| v0.1 | First parametric box: base, sloped lid with visor, acrylic window, louvers, fan, Pi compartment, 1/4-20 plate | Assumed a projector twice a DSLR wide (260 mm) |
| v0.2 | Ground-standing on feet; tripod insert and plate replaced by a ball-head pedestal | Owner: case sits on ground, projector on a ball joint |
| v0.3 | Resized to a real mini projector (about 171 x 134 x 75 mm, 0.72 kg); split front/rear instead of quarters | Listing dimensions; smaller box fits the MK3S bed in two pieces |
| v0.4 | Tool-free aim hatch on the left wall, keyhole cover, rain hood; intake moved from wall louvers to floor slots | Aiming must be quick; the wall space was needed for the hatch |
| v0.5 | One AC cord, power shelf on 45 deg ledges above the Pi | Owner: single power cord |
| v0.6 | Low-voltage DC variant: brick outside, buck converter for the Pi, zip-tie shelf | Owner: projector has a DC brick that can feed both |
| v0.7 | Brick inside on the shelf: cradle, barrier, cord notch, heat louvers above the shelf | Owner: brick should be inside |
| v0.8 | Gland above the shelf; barrier 40 mm; keyholes flipped; hatch 8 mm lower and hood raised for the lift; lid scarf joint, seam rib, gasket land; front/rear gaps 30/26 | Review: mains ran through the Pi zone, cover would fall off, lid seam leaks onto the projector, aim range did not fit |
| v0.9 (unreleased) | Sized to the Tkisko TO2 (165 x 130 x 66, lens on the long face offset left, 0.95 throw, socket right of centre); front/rear gaps 30/34; hatch 108 mm centred 56 up; lid seam at 200 (`lid_front_len`); front tiles print end-on; `pan_max` 10 and `aim_combo` 8 split from `aim_max`; front lid screw moved behind the window frame; stock supply is a wall-wart, so the shelf's cradle became a receptacle plate (two NEMA 5-15R stacked, second wall-wart for the Pi/Amp4/fans rail), gland moved beside the plate, Pi zone 85; tripod inserts and pad removed again | Manual, product photos and a caliper measurement: the wider body missed the bed the old way round, the short throw clips the window at 15 deg pan, the shorter body dropped the lid skirt onto the hatch hood |
| v0.10 (unreleased) | Passive airflow: both 40 mm fans, the DS18B20s, the floor intake and the shelf vent slots removed; exhaust bank (front) and inlet bank (rear) on the right wall with a lip baffle between them, one passive Pi-zone louver; DC-jack and right-face HDMI keep-outs, IR holder on the front face; Pi software keeps only an SoC over-temperature guard; second rail 12-24 V; single supply: one 24 V desktop brick, a molded AC cord and a clamp (no hand-wired AC), a Y-splitter, relay and IR as CEC fallbacks | The projector has its own fan; fewer parts and no sensors or 24 V coupling; photos of the real ports |

## Decisions and dead ends

- **Sealed vs rain-proof.** Sealing overheats projectors. AtmosFX says any enclosure must allow air circulation; a forum builder who put a projector in a louvered plastic tub felt it would just melt it. So: rain-shedding louvers, floor intake, exhaust fan (superseded 2026-10-06: passive airflow, right-wall banks, no fans or floor intake).
- **Mini ball head, not a printed ball joint.** Commercial heads are cheap and lock reliably; printed friction joints creep. Rating matters: the Tilta mini head is rated 1.5 kg, the projector is about 0.72 kg. A heavy-duty head (Kessler low-profile, about 3.5 in tall) would push the base past the 210 mm Z limit and force a horizontal split.
- **UTEBIT 20 mm head chosen (2026-10-06).** Vendor drawing: 58 mm overall including the stud, 30 mm body, 20 mm ball, 32 mm base, Amazon rating 2.5 lb / 1.1 kg (other listings say 2.5 kg; the projector is about 0.72 kg, so the margin is about 1.6x on the conservative figure). Set `ball_head_h` 52 (platform the projector sits on; the stud screws into its socket) and `pivot_h` 32 (ball centre), both scaled off the drawing; the old 40 / 25 were guesses. Build and `check_clash.sh` stayed green. Sources: [Amazon listing](https://www.amazon.com/dp/B06XKW7V14).
- **Hot-shoe receiver, coupon only (2026-10-06).** The UTEBIT head ships with a 1/4" hot-shoe adapter; a printed ISO 518 T-slot (`hot_shoe_cut()`, `shoe_*`) in the pedestal would replace the double-ended stud and the 1/4-20 insert. Spike: no clash with a modelled adapter, prints without supports (about 3 mm lips). Open: adapter foot size, lip creep, nothing but the ring's clamp stops it sliding out, and the ring adds about 5 mm of height (lower `ped_top` to compensate). Not in the pedestal until the coupon fits. ISO numbers: [Wikipedia: Hot shoe](https://en.wikipedia.org/wiki/Hot_shoe).
- **Tripod insert removed** in v0.2 when the case became ground-standing.
- **Quarters to halves.** With a 260 mm projector the box needed four tiles. With the real projector, front/rear halves are enough. The divider sits at the seam.
- **Aim hatch.** Options weighed: tool-free lid latches (still lift the whole lid), a side hatch with screws, a keyhole cover. Keyholes won: nothing to unscrew, cover hangs on four M4 bolts, lift up and off. Hood is a 45 deg wedge (no supports). It first collided with the cover top and then with the lid skirt; shrunk to 10 mm and lifted; verified clear.
- **Floor intake.** Wall louvers moved out of the way of the hatch; intake now comes through slots in the raised floor. Risk: ground splash. Keep off wet ground.
- **Power.** Mains inside is the least safe option but the owner asked for it. Mitigations: barrier wall, GFCI, fuse, cord grip, PETG/ASA. If the owner changes their mind, v0.6 (brick outside) is the safer variant: revert `power_shelf` and `gland_d`.
- **Stock supply measured (2026-10-05).** It is a wall-wart, not a corded brick: MX48CC-210228US, AC 100-240 V 1.0 A in, 21 V 2.28 A (48 W) out, centre-positive, fixed 2-pin prongs, captive DC cord, 85.6 mm long (caliper), about 47 wide (photo), height unmeasured. `brick_l/w` now 86/47. The gland-to-IEC-to-brick chain assumed an AC inlet, so it cannot be used as drawn. Options were the v0.6 layout (wall-wart outside in the connection box, only DC through the gland) or a receptacle inside. Owner chose inside, with a second wall-wart for the Pi, Amp4 and fans, and allowed a clip-on box or a size change. First layout: one receptacle plate near the rear wall and one near the divider, warts hanging toward each other. A panel-mount receptacle plus its spades and the cord needs about 30 mm behind the plate, so that layout needed a 143 mm Pi zone and the rear lid tile (seam to skirt) went past the 210 mm bed axis. Final layout: one plate 30 mm off the rear wall with both receptacles stacked, the warts standing on their long edges (47 tall each, the second on top of the first); the roof over the Pi zone is at 175 so the stack (171) has about 3 mm, asserted against `wart_w`, which is a photo estimate. The gland moved from above the brick to the rear-left corner beside the plate (`cord_x` -94, 20 above the shelf), with an assert that its locknut fits between the wall and the plate. The Pi zone grew 10 mm (85) for wiring room; the low-voltage side of the shelf is 83 mm wide. Receptacle: SS-6B snap-in (swapped from the Qualtek 738W-X2/01 on 2026-10-06), 24 x 24 cutout, 1.5 mm panel gap, so the plate is pocketed to 1.5 mm round each cutout from the terminal side; `rcpt_back` went 30 to 40 (the shelf-depth limit) for its deeper body. `warts` is a clash keep-out (case, lid, shelf, fans). The second wall-wart's size is a placeholder equal to the stock one.
- **Review fixes (v0.8).** The keyholes had the big end above the bolt, so gravity would have released the cover; now the narrow end is up and the hood sits `kh_drop` higher so the cover can lift. The AC cord entered below the shelf and ran past the Pi; the barrier only existed above the shelf, so the gland moved up to the AC side. The barrier (25 mm) was shorter than the brick (32 mm). The lid seam lands over the projector and cannot move behind the divider (the front lid tile would be about 258 mm), so it became a 45 deg scarf with a rib under the roof; a horizontal shiplap would have needed supports on the rear tile. The sloped roof only met the gasket at the rear edge, so the lid gained a flat land. Owner chose fuses on both AC and DC.
- **Aim range.** The new aim sweep in `check_clash.sh` showed the claimed +/-15 deg never fit: the ball pivot is about 90 mm below the top corners, so tilt swings them about 20 mm into the window frame or the divider. Gaps grew to 30/26 mm (base_front 241 mm). 15 deg pan and tilt together would need about 254 mm, so combined aim is limited to 10 deg. Setting the case roughly on target covers the rest.
- **Stock pane.** The pane was 96 x 76 mm, not a stock size. It is now a parameter set to 3 x 5 in (127 x 76.2 mm, 1/8 in thick) and the window is derived from it, 111 x 60 mm, which also gives the light cone more room when panned. 4 x 4 in would push the frame above the base rim; 4 x 6 in is wider than the space between the front lid posts.
- **Frame glazing, 3.5 x 5 in, 2 mm (2026-10-06).** Goal: owners can buy the pane off the shelf, with the smallest opening. Picture-frame glazing is about 2 mm, so `pane_t` went 3.2 -> 2 (rebate, 45 deg ceiling, `fw` and snap-out ribs derive from it). Tested with `check_clash.sh`: 5 x 3.5 in passes (window 111 x 72.9 mm); 5 x 3 in and 4 x 3.5 / 4 x 4 in fail the light cone (the 4 in widths also the aim sweep); 6 x 4 in clashes the frame with the base. So 3.5 x 5 in is the smallest common size; `pane_h` 101.6 -> 88.9. 2 mm glazing flexes more, and frame glass can be slightly under nominal (the rebate has 0.3 mm clearance and the lap is 8 mm): check on the fit coupon. Use acrylic, not glass, outdoors. The 3.5 x 5 in window only just cleared +/-12 deg of tilt (CI's older OpenSCAD found a 2.4 mm3 sliver the local build missed, and the limit is not monotonic: 12.5 deg clashed 11 mm3), so `cone_tilt` went 12 -> 11 deg for margin: upward tilt is limited to about 11 deg.
- **Audio.** Owner wants an amp inside and speakers behind the projection on standard speaker wire. HiFiBerry Amp4 HAT: I2S DAC plus stereo class D amp on one board, runs from the 12-24 V splice and powers the Pi, so the buck converter goes. The Pi 3's analog jack is too noisy to feed an amp. Speaker zip cord is flat and won't seal in a PG gland, so it goes down a 15 mm floor chimney and out under the case. The shelf rose 5 mm to clear the HAT; the louvers and AC gland above it moved with it.
- **Amplifier swap (2026-10-05).** HiFiBerry Amp4 replaced by the Raspberry Pi DigiAMP+: same TAS5756M, 2 x 35 W, 12-24 V in, powers the Pi (5.1 V / 2.5 A), about half the price and stocked at Micro Center, which took the one long-lead part off the ordering plan. Costs: GPIO 22 is the DigiAMP+ mute line (owned by the `rpi-digiampplus,unmute_amp` overlay), so the IR LED moved to GPIO 16; the ALSA card is `RPiDigiAMP`; its optional encoder/IR headers expose GPIO 17, 23-25 and 27, which VideoFX uses, so those headers stay empty. Its pass-through header makes the stacking header Zero-2-W-only. Pi 5 caveat is the same as before (2.5 A over the header, Raspberry Pi only promises the Pi 3). The product brief (RP-008138-DS-1) gives 58 x 65 mm with 4x M2.5 corner holes, the barrel jack and both speaker terminals on one 65 mm edge (13.8, 30.2 and 49.5 mm from the corner), 0-50 °C operating, and no height, so `pi_stack_h` stays a measurement to make.
- **Pi sleds.** Owner wants multiple Pi generations. The Pi 3B/3B+, 4B and 5 share the 85 x 56 board and 58 x 49 hole pattern, so the sled is mainly a fixed interface plus easy removal. The Zero 2 W (58 x 23) is the real outlier. Lift-out from the top was chosen over a rear slide-out door: no new wall opening to keep dry. Sleds carry only the Pi and HAT; power and speaker wires unplug. Aligning every board's GPIO edge keeps the Amp4 in one place; the Zero sled supports the overhanging half of the HAT. The Pi 5 with Active Cooler needs a taller stack, so the shelf rose to 60 mm and the AC gland and pass-through now follow the shelf.
- **Startle scares.** Customer research: AtmosFX sells a motion-sensor player for buffer-plus-scare clips, and people build the same on Pis. The PIR goes in the rear wall because the case faces the projection surface, so visitors approach from behind it. A PIR can't see through the acrylic window (it blocks IR), so the dome sits in its own hole under a hood. Home automations can trigger scares too, so a remote or existing sensor works without the built-in one. Multi-projector sync was left for later.
- **Printability pass.** The base prints upright, and the floor was floating 6 mm up on two ribs and corner pads, a 148 mm bridge across the whole floor; it now stands on eight front-to-back ribs. The hatch became a 45 deg diamond (still 120 mm wide at the ball head). The window can't take a pointed top because the pane has to cover it, so two 0.8 mm snap-out ribs split its 111 mm bridge into thirds. The divider pass-through got a gabled top.
- **Projector power.** Owner chose HDMI-CEC, plus a fallback for projectors without it: a relay on the DC + line and an IR LED sending the remote's power code after the relay closes.
- **Heat** (superseded 2026-10-06 by "Passive airflow" below). The Pi zone held the brick, the amp and possibly a Pi 5 with only passive vents, and the original fan's power and control were never specified. Now both zones have 12 V PWM fans driven by the Pi from temperature sensors, the shelf has vents on its low-voltage side so heat from below reaches the Pi-zone fan, and the upper right-wall louvers gave way to that fan. The fan bodies are now in the aim sweep. A top-level variable used before its definition (`pi_fan_z` before `shelf_zz`) came back as undef; the new clash check caught it.
- **Insect screen** (superseded 2026-10-06: three wall caps now, no floor intake, no fans). A warm vented box outdoors invites wasps and spiders. Printed mesh is too coarse, so real screen is glued into printed caps over each louver bank and the floor intake, and clamped behind the fans. The first cap layout put a screw tab behind the rear lid post where no driver could reach; the tabs moved to top and bottom.
- **Tripod, second time.** The v0.8 review re-added 3/8-16 and 1/4-20 inserts under the floor so the whole case could go on a tripod. Removed again (2026-10-05): the owner wants the case flush to the ground for this use, and the projector already has its own aiming mount inside. That drops the centre-of-mass estimate, the 3/8 insert (a slow-to-source size), its boss and the pad under the floor; coarse aim is now turning the case and shimming the feet, fine aim is the ball head. The pull-out concern from the fourth review goes with it.
- **Dew.** Considered a pane heater switched on dew point; owner decided against it. The visor and fan airflow are the only defence against condensation on the window (superseded 2026-10-06: the fans are gone, so the visor and the projector's own airflow are the defence).
- **Keyhole leak, resolved by the diamond hatch.** With the square opening, the wide ends of the upper keyholes sat over the opening. The studs are at the square's corners (+/-56, +/-56), so the nearest wide end is about 98 mm (|y|+|z|) from the centre, far outside the diamond's 60 mm edge: every keyhole now sits over solid wall.
- **Base seam.** The lid's scarf doesn't transfer: the base prints upright, so a 45 deg scarf through 183 mm of height would shift 183 mm in Y, and any lap crossing the seam runs into the divider, which sits right at it. Instead the rear tile has 6 mm collars inside its side walls, and four M3 screws from the projector side pull it against the divider, which also aligns the halves. The collars stop below the shelf ledges and stay clear of the sled.
- **Lid screws.** The roof counterbores collected rain. A raised cone around each screw can't be printed, because the lid prints roof-down, so the screws moved to the skirt sides: horizontal M3s into blocks in the base wall tops, replacing the four full-height posts (which also frees the interior and the shelf corners). Slotted holes allow pressing onto the gasket; spacer rings keep the skirt from flexing across the lid_clr gap.
- **Anchoring.** Stake and lock tabs outside the walls would push the front tile past the bed's 210 mm axis (it's already 201 mm with the hatch hood). Instead, four sealed stake tubes stand inside the corners, like the speaker chimney. Stakes go in from inside, and with the lid on security screws they can't be pulled. That deters theft and resists wind without any change to the footprint.
- **Licensing.** Design and docs stay CC BY-SA 4.0; the Pi software is MIT, which suits code better and is compatible with matter.js (Apache-2.0).
- **CI.** The workflow now also runs check_clash.sh and the Pi tests. It uses Ubuntu's apt OpenSCAD (older CGAL build); the volume-based check doesn't depend on the backend's output format.
- **Light cone.** The body sweep never checked the light itself. Modelling the image pyramid for a 1.4:1 16:9 projector showed the 60 mm-tall window clipped past +8 deg of tilt, and only +4 deg with an upward-offset lens: bad, since tilting up is the main use. Fixes, each measured: a 4 x 5 in pane placed as high as the base rim allows (frame screws moved to its sides so the frame hugs the pane), the lid's front skirt notched over the window (its bottom edge sat 2 mm into the window), and a 30 mm visor with a 4 mm drip lip (the 12 mm lip was the next obstruction). Result: +/-12 deg tilt with a centred lens (check: `light-cone`), +10/-18 deg with a fully offset one.
- **Plugs behind the projector.** The 26 mm rear gap had no room for plugs. A keep-out for right-angle plugs (15 mm) in the aim sweep needed a 32 mm rear gap; the front gap came down from 30 to 26 mm without clipping anything (the lens now sits nearer the window), so `base_front` is 243 mm, 7 mm under the bed.
- **Slicing.** PrusaSlicer's CLI with the bundled MK3S profiles gives about 82 h and 1.25 kg in total, 37 h of it `base_front` (27 h at 0.30 DRAFT). A fit coupon (1.5 h) comes first. STLs moved from git to Release assets because every rebuild added megabytes of history.
- **Third review.** One version for the repo (the Pi package said 0.1.0 under tag v0.8.0, which would confuse `videofx-update`). The tripod insert moved from y 12 to 5 after computing the centre of mass from part centroids and slicer weights (about 2.6 kg in all). Added an optional hatch lock screw into the solid wall/floor corner, V-0 filament for the power shelf, cord routing for trick-or-treaters, an ordering plan with rough costs, and a bring-up checklist. Colima (open-source Docker) runs the pi-gen image build on the Mac.
- **Clash script.** The OpenSCAD snapshot uses the manifold backend, which never prints "Volumes: 1", so zero-volume contact (the shelf on its ledges) read as a clash. The script now measures intersection volume. It also used to report CLASH when OpenSCAD failed to run.
- **Fourth review: things the clash script couldn't see.** It only checks what is modelled, and no cable was. (1) The Pi's HDMI edge sits 9.5 mm behind the divider and the pass-through started 22 mm above the board, so no plug could go in; the pass-through now opens down to the sled and spans every board's port (`pass_x`), a straight plug goes through it and the cable loops under the projector, and `pi_hdmi_plug` is a keep-out in `check_clash.sh` (`hdmi-*`). The Zero 2 W is not in that check: its HAT support post stands 9 mm from the port centre, so it needs a slim plug. (2) The outer foot ribs stopped 5.5 mm short of the side walls, leaving a strip of floor the full length of the case printing in mid-air; the outer ribs now sit under the walls whatever the width (`ribs_x`), with the longest bridge asserted. (3) The pane rebate's flat ceiling was an unsupported edge 128 mm wide that could sag into the pane clearance; it is now 45 deg (the frame covers it, silicone fills it). (4) The gland entered 15 mm above the shelf, pointing at the side of the brick 16 mm away; it is now above the brick (`cord_dz` 46, asserted against `brick_h` and the lid skirt). (5) Nothing checked bed fit: `base_front` is 243 of 250 mm, so a projector 7 mm deeper than the guess would have broken the split silently. Each tile is now asserted against `bed`. Still open, waiting on the brick's measurements: the shelf's AC side has no room for the IEC plug (the brick's ends are 5 and 3 mm from the wall and barrier) or the inline fuse holder. Left alone at the time: the tripod inserts went in from below, so the screw pulled them out of the plastic rather than into it (moot now that they are gone).
- **Fourth review: the Pi software.** Read against upstream sources, with nothing run on a Pi. First boot would have stopped at the partition step (`parted -s resizepart` on the mounted root asks a question and script mode takes that as failure; confirmed in a trixie container, replaced with `sfdisk`). The over-temperature path had several ways not to fire: no trip without a projector-zone reading (and the sensor ID defaults to empty), a failed state save aborting power-off before the projector was touched, the relay left closed when the service stopped or crashed, and fans not driven at all with Cooling off. All four are fixed, and a lost sensor now trips after 60 s. Still true: only the relay modes cut power; CEC can only ask. Also fixed: the IR power toggle sent again on a second "on" (which would switch a `relay-ir` projector off at sunset if it was already on), no picture when the projector connects after mpv starts (playback now waits for the HDMI sink and restarts when it appears), the web page refusing on-link IPv6 clients, an mpv option deny-list that let the page write any file (now an allow-list, plus `ProtectHome`), unlimited password guesses, the schedule not catching up after a power cut, mpv never restarted after giving up, and `READY=1` tied to Matter being online. Left for hardware: fan PWM on a Pi 5, whether the fbdev blank works once mpv is idle, CEC details.
- **Projector EDID (October 2026).** First hardware fact. The projector plugged into a MacBook reports a generic STK "S2-TEK TV" EDID: 1080p60 native, 8-bit, 150 MHz TMDS ceiling, 2-channel LPCM, DPMS standby flags, and an HDMI vendor block with CEC physical address 2.0.0.0. So the input is real HDMI and the `hdmi-off` fallback has something to work with, but CEC itself is still unproven (the address is mandatory for any HDMI sink; a Mac cannot speak CEC). The Pi should output 1080p60. Nothing about the case geometry changed: the EDID says nothing about size, lens or port positions.
- **Bugs hit:** shell `brace expansion` failing under sh (use bash), top-level variable used before definition (`lid_seam`/`yfl`), phony `make stl` clashing with the `stl/` directory (target is `parts`), tiny preview renders from `--viewall`, the lid scarf's cutting polygon crossing itself once the seam constant went negative (a deeper Pi zone did it; the manifold backend shrugged, CI's CGAL backend refused the mesh, so it is a plain trapezoid now).

- **Tkisko TO2 fit (v0.9).** The owner's projector is 165 wide with the lens on the long face, not 135 wide on the short face. With the 25 mm side gaps the base is 221 wide (231 with the hatch hood), past the 210 mm bed axis the old way round. Shrinking the side gap failed: the projector-zone fan body stands 14 mm proud of the right wall inside that gap, so even zero pan needs 15 mm, and the hatch hood takes another 10. The body is also 42 mm shorter, which brings the front base tile under 210 mm, so the front tiles now print end-on (X along the 250 mm axis) and the lid seam moved from 230 to 200 mm from the visor tip so `lid_front` fits the same way. The short throw (0.95 from the manual's image sizes) widens the light cone: it clips the window frame past 10 deg pan, so pan got its own limit (`pan_max`), with tilt still 15 and the combined corner 8 (the rear plugs reach the divider past that now the pivot sits 19 mm right of centre). Losing 10 mm of body height dropped the lid skirt onto the hatch hood; the diamond cannot go lower (its tip is 2 mm above the floor), so it shrank from 120 to 108 mm. The off-centre window frame overlapped the front lid-screw block by 0.35 mm, so that station moved 2 mm back. The label reads DC 21 V 3 A: the Amp4 is fine on 21 V, the fans must be 24 V parts, and the stock brick has no headroom for the Pi and amp.
- **Passive airflow (2026-10-06).** The two 40 mm PWM fans and the two DS18B20s are gone. The projector already has a fan; the case only has to give it a clean path in and out. That removes the 24 V coupling (the second wall-wart is now 12-24 V, sized for the DigiAMP+), the sensors, the fan fuse and branch, the PWM and 1-wire pins, and the 14 mm fan body in the right side gap (`side_air` could now shrink to about 19 mm; left alone, since it would move the base off the bed's 210 mm axis and is a separate change). Path: outside, the right-wall inlet bank (rear gap as plenum, centred on the projector's intake height), the projector's intake and fan, its right-face exhaust, the right-wall exhaust bank (front), outside. A vertical lip baffle between the banks stops exhaust creeping back along the side gap; it is a lip, not a seal, and its depth is limited by the aim sweep. Ports now come from the owner's photos: DC jack in the rear top-right corner (plug points back, above the intake patch), an I/O strip on the right face (top 18 mm, 41-118 mm behind the front, HDMI at 56 mm; right-angle HDMI only, cable runs back above the baffle), the IR receiver on the front face above the logo (near X +35, Z 50; `ir_holder` fits in the front gap), and the rear face's second grille is a speaker, not an air path. The Pi zone gets one passive screened louver high on the right wall; the effect only runs at night, so there is no solar load. The Pi software keeps only an SoC over-temperature guard (switch the projector off at the critical temperature, default 80 C). Open risks: the side-panel position is photo-derived (a few mm), the louver openings are owner-measured, recirculation between exhaust and intake 90 mm apart is untested, and the Pi zone's heat behind one louver is untested (bring-up logs it). Two things the checks cannot see: the right-angle HDMI cable's route from the right-face strip, over the baffle, across the rear gap to the divider pass-through at full tilt and pan is not modelled (the side-port keep-out ends at the projector's rear plane; bring-up row 21), and `ir_holder_h` is 7 mm to clear the window frame, which leaves a shallow LED seat (glue it if loose; bring-up row 22). Built values differ slightly from the plan: two small `cap_t` offsets keep the inlet cap off the divider and the baffle off the exhaust cap.
- **No DC fuses (2026-10-06).** Dropped the two blade fuses on the DC rails. Each wall-wart is current-limited and short-circuit protected, and its rated output is far below what the 18 AWG leads carry, so a downstream fault cannot overheat the wire. The AC live fuse stays (the GFCI does not limit overcurrent inside a printed box). The second wall-wart must be UL/ETL listed. (Superseded in part by the Single supply entry below: there is no AC fuse in the single-brick design.)

- **Single supply: one brick, a plain cord, a clamp (2026-10-06, accepted 2026-10-08).** The second rail existed only because the DigiAMP+'s 12-24 V range was never compared with the projector's 21 V. The manual's 50 W against the stock supply's 48 W also made relying on one stock supply a gamble. The owner then chose a single 120 W 24 V 5 A desktop brick and a plain detachable AC cord over a receptacle and hand wiring: a Y-splitter feeds the projector and the DigiAMP+, the receptacle plate, second wall-wart, barrier, quick-connects, AC fuse and gland go, and the rear wall gets a rectangular opening closed by the two-piece `cord_clamp`. The relay and IR LED are built only if CEC fails. Safety changes the owner accepted (2026-10-08): no AC fuse, a strain-relief clamp instead of a mains-rated cord grip, no barrier, and a cord that is not outdoor-rated, for the Halloween 2026 run (about a month outside) and replaced if damaged. What stays: GFCI-fed outlet, drip loop, plug joints in a weatherproof box and off the ground, PETG/ASA only, V-0 PETG for the shelf. Risks: 24 V into a projector labelled 21 V (BRINGUP row 4a; a buck converter on that leg if it fails), the brick's size on the shelf (unknown until it arrives), the clamp holding a firm pull (unproven until row 17a; its grip comes from geometry, not tightening), and the Y-splitter's leads, which must be rated for the supply's 5 A or fused to the lead. See `docs/superpowers/specs/2026-10-06-single-supply-power-design.md`.

## References

- AtmosFX, DIY outdoor projector enclosures: https://atmosfx.com/blogs/community/digital-decorating-101-outdoor-decorating-part-3-diy-outdoor-enclosures
- AtmosFX Illumibot large enclosure (size/fan reference): https://atmosfx.com/products/illumibot-large-projector-enclosure
- ControlBooth thread on weatherproofing a projector: https://www.controlbooth.com/threads/weatherproof-a-projector.26853/latest
- Smart Home Hookup, outdoor projector + Pi install: https://www.thesmarthomehookup.com/test_install/?p=1849
- Tilta mini ball head (1.5 kg rating): https://tilta.com/shop/tilta-mini-ball-head-mount/
- Nanlite mini ball head (male 1/4-20 top, 66 x 35.5 x 25.4 mm): https://www.adorama.com/nanlite-mini-ball-head-hot-shoe-adapter-1-4-20-mount/p/nnasbh14
- Kessler low-profile ball head (40 lb, about 3.5 in): https://kesslercrane.com/products/low-profile-ball-head-1-4-20-mg1007
- Typical dimensions for this projector class (6.74 x 5.28 x 2.96 in, 0.72 kg), Amazon listing for a similar unit: https://www.amazon.com/Projector-CLOKOWE-Upgraded-Portable-Compatible/dp/B09Q5GJ7J7 (a different brand of the same class is not guaranteed to match; measure the real unit)
- OpenSCAD Playground (browser preview, works on iOS): https://github.com/openscad/openscad-playground

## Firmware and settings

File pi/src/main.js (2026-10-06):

// VideoFX player: a Matter device that loops a playlist (or runs startle scares)
// full screen with mpv, switches the projector with it, and serves a LAN web UI.
//
// Matter endpoints: 1 "projector" (main on/off), 2 "scare" (on = fire a scare,
// goes back off when it ends), 3 "motion" (PIR occupancy sensor),
// 4 "temperature" (the Pi's SoC).
//
// Who controls the main power: Matter, the web page, the schedule and restore go
// through the PowerArbiter; while DMX (sACN) is live only DMX may; thermal
// protection can always switch off and blocks switching on while tripped.

import { execFile, spawn } from "node:child_process";
import dgram from "node:dgram";
import { existsSync, mkdirSync, readFileSync, statSync } from "node:fs";
import { readFile, writeFile } from "node:fs/promises";
import { hostname } from "node:os";
import { fileURLToPath } from "node:url";
import { monitorEventLoopDelay } from "node:perf_hooks";
import { join } from "node:path";
import { promisify } from "node:util";
import { DeviceTypeId, Environment, ServerNode, VendorId } from "@matter/main";
import { OccupancySensingServer } from "@matter/main/behaviors";
import { OccupancySensorDevice, OnOffPlugInUnitDevice, TemperatureSensorDevice } from "@matter/main/devices";
import { QrCode } from "@matter/main/types";
import { applyStagedRestore, createBackup, stageRestore, validateBackup } from "./backup.js";
import { defaultContext, resolveSettings } from "./config.js";
import { DisplayWatch, displayConnected } from "./display.js";
import { DmxControl, InternalWrites, PowerArbiter, SACN_PORT, SacnReceiver, fixtureValues, interpret, multicastGroup } from "./dmx.js";
import { writeFileAtomicSync } from "./fsutil.js";
import { GpioOut, gpiosetArgs } from "./gpio.js";
import { Ir, lircFeatures } from "./ir.js";
import { HttpError, createMediaStore } from "./media.js";
import { parsePlaylist } from "./playlist-core.js";
import { MpvSupervisor, mpvArgs } from "./mpv.js";
import { Pir, gpiomonMajor, pirArgs } from "./pir.js";
import { Player } from "./player.js";
import { Projector } from "./projector.js";
import { qrTextToSvg } from "./qr.js";
import { Scheduler, missedEvent } from "./schedule.js";
import { createScreen } from "./screen.js";
import { Settings } from "./settings.js";
import { TIMESYNC_FLAG, parseIwLink, parseNmcliDevices, signalVerdict, storageStatus } from "./system.js";
import { Watchdog } from "./watchdog.js";
import { capVolume, quietNow, scareBlocked } from "./quiet.js";
import { readVersion, updateStatus } from "./update.js";
import { OverTempGuard, SocWatch, parseMilli } from "./thermal.js";
import { Volume, amixerArgs } from "./volume.js";
import { createWebServer } from "./web.js";

const run = promisify(execFile);
// No RTC on the Pi 3/4/Zero 2 W: time-based rules wait for NTP (see schedule.js, quiet.js).
const clockSynced = () => existsSync(TIMESYNC_FLAG);
const ctx = defaultContext();
// The state folder holds settings.json, so it comes from the environment only.
const stateDir = resolveSettings({ env: process.env, ctx }).values.stateDir;
mkdirSync(stateDir, { recursive: true });
// systemd RuntimeDirectory=videofx -> /run/videofx (mpv socket, temp IR files).
const runDir = process.env.RUNTIME_DIRECTORY || stateDir;
const settings = new Settings({ dir: stateDir, env: process.env, ctx });
const get = (key) => settings.get(key);

// A restore from the web page staged Matter storage: swap it in before matter.js opens it.
await applyStagedRestore(stateDir);

// Matter fabrics, keys and the random pairing passcode live here. Deleting this
// directory (or "Reset Matter pairing" in the web UI) is a factory reset.
Environment.default.vars.set("storage.path", join(stateDir, "matter"));
const appDir = fileURLToPath(new URL("..", import.meta.url));
const currentVersion = readVersion(appDir);

// --- audio, screen, media

const volume = new Volume({
  store: {
    load: () => ({ level: get("volume"), muted: get("muted") }),
    save: ({ level, muted }) => settings.update({ volume: level, muted }),
  },
  apply: (v) => run("amixer", amixerArgs(get("audioCard"), get("mixerControl"), capVolume(v, get("quietHours"), new Date(), { clockOk: clockSynced() }))),
});
// First boot: the safe default; later: the saved level. A missing card is logged, not fatal.
volume.applyCurrent().catch(() => {});

// Console device and ports are read once: changing them needs a restart.
const screen = createScreen(get("console"));
const media = createMediaStore({
  dir: get("mediaDir"),
  playlist: get("playlist"),
  maxUploadBytes: () => get("maxUploadMb") * 1024 * 1024,
});
// Uploads cut short by a crash or power cut would otherwise fill the card over time.
media.cleanTemp().then((n) => n && console.info(`Removed ${n} unfinished upload(s)`), () => {});

// --- GPIO tools (libgpiod 1 on bookworm, 2 on trixie)

let gpiodMajor = null;
try {
  gpiodMajor = gpiomonMajor((await run("gpiomon", ["--version"])).stdout);
} catch {
  console.warn("gpiomon not found: PIR and relay are unavailable (install the gpiod package)");
}

// --- Matter node

const server = await ServerNode.create({
  id: "videofx",
  network: { port: get("matterPort") },
  productDescription: {
    name: get("name"),
    deviceType: DeviceTypeId(OnOffPlugInUnitDevice.deviceType),
  },
  basicInformation: {
    // 0xFFF1 / 0x8000 are the Matter test vendor and product IDs. Controllers
    // accept them but warn that the accessory is not certified.
    vendorName: "DIY",
    vendorId: VendorId(0xfff1),
    productName: "Projector",
    productLabel: get("name"),
    productId: 0x8000,
    nodeLabel: get("name"),
    // Identity stays videofx-xxxx even if the display name is changed.
    serialNumber: ctx.hostName,
    uniqueId: `${ctx.hostName}-plug`, // must differ from serialNumber
  },
});

const plug = await server.add(OnOffPlugInUnitDevice, { id: "projector" });
const scareSwitch = await server.add(OnOffPlugInUnitDevice, { id: "scare" });
// Always present (even with the PIR disabled) so the device layout never changes after pairing.
const motion = await server.add(OccupancySensorDevice.with(OccupancySensingServer.with("PassiveInfrared", "OccupancyEvent")), {
  id: "motion",
  occupancySensing: { occupancy: { occupied: false } },
});
const temperature = await server.add(TemperatureSensorDevice, {
  id: "temperature",
  temperatureMeasurement: { measuredValue: null, minMeasuredValue: -2000, maxMeasuredValue: 12000 }, // 0.01 °C
});

function pairingCodes({ evenIfPaired = false } = {}) {
  if (server.lifecycle.isCommissioned && !evenIfPaired) return undefined;
  const { qrPairingCode, manualPairingCode } = server.state.commissioning.pairingCodes;
  return { qrText: QrCode.get(qrPairingCode).trim(), qrPairingCode, manualPairingCode };
}

// What to show when mpv is not drawing: pairing info until commissioned, then black.
function idleScreen() {
  const codes = pairingCodes();
  if (!codes) return screen.black();
  screen.pairing({ qr: codes.qrText, manualPairingCode: codes.manualPairingCode, name: get("name"), host: ctx.hostName });
}

// --- player

const mpv = new MpvSupervisor({
  spawn,
  command: get("mpv"),
  socket: join(runDir, "mpv.sock"),
  args: () => mpvArgs(settings.values, join(runDir, "mpv.sock")), // re-read on every start
});

const playerState = join(stateDir, "player.json");
// When the power state last changed before this boot (the file is rewritten on
// every change): tells a schedule event that was acted on from one that passed
// while the power was out.
let lastChangeAt = 0;
try {
  lastChangeAt = statSync(playerState).mtimeMs;
} catch {
  // never switched: any past schedule event counts as missed
}
let dmxOverride = {}; // runtime values DMX sets while in control (not saved)
const clipPath = (name) => (name ? join(get("mediaDir"), name) : "");
const scareNames = () => get("scareClips").filter((n) => existsSync(clipPath(n)));

const player = new Player({
  mpv,
  content: () => ({
    mode: dmxOverride.mode ?? get("mode"),
    playlist: get("playlist"),
    buffer: clipPath(get("scareBuffer")),
    scares: scareNames().map(clipPath),
    order: get("scareOrder"),
    cooldownMs: get("scareCooldown") * 1000,
    duringScare: get("scareDuringScare"),
    mirror: get("mirror"),
  }),
  blank: idleScreen,
  store: {
    load: () => {
      try {
        return JSON.parse(readFileSync(playerState, "utf8")).on;
      } catch {
        return undefined;
      }
    },
    save: (on) => writeFileAtomicSync(playerState, JSON.stringify({ on }) + "\n"),
  },
  preflight: () => media.problem({ mode: dmxOverride.mode ?? get("mode"), buffer: get("scareBuffer"), scares: get("scareClips") }),
  gate: (source) => scareBlocked(get("quietHours"), new Date(), { source, clockOk: clockSynced() }),
});

// --- projector power (CEC / relay / IR / HDMI signal)

const relay = new GpioOut({ spawn, argsFor: (closed) => gpiosetArgs(gpiodMajor ?? 2, get("relayPin"), closed, get("relayActiveLow")) });

// The lirc devices for the IR LED and receiver, found by what they can do.
async function lircDevice(kind) {
  for (let n = 0; n < 4; n++) {
    const dev = `/dev/lirc${n}`;
    if (!existsSync(dev)) continue;
    try {
      if (lircFeatures((await run("ir-ctl", ["-f", "-d", dev])).stdout)[kind]) return dev;
    } catch {
      // not ours / no access
    }
  }
  return null;
}
const ir = new Ir({ run, spawn, txDevice: () => lircDevice("send"), rxDevice: () => lircDevice("receive"), tmpDir: runDir });

const projector = new Projector({
  run,
  mode: () => get("projectorPower"),
  device: () => get("cecDevice"),
  osdName: get("name"),
  relay,
  ir,
  settleMs: () => get("relaySettleSec") * 1000,
  irCode: () => get("irPowerCode"),
  doublePress: () => get("irDoublePress"),
  // hdmi-off: fbdev power-down blank turns the HDMI signal off (udev lets the video group write it).
  blank: (powerDown) => writeFile("/sys/class/graphics/fb0/blank", powerDown ? "4" : "0"),
});
await projector.init(); // relay open (projector off) until the restored state is applied

// The HDMI sink: playback waits for it, and starts again if it turns up late.
const DISPLAY_WAIT_MS = 20_000;
const display = new DisplayWatch({ probe: () => displayConnected({ connector: get("videoOutput") }) });
display.on("connected", () => {
  if (!player.isOn) return;
  console.info("HDMI display connected: starting playback again");
  player.reload();
});
display.start();

// --- power

let powerSeq = 0;
async function powerChanged(on) {
  const seq = ++powerSeq;
  if (on) {
    await projector.on(); // wake first (and wait out the relay settle time)
    if (seq !== powerSeq) return; // switched off meanwhile
    // mpv gives a disconnected HDMI output no picture, and a projector that was
    // just powered takes a few seconds to appear.
    if ((await display.wait(DISPLAY_WAIT_MS)) === false) {
      console.warn(`No HDMI display after ${DISPLAY_WAIT_MS / 1000} s: starting anyway; playback starts again when it appears`);
    }
    if (seq !== powerSeq) return;
    player.setOn(true);
  } else {
    // Whatever happens to the player, the projector must still be switched off.
    try {
      player.setOn(false);
      // hdmi-off: the console blank is ignored while mpv still holds the display.
      await player.stopped();
    } catch (err) {
      console.error(`Player stop: ${err.message}`);
    }
    if (seq !== powerSeq) return; // switched back on meanwhile
    await projector.off({ keepSignal: !server.lifecycle.isCommissioned });
  }
}

// Our own writes to the Matter attribute vs. writes from a controller.
const ownWrites = new InternalWrites();
async function writePower(on) {
  if (plug.state.onOff.onOff === on) return powerChanged(on);
  await ownWrites.run(on, () => plug.set({ onOff: { onOff: on } }));
}

// Boot catch-up of a schedule event missed while the power was out (see
// scheduleCatchUp). Any power decision made since boot cancels it.
let catchUp = true;

plug.events.onOff.onOff$Changed.on((on) => {
  if (ownWrites.take(on)) {
    powerChanged(on).catch((err) => console.error(`Power: ${err.message}`));
    return;
  }
  const r = arbiter.request("matter", on);
  // Refused (DMX in control / over temperature): put Matter's attribute back to the truth.
  if (!r.ok) setImmediate(() => writePower(r.actual).catch((e) => console.error(e)));
});

// Matter already changed its attribute; everyone else writes it.
const arbiter = new PowerArbiter({
  dmx: { get inControl() { return dmx.inControl; } },
  actual: () => player.isOn,
  blocked: () => guard.blocked,
  apply: (on, source) => {
    if (source !== "catch-up") catchUp = false;
    const job = source === "matter" ? powerChanged(on) : writePower(on);
    job.catch((err) => console.error(`Power (${source}): ${err.message}`));
  },
});
const requestPower = (source, on) => {
  const r = arbiter.request(source, on);
  if (!r.ok) console.info(`Power ${on ? "on" : "off"} from ${source} refused: ${r.reason}`);
  return r;
};

// The player gave up (no playlist, repeated crashes): report "off" so the
// controller shows the truth. Deferred so we never write inside the change event.
player.on("failed", () => setImmediate(() => writePower(false).catch((e) => console.error(e))));

// --- scares: Matter "scare" switch, PIR, web button

const setScareSwitch = (on) => scareSwitch.set({ onOff: { onOff: on } }).catch((e) => console.error(e));
player.on("scare", ({ state }) => setImmediate(() => setScareSwitch(state === "start")));

scareSwitch.events.onOff.onOff$Changed.on((on) => {
  if (!on || player.scareActive) return; // our own "on" while a scare plays
  const result = player.trigger("Matter");
  // Fired: stays on until the scare ends ("scare" event). Otherwise back off now.
  if (result.result !== "fired") setImmediate(() => setScareSwitch(false));
});

let pir = null;
function startPir() {
  pir?.stop();
  pir = null;
  if (!get("pirEnabled") || gpiodMajor === null) return;
  pir = new Pir({ spawn, args: pirArgs(gpiodMajor, get("pirPin"), get("pirDebounceMs")), debounceMs: get("pirDebounceMs") });
  pir.on("change", (occupied) => motion.set({ occupancySensing: { occupancy: { occupied } } }).catch((e) => console.error(e)));
  pir.on("motion", () => player.trigger("motion sensor"));
  pir.start();
}
startPir();

// --- schedule

// --- clock (no RTC on the Pi 3/4/Zero 2 W): the schedule waits for NTP

let wasSynced = clockSynced();
setInterval(() => {
  const now = clockSynced();
  if (now && !wasSynced) {
    console.info("Clock synchronised: schedule active");
    scheduler.start();
    scheduleCatchUp();
  }
  wasSynced = now;
}, 15_000).unref();

// The schedule only acts at its event times. One that passed while the Pi had no
// power (a cut across "on at sunset") would leave the show dark all night, so it
// is applied once at boot, as soon as the clock is known.
function scheduleCatchUp() {
  if (!catchUp || !clockSynced()) return;
  catchUp = false;
  // The Matter attribute is the intended state; the player lags it while the projector wakes.
  const missed = missedEvent(scheduler.lastEvent(), lastChangeAt, plug.state.onOff.onOff);
  if (!missed) return;
  console.info(`Schedule: ${missed.label} passed while the power was out: turning ${missed.on ? "on" : "off"}`);
  requestPower("catch-up", missed.on);
}

const scheduler = new Scheduler({
  clockOk: clockSynced,
  getSchedule: () => get("schedule"),
  getGeo: () => (get("latitude") !== null && get("longitude") !== null ? { lat: get("latitude"), lon: get("longitude") } : null),
  setPower: (on) => requestPower("schedule", on),
});

// --- DMX (sACN receive): overrides while a source is live

let beforeDmx = null;
let dmxVolume = null; // last DMX volume, re-applied when quiet hours start or end
const dmx = new DmxControl({
  holdMs: get("dmxHoldSec") * 1000,
  act: {
    takeover: () => {
      beforeDmx = { on: player.isOn };
      console.info("DMX in control");
    },
    release: () => {
      dmxOverride = {};
      player.setClip(null);
      player.setDimmer(255);
      volume.applyCurrent().catch(() => {});
      player.reload();
      // Back to the schedule's current wish if it has one, else how it was before DMX.
      const want = scheduler.desiredNow() ?? beforeDmx?.on ?? false;
      console.info(`DMX released control; power ${want ? "on" : "off"}`);
      requestPower("handover", want);
    },
    setPower: (on) => requestPower("dmx", on),
    setMode: (mode) => {
      dmxOverride.mode = mode;
      player.reload();
    },
    setClip: (n) => {
      if (!n) return player.setClip(null);
      media
        .readPlaylist()
        .then((entries) => {
          const entry = entries.filter((e) => e.enabled)[n - 1];
          player.setClip(entry ? join(get("mediaDir"), entry.file) : null);
        })
        .catch((err) => console.error(`DMX clip: ${err.message}`));
    },
    trigger: () => player.trigger("DMX"),
    setVolume: (v) => {
      dmxVolume = v;
      return run("amixer", amixerArgs(get("audioCard"), get("mixerControl"), capVolume(v, get("quietHours"), new Date(), { source: "dmx", clockOk: clockSynced() }))).catch(() => {});
    },
    setDimmer: (v) => player.setDimmer(v),
  },
});
const receiver = new SacnReceiver({ universe: get("dmxUniverse") });
receiver.on("live", (live) => dmx.live(live));
receiver.on("frame", (levels) => dmx.frame(fixtureValues(levels, get("dmxAddress"))));
setInterval(() => receiver.tick(), 250).unref();

let dmxSocket = null;
function startDmx() {
  dmxSocket?.close();
  dmxSocket = null;
  receiver.setUniverse(get("dmxUniverse"));
  dmx.setHold(get("dmxHoldSec") * 1000);
  if (!get("dmxEnabled")) return;
  const sock = dgram.createSocket({ type: "udp4", reuseAddr: true });
  sock.on("message", (msg, rinfo) => receiver.handle(msg, rinfo.address));
  sock.on("error", (err) => console.error(`DMX: ${err.message}`));
  sock.bind(SACN_PORT, () => {
    if (!get("dmxMulticast")) return;
    try {
      sock.addMembership(multicastGroup(get("dmxUniverse")));
    } catch (err) {
      console.error(`DMX multicast: ${err.message} (unicast still works)`);
    }
  });
  dmxSocket = sock;
}
startDmx();

// --- heat: the Pi's own SoC temperature (the case has no fans)

const guard = new OverTempGuard({
  isOn: () => player.isOn,
  powerOff: () => requestPower("thermal", false),
  // Resume: under DMX, whatever DMX asks for; otherwise back on.
  powerOn: () => requestPower("thermal", dmx.inControl ? interpret(dmx.values ?? [0]).power : true),
});
const thermal = new SocWatch({
  cfg: () => ({ warnC: get("tempWarnC"), critC: get("tempCritC"), hysteresisC: get("tempHysteresisC") }),
  guard,
});
let thermalState = { temp: null, alarms: [], locked: false };
let thermalTimer = null;
let stopping = false;

async function thermalTick() {
  try {
    const socC = await readFile("/sys/class/thermal/thermal_zone0/temp", "utf8").then(parseMilli, () => null);
    if (stopping || !get("thermalEnabled")) return; // switched off while reading
    thermalState = thermal.update(socC);
    const value = socC === null ? null : Math.round(socC * 100);
    if (temperature.state.temperatureMeasurement.measuredValue !== value) {
      await temperature.set({ temperatureMeasurement: { measuredValue: value } });
    }
  } catch (err) {
    console.error(`Thermal: ${err.message}`);
  }
}

function startThermal() {
  if (thermalTimer) clearInterval(thermalTimer);
  thermalTimer = null;
  if (!get("thermalEnabled")) {
    // No protection: forget any trip (or it would block power-on for good).
    thermal.reset();
    guard.reset();
    thermalState = { temp: null, alarms: [], locked: false };
    return;
  }
  thermalTimer = setInterval(thermalTick, 5000);
  thermalTick();
}
startThermal();

// --- quiet hours: re-apply the volume when they start or end

let quietActive = null;
setInterval(() => {
  const now = quietNow(get("quietHours"), new Date(), { clockOk: clockSynced() });
  if (now === quietActive) return;
  quietActive = now;
  if (dmx.inControl && dmxVolume) run("amixer", amixerArgs(get("audioCard"), get("mixerControl"), capVolume(dmxVolume, get("quietHours"), new Date(), { source: "dmx", clockOk: clockSynced() }))).catch(() => {});
  else volume.applyCurrent().catch(() => {});
}, 30_000).unref();

// --- OS status for the page: network, power-cut protection

let network = { wifi: { connected: false }, ethernet: false, active: null };
async function refreshNetwork() {
  const out = (cmd, args) => run(cmd, args).then((r) => r.stdout, () => "");
  const [iw, nm] = await Promise.all([out("iw", ["dev", "wlan0", "link"]), out("nmcli", ["-t", "-f", "DEVICE,TYPE,STATE", "device"])]);
  const wifi = parseIwLink(iw);
  network = { wifi: { ...wifi, verdict: signalVerdict(wifi.signalDbm) }, ...parseNmcliDevices(nm) };
}
refreshNetwork();
setInterval(refreshNetwork, 30_000).unref();

let storage = null;
async function refreshStorage() {
  const read = (f) => readFile(f, "utf8").catch(() => "");
  storage = storageStatus({
    procCmdline: await read("/proc/cmdline"),
    bootCmdline: (await read("/boot/firmware/cmdline.txt")) || (await read("/boot/cmdline.txt")),
    procMounts: await read("/proc/mounts"),
    storageState: await read("/var/lib/videofx-storage.state"),
  });
}
refreshStorage();
setInterval(refreshStorage, 60_000).unref();

// --- watchdog: systemd restarts us if the event loop stops pinging

const loopDelay = monitorEventLoopDelay({ resolution: 50 });
loopDelay.enable();
const watchdog = new Watchdog({
  watchdogUsec: process.env.WATCHDOG_USEC,
  // Not under systemd (development): nothing to tell.
  notify: (message) => (process.env.NOTIFY_SOCKET ? run("systemd-notify", [message], { timeout: 5000 }).then(() => {}) : Promise.resolve()),
  healthy: () => {
    const lagMs = loopDelay.max / 1e6;
    loopDelay.reset();
    return lagMs > 5000 ? `event loop blocked for ${Math.round(lagMs)} ms` : null;
  },
});
// --- lifecycle and settings
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

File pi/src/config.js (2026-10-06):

// Every setting: its /etc/default/videofx variable, default, validation and how a
// change takes effect. settings.js layers web-made values (settings.json) on top;
// both paths validate with the parse() functions here.

import { readFileSync } from "node:fs";
import { homedir, hostname, networkInterfaces } from "node:os";
import { isAbsolute, join } from "node:path";
import { checkMpvArgs } from "./mpv.js";
import { parseIrCode } from "./ir.js";
import { RESERVED_GPIOS } from "./pir.js";
import { PROJECTOR_MODES } from "./projector.js";
import { isMediaFile } from "./playlist-core.js";
import { DEFAULT_QUIET, parseQuiet } from "./quiet.js";
import { DEFAULT_SCHEDULE, parseSchedule } from "./schedule.js";
import { clampLevel } from "./volume.js";

const RESTORE_POLICIES = ["last", "on", "off"];

// Words, not a shell: split on whitespace. mpv is spawned without a shell.
const words = (s) => (s ?? "").split(/\s+/).filter(Boolean);

/**
 * Names from the last 4 hex digits of eth0's MAC (wlan0 as fallback): the display
 * name VideoFX-ABCD (Matter, web page, Bonjour) and the hostname videofx-abcd.
 * The first-boot unit sets the hostname the same way, so normally both agree.
 */
export function deviceIds(host = hostname(), ifaces = networkInterfaces()) {
  let hex = /^videofx-([0-9a-f]{4})$/i.exec(host)?.[1];
  for (const name of ["eth0", "wlan0"]) {
    if (hex) break;
    const mac = ifaces[name]?.find((a) => a.mac && a.mac !== "00:00:00:00:00:00")?.mac;
    if (mac) hex = mac.replace(/:/g, "").slice(-4);
  }
  if (!hex) return { display: host, host: host.toLowerCase() };
  return { display: `VideoFX-${hex.toUpperCase()}`, host: `videofx-${hex.toLowerCase()}` };
}

export const deviceName = (host, ifaces) => deviceIds(host, ifaces).display;

const text = (re, why, max = 64) => (v) => {
  if (typeof v !== "string") throw new Error("must be text");
  const s = v.trim();
  if (s.length > max || !re.test(s)) throw new Error(why);
  return s;
};

const int = (min, max) => (v) => {
  const n = typeof v === "string" && v.trim() !== "" ? Number(v) : v;
  if (typeof n !== "number" || !Number.isInteger(n) || n < min || n > max) {
    throw new Error(`must be a whole number from ${min} to ${max}`);
  }
  return n;
};

const bool = (v) => {
  if (v === true || v === "true" || v === "1") return true;
  if (v === false || v === "false" || v === "0") return false;
  throw new Error("must be true or false");
};

const oneOf = (options) => (v) => {
  if (!options.includes(v)) throw new Error(`must be one of ${options.join(", ")}`);
  return v;
};

const coord = (max) => (v) => {
  if (v === "" || v === null) return null;
  const n = typeof v === "string" ? Number(v) : v;
  if (typeof n !== "number" || !Number.isFinite(n) || n < -max || n > max) throw new Error(`must be a number from -${max} to ${max}, or empty`);
  return Math.round(n * 1e4) / 1e4;
};

// BCM GPIO on the 40-pin header, not one the DigiAMP+ (or the ID EEPROM) uses.
const gpioPin = (v) => {
  const n = int(2, 27)(v);
  if (RESERVED_GPIOS.includes(n)) throw new Error(`GPIO${n} is used by the DigiAMP+ or reserved; pick another`);
  return n;
};

const PIN_ROLES = {
  pirPin: "PIR",
  relayPin: "relay",
  irTxPin: "IR LED",
  irRxPin: "IR receiver",
};

/** Cross-setting check: one role per pin, and warn below critical. Returns an error message or undefined. */
export function checkPins(values) {
  const seen = new Map();
  for (const [key, role] of Object.entries(PIN_ROLES)) {
    const pin = values[key];
    if (pin === undefined) continue;
    if (RESERVED_GPIOS.includes(pin)) return `${role}: GPIO${pin} is used by the DigiAMP+ or reserved`;
    if (seen.has(pin)) return `GPIO${pin} is set for both the ${seen.get(pin)} and the ${role}`;
    seen.set(pin, role);
  }
  if (values.tempWarnC !== undefined && values.tempCritC !== undefined && values.tempWarnC >= values.tempCritC) return "the warning temperature must be below the critical one";
  return undefined;
}

const absPath = (v) => {
  if (typeof v !== "string" || !isAbsolute(v)) throw new Error("must be an absolute path");
  return v;
};
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

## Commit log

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2026-09-28 feat(case): screw the lid through its skirt, no roof penetrations
    Replaces the four full-height posts with 45-degree blocks in the base wall
    tops; slotted skirt holes and spacer rings.
    [base_front.stl, base_rear.stl, lid_front.stl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]
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2026-09-28 feat(case): light-cone check, high 4x5 window, plug clearance, fit coupon
    Window clears +/-12 deg tilt for a 1.4:1 projector; rear gap sized for
    right-angle plugs. Adds printing plan with sliced times, BOM, assembly
    guide, cord-joint warning, and a tag-triggered release job. STLs move
    from git to release assets.
    [base_front.stl, base_rear.stl, hatch_cover.stl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]
2026-09-28 fix: single version, tripod at computed centre of mass, hatch lock; docs
    Pi package now 0.8.1 to match the tag. Adds bring-up checklist, ordering
    plan with rough costs, V-0 filament and cord-routing guidance, and
    refreshed previews.
    [projector_pi_case.scad]
2026-09-28 fix(pi): image build stages app files outside the chroot's /tmp tmpfs
    pi-gen mounts a fresh tmpfs over /tmp in on_chroot, hiding the copied
    files; stage under /var/tmp. Also remove a stale pigen_work container so
    a failed build doesn't block the next. First full image build succeeds.
2026-10-05 fix(case): HDMI pass-through, floor-edge ribs, rebate ceiling, gland height, bed-fit asserts
    The clash script only checks what is modelled, and no cable was:
    - Divider pass-through opens down to the sled and spans every board's
    HDMI port (pass_x). The Pi's HDMI edge sits 9.5 mm behind the divider,
    so a plug could not go in. pi_hdmi_plug is a keep-out, checked by new
    hdmi-pi3/4/5 pairs in check_clash.sh.
    - Outer foot ribs sit under the side walls at any case width (ribs_x);
    they stopped 5.5 mm short, leaving a full-length strip of floor
    printing in mid-air. Longest bridge asserted against max_bridge.
    - Pane rebate ceiling is 45 deg instead of an unsupported 128 mm edge.
    - Gland ent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
    [projector_pi_case.scad]
2026-10-06 fix(pi): first-boot partitioning, thermal safety paths, HDMI wait, mpv allow-list, schedule catch-up
    Software review fixes; nothing has run on a Pi yet. All 480 tests pass.
    First boot:
    - videofx-storage used "parted -s resizepart" on the mounted root, which
    asks a question and fails in script mode (confirmed in a trixie
    container); it now uses sfdisk. Data mounts get nofail, and the unit
    waits for Pi OS's own first-boot jobs before rebooting.
    Thermal safety:
    - No projector-zone reading for 60 s while playing trips protection.
    - A failed state save no longer aborts power-off.
    - The relay opens whenever the service stops (clean stop in the service,
    videofx-relay-open as ExecStopPost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
    [config.js, gpio.js, main.js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]
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2026-10-06 feat(case): size the case to the Tkisko TO2 and add a measurement worksheet
    Projector is now 165 x 130 x 66 (depth measured, rest from the manual),
    lens on the long face offset left, socket right of centre, throw 0.95.
    The wider body misses the bed the old way round, so the front tiles print
    end-on (231 x 207 base, 228 x 204 lid) and the lid seam moves to 200 mm
    (lid_front_len). Front/rear gaps 30/34, hatch 108 mm centred 56 up so its
    hood clears the lower lid skirt, front lid screw behind the window frame.
    Pan gets its own limit (pan_max 10) because the short-throw cone clips the
    window frame; combined corner is 8 (rear plugs reach the divider).
    Label reads DC 21 V 3 A: docs switch the fan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
    [measurements.xlsx, projector_pi_case.scad]
2026-10-06 docs: record the projector's EDID findings
    Read on a MacBook: generic STK "S2-TEK TV" block, 1080p60 native, 8-bit,
    150 MHz TMDS, 2-ch LPCM, DPMS standby flags, HDMI vendor block with CEC
    physical address 2.0.0.0. Proves a real HDMI input, not CEC; bring-up
    row 9 on the Pi still decides. Adds a Mac-side signal-loss standby test
    (row 2a) and the projector's native mode for the video= workaround.
    [projector_pi_case.scad]
2026-10-06 docs(measurements): add the missing hardware, consumable and site rows
    The worksheet covered the projector body, lens, socket, ports, throw,
    ball head, brick, Pi stacks, PIR, pane and inserts but not the things the
    hatch and holders must reach, the parts that go on the shelf, the
    consumables with a parameter behind them, or the yard itself.
    - Projector: port X positions, barrel plug size, lens protrusion and
    bezel, focus/keystone heights, IR receiver position, vent extents,
    foot height, flat area around the socket.
    - Ball head: stud length, platform diameter, base thread, knob size and
    reach.
    - DC brick: cable lengths, fuse holder, relay and splice footprints.
    - Pi stack: hdmi_plug di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
    [measurements.xlsx, projector_pi_case.scad]
2026-10-06 feat(power): receptacle plate on the shelf for the stock wall-wart and a second one
    The projector's stock supply turned out to be a wall-wart (MX48CC-210228US,
    AC 100-240 V 1.0 A in, 21 V 2.28 A / 48 W out, centre-positive, 2-pin
    prongs, captive DC cord), not a corded brick with an IEC inlet, so the
    gland-to-IEC-to-brick chain could not be used. Owner chose to keep mains
    inside, with a second wall-wart (24 V) for the Pi, Amp4 and fans.
    - power_shelf: the brick cradle is replaced by a plate 30 mm off the rear
    wall carrying two panel-mount NEMA 5-15R snap-in cutouts (Qualtek
    738W-X2/01, 26 x 22, pocketed to 2 mm), one above the other; the
    wall-warts hang on their prongs standing on thei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
    [measurements.xlsx, projector_pi_case.scad]
2026-10-06 fix(lid): keep the scarf cutting polygon simple so CGAL exports the lid tiles
    With the Pi zone 10 mm deeper the seam constant c in lid_tile() went from
    +0.3 to -4.95, which put the parallelogram's second vertex left of its
    first and made the polygon self-intersecting. The manifold backend used
    locally tolerated it; the CGAL backend on CI's apt OpenSCAD refused with
    "The given mesh is not closed" on lid_front and lid_rear. The region is
    now a trapezoid with the 45 deg edge on the right, valid for any c.
    Verified with --backend=CGAL on both tiles and the whole lid, make parts
    and all 25 clash pairs.
    [projector_pi_case.scad]
2026-10-06 docs(wiring): add high- and low-voltage wiring diagrams
    Replace the single overview flowchart in docs/WIRING.md with one
    conductor-level Mermaid diagram per side of the barrier: the AC side
    (GFCI, cord, gland, live-only fuse, IEC connector, brick, with L/N/E
    coloured) and the low-voltage side, drawn as the 21 V rail (fuses, Wago
    splice, relay in the + line, Amp4, fans) and the Pi header signals (pin
    numbers, pull-ups, the IR LED transistor driver).
    Also correct the Pi README's fan wiring, which still said 12 V fans on a
    12 V feed; the rail is 21 V and the fans are 24 V parts, as in BOM.md
    and WIRING.md.
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2026-10-06 docs(measurements): add XY shrink and insert-length rows
    Shrink cancels between printed parts but not where a print wraps a rigid
    one: the pane rebate is pane + 2 x clearance, so 0.3 % along the 127 mm
    pane uses up the whole 0.3 mm. A new Fit coupon row takes the coupon's
    118 mm strip length; two computed rows turn it into a shrink percentage
    and the pane clearance per side after shrink, flagged TIGHT under 0.1.
    The summary count includes TIGHT.
    Inserts gains the four insert lengths (insert38_len, insert_len, M4,
    M3) with the model's hole depths in the notes. BRINGUP step 1 asks for
    the strip measurement.
    [measurements.xlsx]
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2026-10-06 Size the window for a 2 mm acrylic pane
    pane_t 3.2 -> 2; rebate, frame depth and snap-out ribs derive from it.
    BOM, CLAUDE.md and the design log updated.
    [projector_pi_case.scad]
2026-10-06 Review fixes: louver slots inside caps, baffle to floor, stale worksheet and docs
    air_n floors (9 and 6 slats) with extent asserts, baffle runs to the floor,
    in_right dropped, measurements.xlsx repointed to the airflow parameters,
    v0.10 labels, HDMI/DC plug and IR holder assembly notes, upgrade note.
    [measurements.xlsx, projector_pi_case.scad]
2026-10-06 Use 3.5 x 5 in picture-frame glazing for the window pane
    pane_h 101.6 -> 88.9, the smallest common size the light cone clears
    (5 x 3 and 4 in widths fail; 6 x 4 clashes the base). BOM now sources a
    frame's acrylic glazing; docs updated.
    [projector_pi_case.scad]
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2026-10-06 Lower cone_tilt to 11 deg for the 3.5 x 5 in window
    The smaller window only just cleared 12 deg; CI's OpenSCAD found a
    sliver the local build missed.
    [projector_pi_case.scad]
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2026-10-06 Add a hot-shoe receiver to the fit coupon
    hot_shoe_cut() and shoe_* parameters (ISO 518, unverified against the
    UTEBIT adapter) plus a T-slot block on fit_coupon. The pedestal is
    unchanged; if the slot holds, it could replace the stud and 1/4-20 insert.
    [projector_pi_case.scad]
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2026-10-06 Remove DC rail fuses; keep the AC live fuse
    Each wall-wart is current-limited and short-circuit protected, and its
    output is well below what the 18 AWG leads carry.
    Claude-Session: https://claude.ai/code/session_01UwAjdXLV4uVzkvtDxbgXit
    [projector_pi_case.scad]
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2026-10-08 Rear wall: cord opening and two-piece cord clamp replace the PG9 hole
    [projector_pi_case.scad]
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2026-10-08 Worksheet and docs: retire stale wall-wart/fuse/gland rows, fix BOM and print totals
    [measurements.xlsx]
2026-10-08 Docs: record the single-brick decision and the accepted safety changes
    Deliberate remaining grep hits: docs/BOM.md line 11 (removed-parts note) and the v0.10 header comment in projector_pi_case.scad name PG9 as replaced.
2026-10-08 Final review fixes: unassemblable provisional layout flagged, M3 x 16 clamp screws, clamp grip hedged with remedies, spec/BRINGUP/WIRING/diagram consistency
    [projector_pi_case.scad]
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2026-10-12 Power: Auplf 24 V 6 A supply and 14 AWG Y-splitter
    Replace the provisional Parts Express 24 V 5 A brick with the Auplf
    XGM-2406 (24 V 6 A, 5.5 x 2.5 mm, 170 x 71 x 41 mm; FCC/CE only, no
    UL/ETL, accepted by the owner). `brick` envelope updated from the
    listing. Y-splitter changed to a 14 AWG 2-pack because the first pick
    was rated 3 A main / 2 A branches. Owner verified the projector and
    DigiAMP+ jacks are both 5.5 x 2.5 mm. BOM, WIRING, design log, CLAUDE.md
    and the wiring diagrams updated; check_clash.sh passes.
2026-10-12 Fix brick fit and check_clash false pass; M5 hatch bolts
    - check_clash.sh counted "empty" output as ok, so a failed model assert
    made every check pass vacuously. Report ERROR first.
    - The 170 mm brick (387d5ca) broke the brick/PIR assert; move pir_x
    55 -> 76 so it fits. make parts and all 26 checks pass.
    - Hatch bolts M4 -> M5 button head (stud_d, stud_head_d,
    stud_insert_d); keyholes, insert holes and bosses resized, docs and
    BOM updated.
2026-10-13 Pi: follow the login user on first boot; custom hostnames
    Imager's first-boot user can rename or replace the image's "videofx"
    account, leaving videofx-player.service with User=videofx and failing with
    217/USER. New videofx-user renders the unit for the uid 1000 login user; it
    runs from videofx-storage after cloud-init, setup.sh and videofx-update.
    videofx-hostname now honours a hostname from Imager's user-data (stock names
    and invalid values are ignored), or `videofx-hostname NAME` / `--auto` later.
    deviceIds uses a custom hostname for the Matter, web and Bonjour names.
    Bump to 0.8.3.
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2026-10-14 Pi upgrade helper: lock out after repeated wrong passwords, write update-check.json by rename
    Five wrong guesses lock the root helper for five minutes (counted across
    connections, since the socket is open to local users). update-cli check now
    writes a fresh temp file and renames it over the target, so a symlink planted
    in the service-owned state folder is replaced, not followed by root.
2026-10-14 Pi upgrade: page password authorizes it, Pi login password only as fallback
    Follows Home Assistant's pattern: the web layer authenticates, a privileged
    helper does the work. With a page password set, that login authorizes the
    upgrade. Without one, the Pi login password is asked and checked by the root
    helper, with wrong guesses limited per client address in the web layer. The
    helper socket is now 0600 and owned by the service account (rendered by
    videofx-user), and the global lockout is gone.
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2026-10-14 Pi: count password guesses per client address
    One global token bucket let a device spamming wrong passwords block new
    logins for everyone. The bucket is now per client address (web guard and
    the current-password check pass req.socket.remoteAddress), capped at 256
    buckets with least-recently-used eviction. security.md notes that IPv6
    address rotation within the subnet limits how much this helps.
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2026-10-15 Releases: GitHub Actions attestations replace the owner's SSH signature
    CI attests every release file with actions/attest-build-provenance (Sigstore),
    attaches the bundle to the Pi tarball as .sigstore.json and publishes the
    release. The Pi checks the bundle with the sigstore npm package
    (src/verify-release.js): signature and Rekor entry, signer = this repo's
    build.yml on a v* tag, sha256 in the statement, tag = the tarball's version.
    Drops tools/sign-release.sh and system/allowed_signers. Pis on 0.9.x move
    once with --tarball --no-verify. Bump to 0.10.0.
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2026-10-15 Docs: record first fit-coupon results
    M5 hatch fit (keyhole and insert), M3 insert and the pane slot fit as
    modelled; no tolerance changes. Fix the stale m4_insert_d name in
    BRINGUP row 1 (now stud_insert_d).
2026-10-15 Docs: fit-coupon test and adjust guide in PRINTING.md
    One table per coupon feature: how to test, what a good fit is, and
    which parameter to change. Notes that the pilot and M3 hole sizes are
    literals and that clearance is not on the coupon. BRINGUP row 1 and
    ASSEMBLY step 1 link to it; row 1 now names the right parameters.
2026-10-15 Pi: explain a missing sound card instead of amixer's "Invalid card number"
    Before setting the volume, check /proc/asound/cards for the configured card.
    If it is missing, the error lists the cards the Pi does have and says what to
    check: the DigiAMP+ is seated and powered, the rpi-digiampplus overlay is set,
    or the card name in Settings > Audio.
2026-10-15 Pi: the DigiAMP+ card id is DigiAMP, not RPiDigiAMP
    ALSA builds a card id from the last word of the card name, so "RPi DigiAMP+"
    becomes DigiAMP (aplay -l on the Pi: "card 0: DigiAMP [RPi DigiAMP+]"). The
    wrong id broke amixer (no volume) and mpv's audio device (no sound). Fix the
    default, asound.conf, docs and help, and move a saved "RPiDigiAMP" to
    "DigiAMP" when settings load.
2026-10-15 Measurements: YAML plus a check script instead of the spreadsheet
    docs/measurements.xlsx had drifted from the model because each default
    was a copy. docs/measurements.yaml holds only measured values, specs,
    tolerances and notes as comments; scripts/check_measurements.py reads
    each default from projector_pi_case.scad, flags UPDATE / UPDATE (spec),
    and computes throw ratio, lens offset, XY shrink, pane clearance, image
    width and the site tilt. Stale values fixed on the way (3.5 x 5 in 2 mm
    pane, M5 inserts, ball head 52/32, cone_tilt 11, Auplf 144 W brick,
    reach and height notes). Docs and SCAD comments now point at the YAML.
2026-10-15 Pi sled fan: 30 mm fan on the Pi 3/4 sleds, kernel gpio-fan on GPIO 26
    The Pi tripped its over-temperature protection on a warm day running
    outside the case. The DigiAMP+ covers the SoC, so the fan stands at the
    board's SD-card end on an upright sled plate and blows into the Pi-HAT
    gap over a heatsink. The case itself stays fanless.
    - Model (v0.11): pi_fan params, fan plate with a diamond intake on the
    pi3/pi4 sleds, pi_fan keep-out, asserts, fan-pi3/fan-pi4 clash pairs
    - Pi: gpio-fan overlay in setup.sh (on at 60 C), VIDEOFX_FAN_GPIO and
    VIDEOFX_FAN_ON_C (file only), pin/role check, fan state on the
    Dashboard via readFanState; gen-default.mjs looked for the old
    "Fixed" group, so it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
2026-10-15 Pi web page: now-playing header on every screen, dashboard tiles link to setup
    A sticky header shows the clip on screen (poster frame, name, elapsed time
    and length, progress bar) with a Play/Stop button; tapping it opens the
    Dashboard. /api/status gains `now` (path, time-pos and duration read from
    mpv, bounded at 500 ms) and /api/poster/<name> serves a frame grabbed once
    per clip by a niced, short-lived mpv and cached under the state folder.
    Dashboard tiles open Settings > Projector, Schedule, the networks guide and
    Settings > Cooling.
2026-10-15 Pi: SSH login banner with system info; plain update checks before rebooting
    videofx-motd (installed as /etc/update-motd.d/20-videofx) shows the version,
    board, uptime, SoC temperature and throttling, memory, root protection, data
    partition, addresses, player state and the last update check. It replaces
    overlayroot's raw mount listing.
    A plain videofx-update now asks GitHub for the latest release before switching
    maintenance mode on, so an up-to-date Pi is no longer rebooted twice for
    nothing (and the reason, logged only to the RAM journal, lost).
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2026-10-16 Pi banner: print printable ASCII only, header line included
    The control-character filter missed C1 controls (raw 0x9B or UTF-8 U+009B is a
    CSI on some terminals). The banner is ASCII, so whitelist instead.
2026-10-16 Pi health log: temperature and failure indicators over time
    The journal lives in RAM under the read-only root, so the service now keeps
    its own log on the data partition (/var/lib/videofx/health.jsonl):
    - a sample every minute: hottest SoC reading, fan, vcgencmd throttle flags
    (under-voltage, capped, throttled, soft limit), Wi-Fi signal, on/off,
    marked while the clock is unsynced;
    - events on change: Pi started / service restarted / stopped, under-voltage
    and throttling start/end (and since-boot flags at start), temperature
    warning / cut-off / normal, Wi-Fi and HDMI lost/back, mpv crashes,
    playback stopped, event loop blocked.
    Plain appends (a line cut short by a power cut is ski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
2026-10-16 Pi web page: setup checks on the dashboard
    A pass/fail list that runs 30 s after start-up and from a "Run checks"
    button: board, DigiAMP+ sound card, projector on HDMI (name and preferred
    mode from the EDID), whether the projector answers CEC (one read-only
    power-status request; relay modes skip it), motion sensor seen since
    start-up, under-voltage, SoC temperature, network, NTP and videos.
    Anything that can't be read is "not sure yet", never a failure. Problems
    get a fix and a link, a red dot on Dashboard and a health log line.
    Logic is pure (src/selfcheck.js) with tests; dev-web.mjs shows a mix.
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2026-10-16 Pi: USB stick import and an automatic first playlist
    Plug in a USB stick and its video and audio files (any folder depth,
    macOS "._" copies and hidden folders skipped, repeated names once) are
    copied to the media folder and become the playlist, which plays in loop
    mode. udev starts videofx-usb@.service, whose root helper mounts the
    stick read-only under /run/videofx-usb; the service polls for it.
    First web uploads build the playlist too, while it is empty or holds
    only the built-in test clip. A #VIDEOFX-AUTO line in the .m3u keeps it
    automatic until it is saved by hand.
    The Media screen shows the import's progress. Untested on a Pi:
    BRINGUP row 7a.
    Closes #39 (reduced scope: no auto-sort,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
2026-10-21 pi: bump vite to 8.3.5 (launch-editor advisories)
    npm audit fix: vite 8.3.1 -> 8.3.5 and its rolldown/postcss/nanoid deps,
    all dev-only (vitest). Clears GHSA-698v-4r3x-3vcv, GHSA-r825-w8mm-5pxw
    and GHSA-587h-7wmj-h5pm. Nothing that ships to the Pi changes.
    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
2026-10-21 PRINTING: re-slice the ASA tiles with slicer/asa_tiles.ini
    base_front 51 h 18 m / 744 g, base_rear 24 h 8 m / 328 g, lid_front
    12 h 18 m / 198 g, lid_rear 7 h 39 m / 124 g; total about 108 h and
    1.46 kg ASA, so a third ASA spool for a failed base_front. Sliced with
    PrusaSlicer 2.7.2 and the stock MK3S / 0.20mm SPEED / Prusament ASA
    profiles; its stock times match the table within 11 min.
    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
2026-10-21 Mouse ears on the lid tiles; lid_front gets the narrow brim
    ears_lid(t): 2-layer, 18 mm discs in the roof plane at each lid tile's
    roof corners (the lid prints roof-down), reaching into the lid; the
    seam pair sits where the scarf meets the roof top and lid_tile trims it.
    Both lid tiles become 246 mm wide (asserted against the bed). The scarf
    constant moves into lid_scarf_c() so lid_tile and the ears share it.
    lid_front is 204 mm on the bed's 210 mm axis, so the 5 mm brim from
    asa_tiles.ini did not fit: slice.sh now loads asa_base_front.ini
    (1.5 mm brim, no skirt) for lid_front too. Re-sliced: lid_front
    9 h 49 m / 215 g, lid_rear 6 h 2 m / 137 g.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
2026-10-21 v0.14: 4 mm window ribs (win_rib_t)
    PrusaSlicer flagged base_front as a thin fragile part. Bisected to the two
    0.8 mm window ribs (73 mm tall, held only at the sill). 1.6 and 2.4 mm
    still trip it, as did an X-braced truss in the pane rebate; 4 mm clears
    it. The ribs are now cut out at the sill instead of snapped out.
    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
2026-10-25 PETG for every part: drop ASA from slicer settings, scripts and docs
    slicer/tiles.ini and front_tiles.ini replace the ASA tile files; every
    part slices as PETG. DESIGN_LOG keeps the history. Print times to follow.
    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
2026-10-29 Shelf vent slots for the sled fan; sled goes in before the shelf
    The shelf spans the whole Pi zone, so the sled fan's air had no way up
    to the Pi vent above it. Eight 4 x 17 mm slots between the brick's right
    end and the ledge, under the vent (shelf_vent). base_rear is unchanged.
    ASSEMBLY.md: Pi sled is now step 9 and power step 10, since the shelf
    covers the sled and the sled can't drop in with its cables plugged.
    Assembly stages and render_assembly.sh cameras follow; step images
    swapped until re-rendered.
    Claude-Session: https://claude.ai/code/session_015LRGjj23nCtkkWmVmHrjao
2026-10-29 Re-render assembly steps 9 and 10 for the sled-before-shelf order
    Step 9 (Pi sled) no longer shows the cord clamp; step 10 (power) shows
    the shelf with its v0.20 vent slots.
    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
2026-10-30 Projector on its stock 21 V wall-wart for 2026; row 4a failed
    The first projector shut off after running on the brick's 24 V inside
    the case and would not power on again, even from its stock supply.
    The backup runs from the stock wall-wart (DC cord through the cord
    clamp, relay in a short extension); the brick feeds only the DigiAMP+.
    Update WIRING (two supplies, schematic redrawn), BRINGUP, BOM,
    ASSEMBLY, DESIGN_LOG, README, CLAUDE.md.
    Claude-Session: https://claude.ai/code/session_015LRGjjJdfcYVZ63zA99aj9
2026-10-30 v0.21: cut the power shelf's zip-tie slots again
    Since v0.19's calipered brick (right end at +66) the filter x > brick end + 6
    dropped every slot in -70..70, so the shelf had none. Five pairs now sit in the
    strip ahead of the brick, where the Y-splitter and leg 1 run to the divider
    pass-through, derived from leg 2's elbow and the brick's right end (tie_x),
    short of the v0.20 vent slots; asserted clear of the strap slots and vents.
    DESIGN_LOG, PRINTING, WIRING, ASSEMBLY step 10 and CLAUDE.md updated.
    Claude-Session: https://claude.ai/code/session_015LRGjm5j5mqfeVDzCZYf6K
